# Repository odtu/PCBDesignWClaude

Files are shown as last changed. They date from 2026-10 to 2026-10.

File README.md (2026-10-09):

# PCBDesignWClaude: Inductive Absolute Encoder (branch `inductive-encoder`)

This branch holds a separate KiCad project from `main` (the 3-phase ESC): a contactless **absolute inductive rotary encoder**. It was designed with Claude Code and the PowerLab KiCad Assistant, after TI's **TIDA-010961** reference design ([TIDUFF8](https://www.ti.com/lit/pdf/tiduff8)).

- **Sensing:** dual-track Nonius coils, 16 and 15 periods, in a Ø58 mm coil area. The absolute angle comes from the phase difference between the two tracks.
- **Electronics:** 2 × LDC5072-Q1 inductive front ends, 2 × TLV9062 op-amps, an MSPM0G3507 MCU (both ADCs sample simultaneously) and a REF35330 3.3 V reference.
- **Power and interface:** 12–24 V input to an LMR51610 buck, then the TPS70950 and TPS70933 LDOs. The host connection carries UART at 2.5 Mbaud, SYNC and SWD.
- **Rules and parts:** the design follows the [METU PowerLab PCB design rules](https://github.com/odtu/Powerlab/blob/master/KiCAD/PCB_DESIGN_RULES.md) and uses parts from [PowerLabKiCadLibraries](https://github.com/odtu/PowerLabKiCadLibraries).

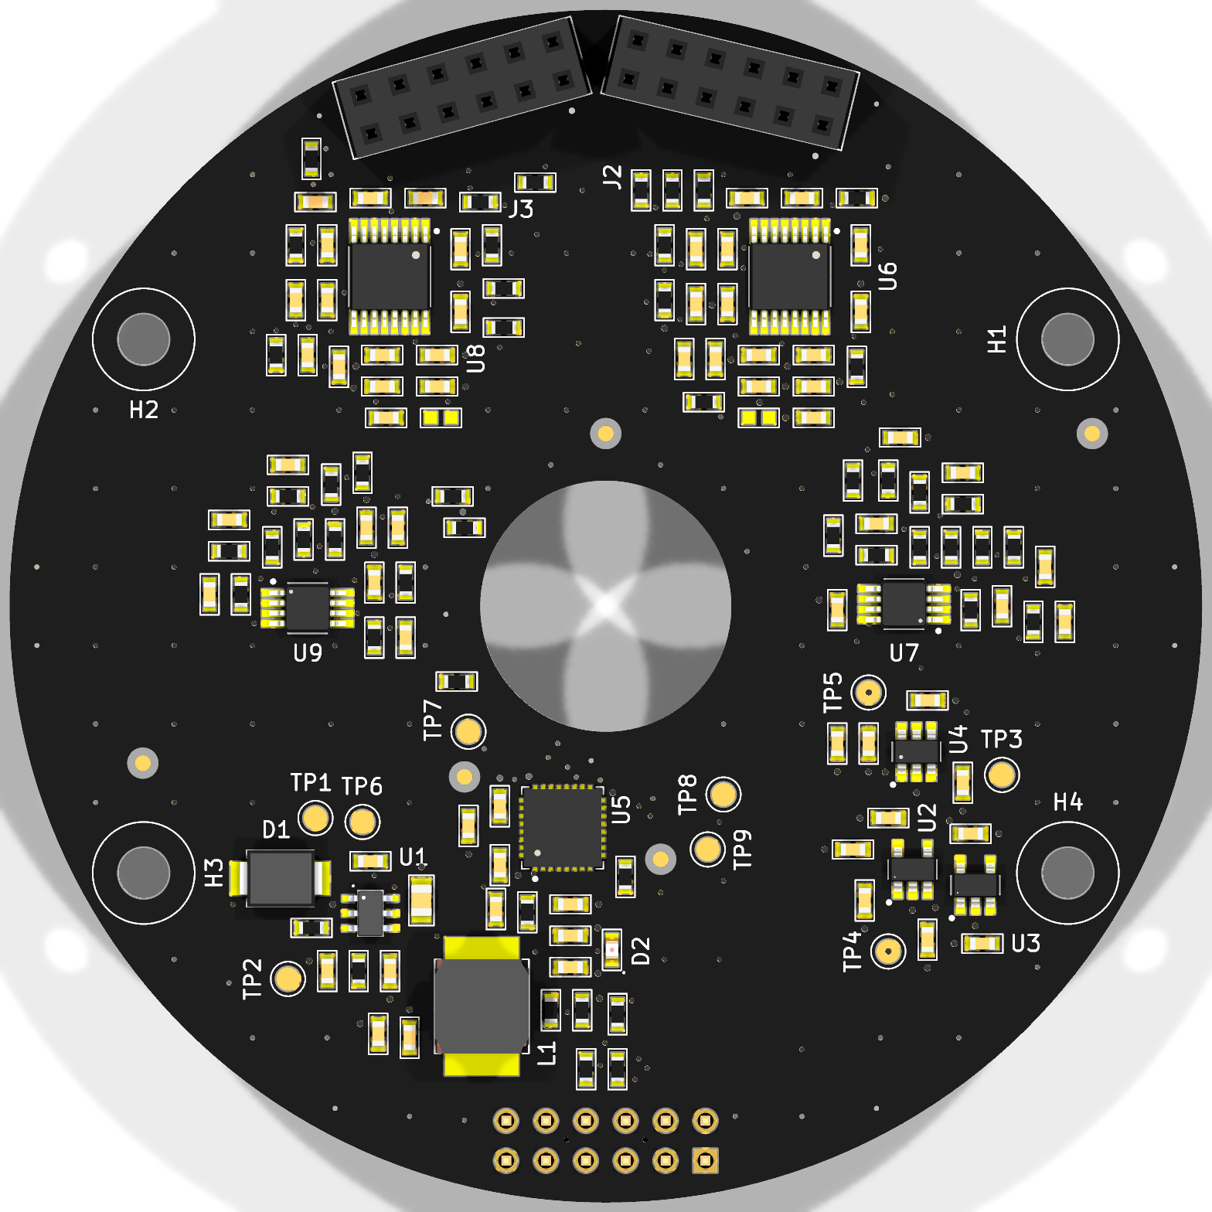
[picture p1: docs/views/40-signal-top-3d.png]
Signal board, top


## Boards

The stack is the same as TI's: the target, a 0.5 mm air gap, the stator, then the 2×6 board-to-board headers, then the signal board.

| Board | Files | |
|---|---|---|
| Stator (coil board) | `InductiveEncoder.kicad_pro` | Ø76 mm, 4 layers. Generated coils, net ties, J2/J3 male headers on the bottom. No GND copper, so nothing acts as a shorted turn. |
| Signal board | `signal/EncoderSignal.kicad_pro` | Ø76 mm, 4 layers, the same M3 holes. All electronics. J2/J3 sockets on top, J1 host connector on the bottom. |
| Target | `target/EncoderTarget.kicad_pcb` | Ø56 mm, 2 layers, copper segments. It rotates with the shaft. |

## Status

- **Schematics:**
  - Hierarchical, on the PowerLab drawing sheet.
  - ERC: 0 errors.
  - PDFs: [docs/schematic_signal.pdf](docs/schematic_signal.pdf), [docs/schematic_stator.pdf](docs/schematic_stator.pdf).
- **Boards:**
  - DRC on both: 0 errors, 0 unconnected, 0 schematic-parity issues.
  - Remaining warnings: footprint-library mismatches (mask bridges allowed inside the fine-pitch ICs), one J1 silk circle near the edge, one narrow pour neck.
- **Fab outputs** in [fab/](fab/): Gerber and drill zip, BOM, position file and assembly drawings for each board.
- **Routing:**
  - The signal-board routing was reworked after [odtu/PowerLabKiCadAssistant#21](https://github.com/odtu/PowerLabKiCadAssistant/issues/21).
  - The resulting rules are proposed in odtu/Powerlab#147 and odtu/PowerLabKiCadAssistant#22. See "How the signal board was routed" below.

Before ordering:
- Add teardrops (Edit → Edit Teardrops; KiCad has no scripting API for them), then rerun `tools/fab_outputs.py`.
- Set the project number (`${PROJECTNUMBER}` is `TBD` in `tools/lab_setup.py`).
- Replace C4/C5 (22 µF 0603, 10 V) on the 6.1 V rail with 16–25 V parts. At 6.1 V they lose most of their capacitance to DC bias.
- The round boards need a panel for PCBWay assembly.
- There's no reverse-polarity protection: use a keyed cable.
- Firmware isn't part of this project.

## How the signal board was routed

`tools/route_signal.py` runs this chain on the placed board:

1. **`fanout.py`:**
   - **GND:** the pours connect the GND pads. A via goes at the pad only for decoupling caps and fine-pitch IC GND pins. Pads the pour can't reach got a via after routing.
   - **Fine-pitch power pins:** 0.25 mm neck-downs.
   - **Escape lanes:** kept free in front of fine-pitch pins.
2. **`power_route.py`:** the rails come first, at the 0.5 mm Power class width. Freerouting 2.4.1 ignores net-class widths.
3. **`autoroute.py signal`:** Freerouting 2.4.1 (Java 25) routes the signals. GND and the rails are keepouts, and the In1 GND plane is a plane layer.
4. **`maze_route.py`:** a grid A* router finishes what is still open. `ripup.py` frees a congested pin row first when needed.
5. **`track_opt.py`:**
   - Shortcuts detours with 45° segments and chamfers every corner of 90° or less.
   - Ends tracks straight at the pad centre.
   - Removes stubs and duplicates.
   - Widens Power/GND tracks to class width, with a 0.15 mm minimum for everything.

Afterwards, the finishing scripts add the rest:
- `zones.py signal`: the GND pours, slotted at 90° so they don't form a closed ring around the shaft;
- `lab_extras.py`: the stitching vias, the local fiducials at the MCU and the J1 labels;
- `silk.py` and `board_info.py`: the silkscreen and the board info.

The whole regeneration sequence, from coils and schematics to fab outputs, is in [docs/DESIGN_NOTES.md](docs/DESIGN_NOTES.md#regenerating).

## Repository layout

```
InductiveEncoder.kicad_*      stator project (root sheet + coils.kicad_sch)
signal/                       signal-board project (7 sheets)
target/                       target disc
tools/                        Python generators and layout/routing scripts (KiCad 10 python / system python)
fab/<board>/                  ordering files (Gerber+drill zip, BOM, pos, assembly PDFs)
docs/                         schematic PDFs, views, design notes
METUPowerLab_KiCadSchematicTemplate.kicad_wks   lab drawing sheet (also in signal/)
```

## Opening and regenerating

- **KiCad 10.**
  - The schematics and boards carry embedded copies of every symbol and footprint, so the project opens without extra libraries.
  - The new parts are in [odtu/PowerLabKiCadLibraries#13](https://github.com/odtu/PowerLabKiCadLibraries/pull/13): LDC5072, MSPM0G3507, TLV9062, REF35330, TPS709xx, the 2×6 header and socket, and some passives. That PR is not merged yet.
- **Generated files:** the `.kicad_sch` files are generated by `tools/encoder_circuit.py`, and the stator coils by `tools/coilgen.py`. Edit the scripts, not the generated sheets.
- **Tool paths:** some scripts have local paths you'll need to change on another machine:
  - the KiCad install, `C:/Program Files/KiCad/10.0`;
  - the PowerLab library and Assistant folders, used for logos, fiducials, Java 25 and Freerouting.

## License

See [license.txt](license.txt) (same as `main`).

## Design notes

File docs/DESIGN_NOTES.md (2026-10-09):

# Inductive Absolute Encoder (rev A): design notes

Paths below are relative to the repository root.

Contactless absolute rotary encoder after TI **TIDA-010961** ([TIDUFF8](https://www.ti.com/lit/pdf/tiduff8)),
built with METU PowerLab library parts. There are three PCBs, like the TI reference:

| Board | Project | What's on it |
|---|---|---|
| **Stator (coil board)** | `InductiveEncoder.kicad_pro` (this folder) | Ø76 mm, 4 layers. Dual-track coils, 6 net ties, J2/J3 2×6 male headers on the bottom at the coil exits. No other parts and no GND pour (no shorted turn). |
| **Signal board** | `signal/EncoderSignal.kicad_pro` | Ø76 mm, 4 layers, same outline and M3 holes. 2 × LDC5072, 2 × TLV9062, MSPM0G3507, power, J1 host connector. J2/J3 sockets on the top mate with the stator headers. |
| **Target** | `target/EncoderTarget.kicad_pcb` | Ø56 mm, 2 layers. Copper segments (16 + 15) on both layers, rotates 0.5 mm (max ~1.2 mm) above the stator top. |

**Stack:** target → 0.5 mm air gap → stator (coils on L1 facing the target) → J2/J3 header + socket (~11 mm, WR-PHD 8.5 mm socket + header) → signal board.
All three boards share the Ø16 mm shaft hole. Stator and signal board share 4 × M3 NPTH at r = 34 mm (30/150/210/330°), so one set of standoffs holds both.

| | |
|---|---|
| AFE | 2 × LDC5072-Q1 (5 V supply mode, AGC), each with TLV9062 diff-to-single-ended (G = 0.51, 1.65 V bias) |
| MCU | MSPM0G3507 (VQFN-32): SIN on ADC0, COS on ADC1 of each track → simultaneous sampling; VREF+ = REF35330 (3.3 V) |
| Power | 12–24 V → LMR51610X buck (6.12 V, 400 kHz, 33 µH) → TPS70950 (+5V_AFE) / TPS70933 (+3V3_SYS) |
| Host interface | J1 2×6 2.54 mm (signal board, bottom): +VIN ×2, GND ×3, UART RX/TX (2.5 Mbaud), SYNC, NRST, SWDIO, SWCLK, +3V3 (VTref) |
| Coil connectors | J2: EXC1 (pins 1/2), SIN1 (5/6), SIN2 (9/10). J3: COS1 (1/2), COS2 (5/6), EXC2 (9/10). Pins 3/4, 7/8, 11/12 are GND, shielding the pairs. |

## Coil design (`tools/coilgen.py`)

| | Outer track | Inner track |
|---|---|---|
| Periods | 16 | 15 |
| Mean radius / amplitude | 24.0 / 2.8 mm | 13.9 / 2.8 mm |
| Receive band | r 21.2 – 26.8 mm | r 11.1 – 16.7 mm |
| Excitation ring | r 27.7 – 29.1 mm, 3 turns/layer on L1+L2, **5.8 µH** | r 18.1 – 20.3 mm, 5 turns/layer, **8.8 µH** |
| Tank (C1 = C2, signal board) | 390 pF C0G → **~4.7 MHz** | 390 pF C0G → **~3.85 MHz** |

- Different tank frequencies keep the two LDC5072 oscillators from beating into each other (LDC5072 range 2.4–5 MHz).
- **Layer plan:** receive coils on L1/L2, closest to the target. SIN uses L1 for its outer half and L2 for its inner half; COS is the other way round, so a SIN trace only ever meets a COS trace on the other layer. Layer changes use 0.3/0.6 mm vias just after each self-crossing.
- **Leads:** run radially on L3 (P) and L4 (N) in lanes midway between the via columns. COS coils are fed at their 270° crossing so no feed turnaround via sits inside a lead lane.
- **Net ties:** each coil plus both leads is one net (`SIN1_P`, `EXC1_A`, …). The coil's net tie sits on its N lead and joins it to the `_N`/`_B` net. That's why the coil terminals are **hand-routed** to J2/J3 (`tools/stator_layout.py`): an autorouter can't tell the two lead ends apart.
- **No closed copper loop around the coils:** the stator has no GND pour. The signal-board GND pours are slotted at 90° so they don't form a shorted turn around the axis.
- **Inductance:** coil inductance is computed with a filament model (`tools/inductance.py`). Measure the real tank frequency on LCIN and trim C24/C25, C46/C47 if needed.

## Regenerating

```bash
python -I tools/lab_setup.py                   # drawing sheet, title-block text variables, net-class colours
python -I tools/coilgen.py                     # stator coils (text-edits the board; re-runnable)
python -I tools/coilgen.py --target            # target disc
python -I tools/check_sch.py                   # both schematics from tools/encoder_circuit.py + ERC + PDFs
python -I tools/lint_sch_pdf.py docs/schematic_signal.pdf docs/schematic_stator.pdf   # no overlapping text
python -I tools/stator_layout.py strip         # then KiCad python: stator_layout.py build (headers, net ties, coil routes)
"C:/Program Files/KiCad/10.0/bin/python.exe" tools/signal_place.py    # signal-board placement
"C:/Program Files/KiCad/10.0/bin/python.exe" tools/sync_fields.py stator|signal  # symbol fields, pad nets -> footprints
python -I tools/route_signal.py                # signal-board routing chain (see "Signal-board routing")
"C:/Program Files/KiCad/10.0/bin/python.exe" tools/zones.py signal    # slotted GND pours (after routing)
"C:/Program Files/KiCad/10.0/bin/python.exe" tools/lab_extras.py      # U5 local fiducials, GND stitching vias, J1 labels
"C:/Program Files/KiCad/10.0/bin/python.exe" tools/board_info.py      # logo, QR, project/rev/date/designer texts
"C:/Program Files/KiCad/10.0/bin/python.exe" tools/silk.py <board>    # reference placement (both boards)
python -I tools/fab_outputs.py                 # fab/<board>/: gerbers+drill zip, BOM, pos, assembly drawings
```

### Signal-board routing (odtu/PowerLabKiCadAssistant issue #21)

`tools/route_signal.py` strips the tracks and runs the chain below.

1. **`fanout.py`:**
   - **GND:** the GND pours connect the GND pads; there are no GND tracks between pads. A via to the In1 plane goes only:
     - at each decoupling cap's GND pad (0.4/0.8 mm, lab rule 3.2);
     - at fine-pitch IC GND pins;
     - on the 8 pads the pour can't reach because tracks box them in. These were added after routing, where DRC showed the pad unconnected.
   - **Fine-pitch power/GND pins:** they get 0.25 mm neck-downs. MCU GND pins join the exposed pad.
   - **Escape lanes:** fan-out vias stay out of a 1.5 mm lane in front of every fine-pitch pin.
   - **Power pin groups:** they get local copper when no pad of another net lies inside the group (here only +5V_AFE at U2/C8/C9).
2. **`power_route.py`:** the rails come first (lab routing order), at their 0.5 mm class width. Freerouting 2.4.1 ignores net-class widths, so the rails aren't left to it.
3. **`autoroute.py signal`:**
   - Freerouting routes the signals only.
   - GND and the rails go in as keepouts, so it can't draw GND tracks or route over the fan-out.
   - In1 is a plane layer, so no signal routes on it.
4. **`maze_route.py`:** routes what is still open, starting from the IC pin.
   - It keeps escape lanes free and doesn't route under fine-pitch ICs.
   - `ripup.py` frees a congested pin row when needed.
5. **`track_opt.py`:**
   - Shortcuts detours with straight or 45° segments.
   - Ends every track straight at the pad centre, so no edge-grazing ends or pour slivers.
   - Chamfers every corner of 90° or less.
   - Removes stubs and duplicates.
   - Widens Power/GND to 0.5 mm where clearance allows; nothing is narrower than 0.15 mm.

**Result:**
- **Widths:** +VIN, +6V_BUCK and +5V_AFE are 100 % at 0.5 mm. +3V3_REF and +3V3_MCU are 0.5 mm apart from the 0.25 mm pin neck-downs; +3V3_SYS is 70 % at 0.5 mm and 0.3–0.4 mm in tight spots.
- **GND:** GND tracks are only the short stubs from decoupling caps and IC pins to their vias.
- **Corners:** no corner of 90° or less outside pads and vias.
- **Track length:** −10 % compared with the raw routing.

**Layout changes made for routing** (no functional change):
- SIN1 moved from PA27/A0_0 (pin 31) to PA14/A0_12 (pin 18), next to COS1; it is still on ADC0 for simultaneous sampling.
- The MCU block (U5, C17–C23, R6, R7, R9, FB1, D2) moved 1.5 mm away from the shaft hole. Its top pin row had only 1.2 mm of room to escape.
- TP8/TP9 moved 4–5 mm away from the MCU's right pin row.

> **Warning:** the schematic `.kicad_sch` files are **generated**. Edit `tools/encoder_circuit.py`, not the sheets,
> or stop regenerating once you start editing by hand. The same applies to the layout scripts: re-running them moves parts and reroutes.
> Symbol UUIDs are stable, so regenerating keeps the board links.

## Library

New parts (LDC5072EPWRQ1, MSPM0G3507SRHBR, TLV9062IDGKR, REF35330QDBVR, TPS70933/50DBVR, 2×6 header, 2×6 socket,
100 pF/390 pF/470 nF caps, 4.7 Ω, 100 kΩ 0.1 %) are in [odtu/PowerLabKiCadLibraries#13](https://github.com/odtu/PowerLabKiCadLibraries/pull/13)
(branch `library/inductive-encoder-parts`, not merged yet).
The schematics and boards carry embedded copies of every symbol and footprint, so the project opens without
them. To update parts from the library, add the PowerLabKiCadLibraries release that contains these parts.

## Lab rules (odtu/Powerlab `KiCAD/PCB_DESIGN_RULES.md`)

Checked against the lab-specific file (origin/master, 2026-10-09).

- **Schematics:**
  - Every sheet uses the METU PowerLab drawing sheet (copied next to each project, relative path).
  - The title-block variables `${PROJECT_NAME}`, `${DESIGNER}` and `${PROJECTNUMBER}` are project text variables.
  - GND nets are drawn blue and Power nets red, both 0.3 mm. There is no overlapping text (`lint_sch_pdf.py`).
  - ERC: 0 errors.
- **Boards:**
  - Board minimums are at the PCBWay 0.15 mm floor. Board-level mask expansion is 0.05 mm and the minimum web 0.1 mm.
  - References sit at 1.0 / 0.15 mm, off pads and outside part bodies.
  - The local fiducial pair FID4/FID5 sits diagonally across U5 (0.5 mm pitch).
  - GND stitching vias run on a 5 mm grid.
  - The board info uses text variables. J1 carries voltage and pin labels.
  - Both boards: DRC 0 errors, 0 unconnected, 0 parity issues.

### Deviations (documented)

- **4 layers** on both stator and signal board (approved by the user).
- **Power/GND net classes:** 0.5 mm tracks and 0.4/0.8 mm vias as in the lab table, but 0.2 mm clearance instead of 0.3 mm. All nets are below 30 V; IPC-2221 asks for 0.1 mm.
  - Neck-downs to 0.25 mm sit only at fine-pitch pins.
  - Some +3V3_SYS sections are 0.3–0.4 mm where the op-amp area leaves no room (rails carry < 0.2 A).
  - Fan-out vias at fine-pitch pins are 0.3/0.6 mm.
- **`*.kicad_dru`:** allows 0.15 mm pad-to-pad clearance inside each fine-pitch IC (TSSOP/VSSOP/VQFN pin gaps are 0.20–0.25 mm).
- **Solder-mask bridges allowed inside U1–U9:** the 0.1 mm mask margin in these library footprints merges the fine-pitch apertures (9 `lib_footprint_mismatch` warnings). Consider giving these library footprints a smaller margin.
- **Minimum thermal spokes = 1** (`min_resolved_spokes`): some GND pads are boxed in by tracks.
- **Passive references on the Fab layer:** 0603 parts sit 0.5–1 mm apart, too close for 1.0 mm silk text. They are on the assembly drawings in `fab/`.
- **Local fiducials 8–9 mm from U5:** the nearest free 3 mm keepout spots.
- **J1 pin-1 silk circle** sits 0.2 mm from the round edge (1 `silk_edge_clearance` warning, library graphic).
- **Round boards:** PCBWay assembly needs a panel with breakaway rails (panelization by the user).
- **No reverse-polarity protection** on +VIN (only a bidirectional TVS): use a keyed cable.
- **No test points on the SIN/COS ADC nets:** probe the anti-alias capacitors (C42/C45, C64/C67) instead. Supplies, GND, BSL and TEST_A/B have test points; UART, SYNC, NRST and SWD are on J1.

## Open items before ordering

- **Teardrops (rule 3.3):** KiCad 10 has no scripting API for them. Open each board, run *Edit → Edit Teardrops → Add teardrops* (pads and vias), refill zones (B), save, then re-run `tools/fab_outputs.py`.
- **`${PROJECTNUMBER}`** is `TBD` in `tools/lab_setup.py`: set the lab project number.
- **C4/C5** (22 µF 0603, 10 V X5R) on the 6.1 V buck output lose most of their capacitance to DC bias. A 16–25 V part in 0805/1206 is safer. This needs a library part.
- Verify the coil/target dimensions and the board-to-board stack height against your motor's mechanics.
- **Firmware isn't part of this project.** It covers ADC sampling at 32 kHz with 8× oversampling, offset/gain calibration, Nonius sector computation (TIDUFF8 §3.2) and UART protocol.
- Measure the tank frequency and coil Q on the first board.
- Print both boards 1:1 and check footprints; check the Gerbers in the Gerber viewer.

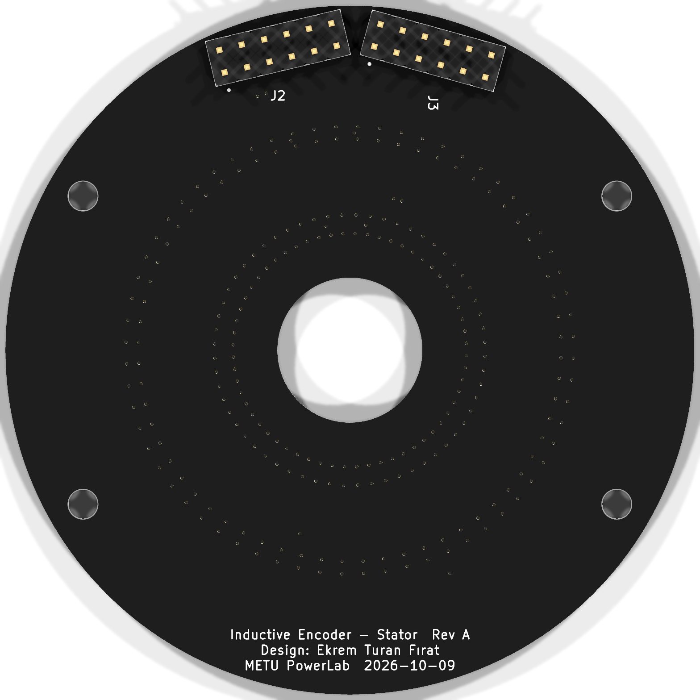
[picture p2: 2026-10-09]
docs/views/42-stator-bottom-3d.png

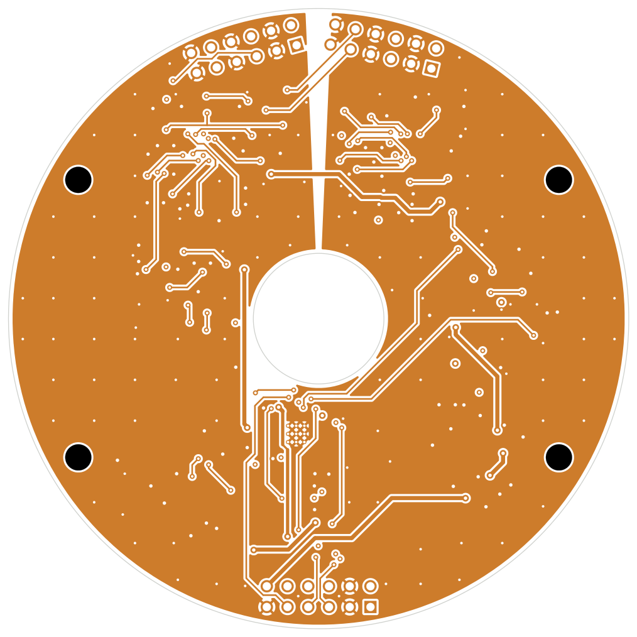
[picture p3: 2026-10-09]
docs/views/50-signal-In2.png

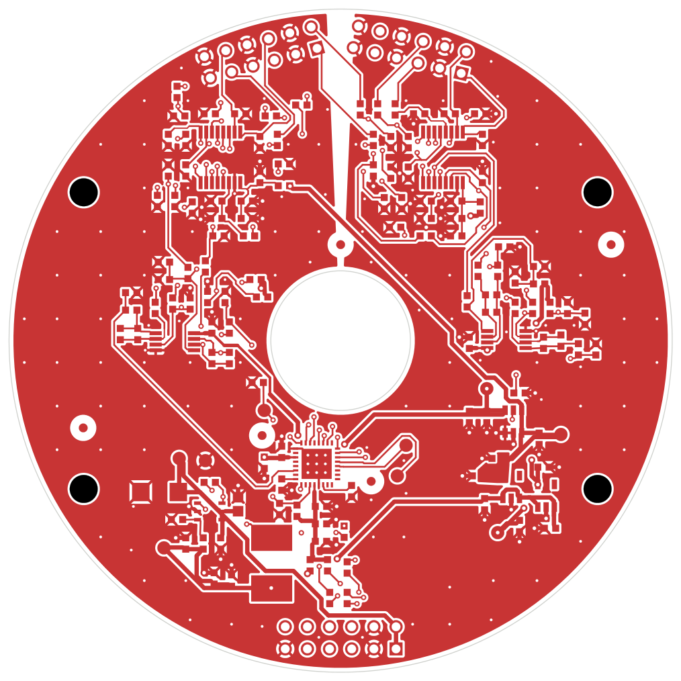
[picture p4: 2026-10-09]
docs/views/50-signal-F.png

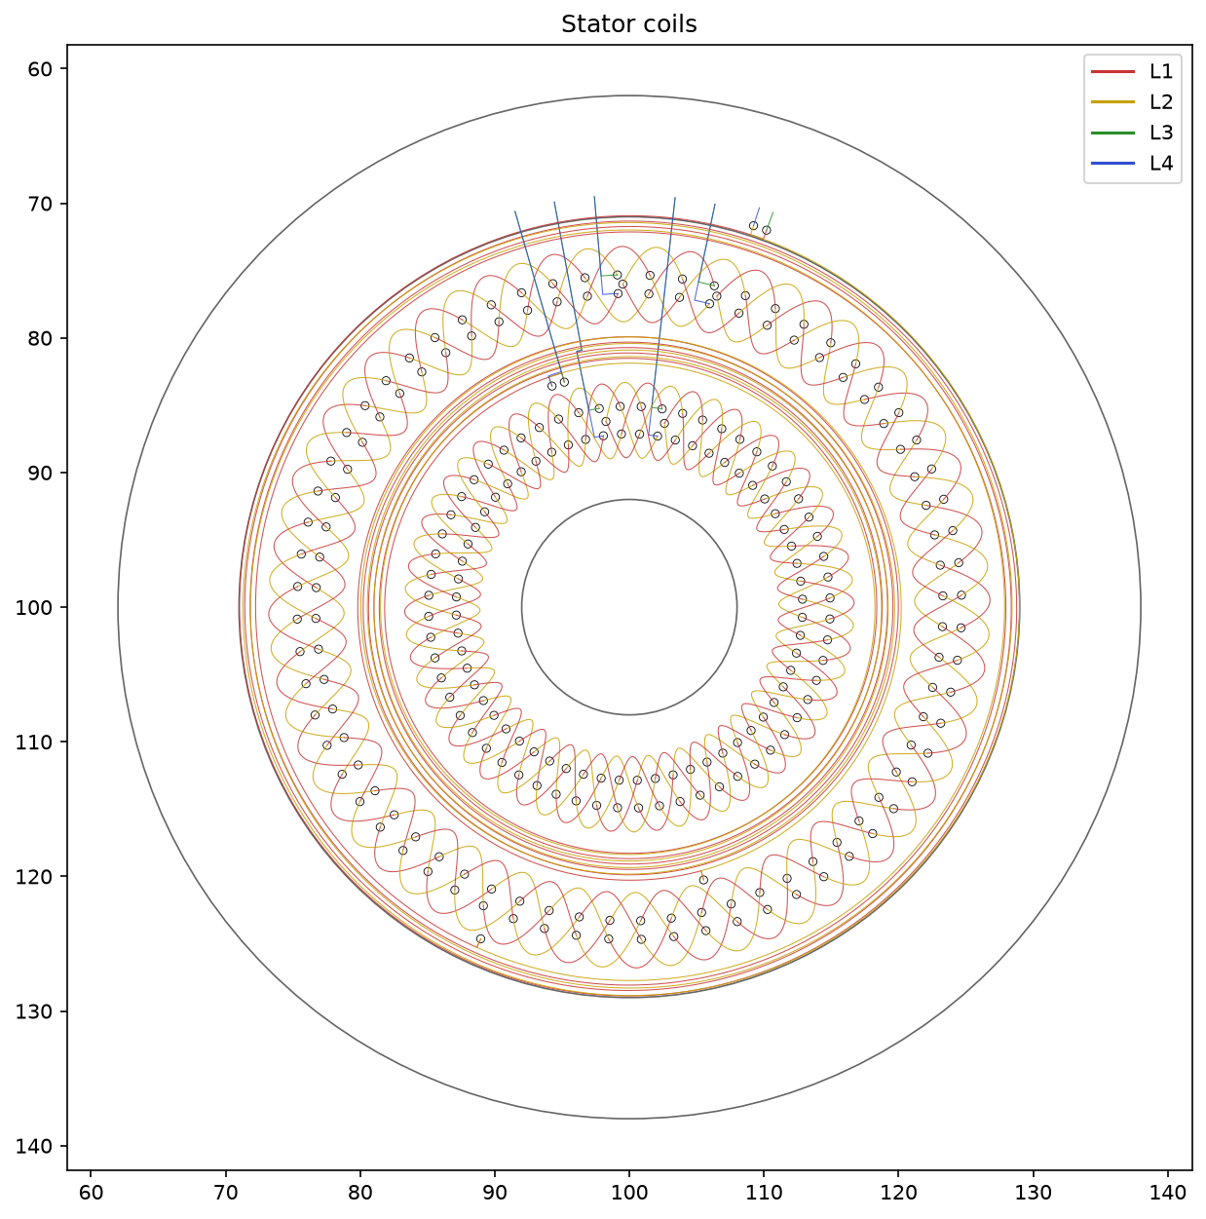
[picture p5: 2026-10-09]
docs/coils_preview.png

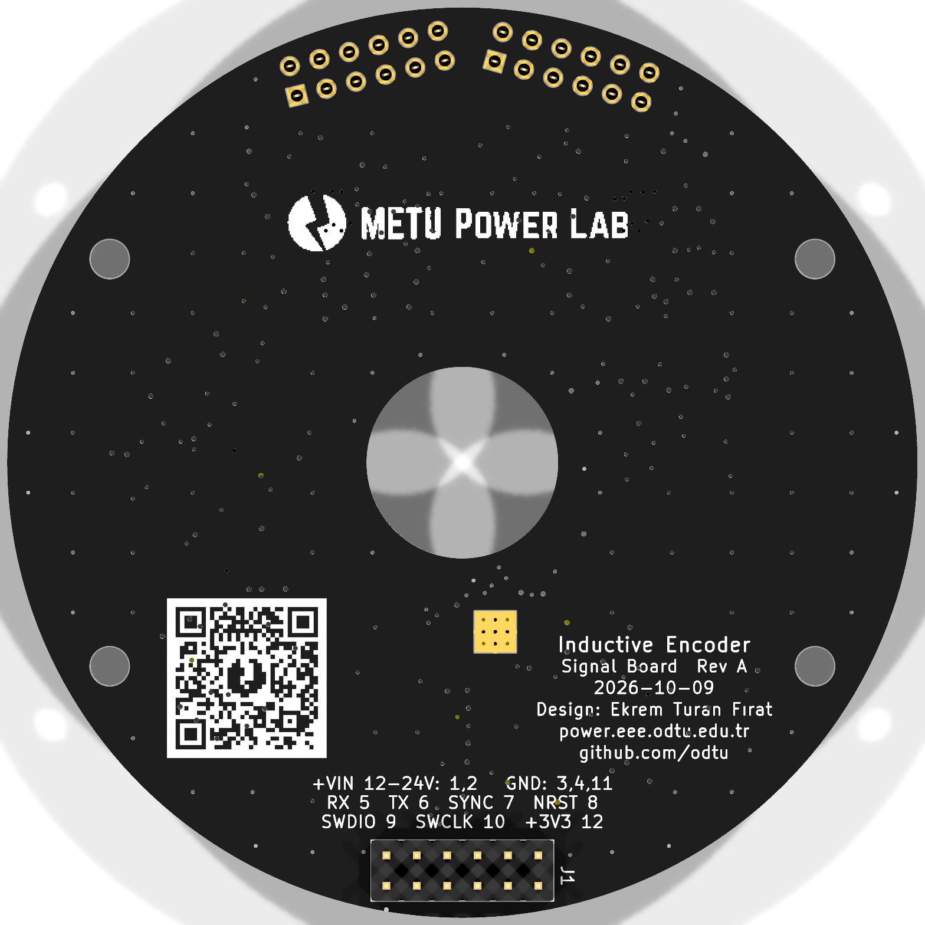
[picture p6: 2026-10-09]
docs/views/41-signal-bottom-3d.png

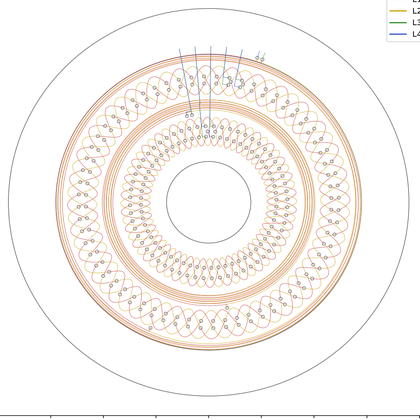
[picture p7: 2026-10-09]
docs/coils_preview_small.png

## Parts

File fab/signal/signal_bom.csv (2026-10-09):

Designator | Qty | Value | Manufacturer | MPN | Package | Mounting | Footprint
C1 | 1 | 2.2 µF | Murata Electronics | GRM21BD72A225ME01K | 0805 (2012Metric) | Surface Mount | METUPowerLab_Capacitors_Ceramics_SurfaceMounts:0805_Medium
C2 | 1 | 100 nF | Samsung Electro-Mechanics | CL10B104KC8NNNC | 0603 (1608 Metric) | Surface Mount | METUPowerLab_Capacitors_Ceramics_SurfaceMounts:0603_Medium
C3,C9,C12-C14,C16,C19,C23,C31,C39,C53,C61 | 12 | 100 nF | YAGEO | CC0603KRX7R7BB104 | 0603 (1608 Metric) | Surface Mount | METUPowerLab_Capacitors_Ceramics_SurfaceMounts:0603_Medium
C4,C5 | 2 | 22 µF | Samsung Electro-Mechanics | CL10A226MP8NUNE | 0603 (1608 Metric) | Surface Mount | METUPowerLab_Capacitors_Ceramics_SurfaceMounts:0603_Medium
C6,C8,C11,C17 | 4 | 10 µF | Samsung Electro-Mechanics | CL10A106MA8NRNC | 0603 (1608 Metric) | Surface Mount | METUPowerLab_Capacitors_Ceramics_SurfaceMounts:0603_Medium
C7,C10,C15,C18,C22,C30,C33,C52,C55 | 9 | 1 µF | Samsung Electro-Mechanics | CL10B105KP8NNNC | 1210 (3225 Metric) | Surface Mount | METUPowerLab_Capacitors_Ceramics_SurfaceMounts:0603_Medium
C20 | 1 | 470 nF | Murata Electronics | GRM188R71E474KA12D | 0603 (1608 Metric) | Surface Mount | METUPowerLab_Capacitors_Ceramics_SurfaceMounts:0603_Medium
C21,C35-C38,C57-C60 | 9 | 10 nF | Samsung Electro-Mechanics | CL10B103KB8NNNC | 0603 (1608 Metric) | Surface Mount | METUPowerLab_Capacitors_Ceramics_SurfaceMounts:0603_Medium
C24,C25,C46,C47 | 4 | 390 pF | Murata Electronics | GCM1885C1H391JA16D | 0603 (1608 Metric) | Surface Mount | METUPowerLab_Capacitors_Ceramics_SurfaceMounts:0603_Medium
C26-C29,C48-C51 | 8 | 220 pF | Samsung Electro-Mechanics | CL10B221JB8NNNC | 0603 (1608 Metric) | Surface Mount | METUPowerLab_Capacitors_Ceramics_SurfaceMounts:0603_Medium
C32,C34,C42,C45,C54,C56,C64,C67 | 8 | 1 nF | Murata Electronics | GCM1885C2A102JA16D | 0603 (1608Metric) | Surface Mount | METUPowerLab_Capacitors_Ceramics_SurfaceMounts:0603_Medium
C40,C43,C62,C65 | 4 | 22 pF | Samsung Electro-Mechanics | CL10C220JB8NFNC | 0603 (1608 Metric) | Surface Mount | METUPowerLab_Capacitors_Ceramics_SurfaceMounts:0603_Medium
C41,C44,C63,C66 | 4 | 12 pF | Samsung Electro-Mechanics | CL10C120JC81PNC | 0603 (1608 Metric) | Surface Mount | METUPowerLab_Capacitors_Ceramics_SurfaceMounts:0603_Medium
D1 | 1 | SMBJ36CA-13-F | Diodes Incorporated | SMBJ36CA-13-F | DO-214AA (SMB) | Surface Mount | METUPowerLab_Diodes_TVSDiodes:DO-214AA
D2 | 1 | Green | Würth Elektronik | 150060GS75000 | 0603 (1608 Metric) | Surface Mount | METUPowerLab_LEDs_SurfaceMounts:0603_Medium
FB1-FB3 | 3 | BLM18EG221SN1D | Murata Electronics | BLM18EG221SN1D | 0603 (1608 Metric) | Surface Mount | METUPowerLab_CircuitProtections_FerriteBeads:0603_Medium
J1 | 1 | 2x6 | Würth Elektronik | 61301221121 |  | Through Hole | METUPowerLab_Connectors_Headers:61301221121
J2,J3 | 2 | 2x6 Female | Würth Elektronik | 61301221821 |  | Through Hole | METUPowerLab_Connectors_Headers:61301221821
L1 | 1 | 33µH | Würth Elektronik | 74404063330 | 6x6x2.8mm | Surface Mount | METUPowerLab_Inductors_SurfaceMounts:6x6mm
R1 | 1 | 147 kOhm | Stackpole Electronics Inc | RMCF0603FT147K | 0603 (1608 Metric) | Surface Mount | METUPowerLab_Resistors_ChipResistors:0603_Medium
R2 | 1 | 22.1 kOhm | Stackpole Electronics Inc | RMCF0603FT22K1 | 0603 (1608 Metric) | Surface Mount | METUPowerLab_Resistors_ChipResistors:0603_Medium
R3-R5 | 3 | 22 Ohm | Stackpole Electronics Inc | RMCF0603FT22R0 | 0603 (1608 Metric) | Surface Mount | METUPowerLab_Resistors_ChipResistors:0603_Medium
R6,R8 | 2 | 47 kOhm | Stackpole Electronics Inc | RMCF0603FT47K0 | 0603 (1608 Metric) | Surface Mount | METUPowerLab_Resistors_ChipResistors:0603_Medium
R7 | 1 | 100 kOhm | YAGEO | RT0603BRD07100KL | 0603 (1608 Metric) | Surface Mount | METUPowerLab_Resistors_ChipResistors:0603_Medium
R9 | 1 | 1 kOhm | Stackpole Electronics Inc | RMCF0603FT1K00 | 0603 (1608 Metric) | Surface Mount | METUPowerLab_Resistors_ChipResistors:0603_Medium
R10-R13,R30-R33 | 8 | 120 Ohm | Stackpole Electronics Inc | RMCF0603FT120R | 0603 (1608 Metric) | Surface Mount | METUPowerLab_Resistors_ChipResistors:0603_Medium
R14,R15,R18,R20-R22,R24,R26-R28,R34,R35,R38,R40-R42,R44,R46-R48 | 20 | 10 kOhm | YAGEO | RC0603FR-0710KL | 0603 (1608 Metric) | Surface Mount | METUPowerLab_Resistors_ChipResistors:0603_Medium
R16,R36 | 2 | 1.5 kOhm | Stackpole Electronics Inc | RMCF0603FT1K50 | 0603 (1608 Metric) | Surface Mount | METUPowerLab_Resistors_ChipResistors:0603_Medium
R19,R25,R39,R45 | 4 | 5.1 kOhm | Stackpole Electronics Inc | RMCF0603FT5K10 | 0603 (1608 Metric) | Surface Mount | METUPowerLab_Resistors_ChipResistors:0603_Medium
R23,R29,R43,R49 | 4 | 100 Ohm | YAGEO | RC0603FR-07100RL | 0603 (1608 Metric) | Surface Mount | METUPowerLab_Resistors_ChipResistors:0603_Medium
U1 | 1 | LMR51610XDBVR | Texas Instruments | LMR51610XDBVR | SOT-23-6 | Surface Mount | METUPowerLab_Regulators_BuckConverters:SOT-23-6
U2 | 1 | TPS70950DBVR | Texas Instruments | TPS70950DBVR | SOT-23-5 | Surface Mount | METUPowerLab_Regulators_LDOs:SOT-23-5_DBV
U3 | 1 | TPS70933DBVR | Texas Instruments | TPS70933DBVR | SOT-23-5 | Surface Mount | METUPowerLab_Regulators_LDOs:SOT-23-5_DBV
U4 | 1 | REF35330QDBVR | Texas Instruments | REF35330QDBVR | SOT-23-6 | Surface Mount | METUPowerLab_References_VoltageReferences:SOT-23-6_DBV
U5 | 1 | MSPM0G3507SRHBR | Texas Instruments | MSPM0G3507SRHBR | 32-VQFN | Surface Mount | METUPowerLab_Microcontrollers_MSPM0:VQFN-32_RHB
U6,U8 | 2 | LDC5072EPWRQ1 | Texas Instruments | LDC5072EPWRQ1 | 16-TSSOP | Surface Mount | METUPowerLab_Sensors_Encoders:TSSOP-16_PW
U7,U9 | 2 | TLV9062IDGKR | Texas Instruments | TLV9062IDGKR | 8-VSSOP | Surface Mount | METUPowerLab_Amplifiers_OpAmps:VSSOP-8_DGK

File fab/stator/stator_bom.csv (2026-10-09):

Designator | Qty | Value | Manufacturer | MPN | Package | Mounting | Footprint
J2,J3 | 2 | 2x6 | Würth Elektronik | 61301221121 |  | Through Hole | METUPowerLab_Connectors_Headers:61301221121

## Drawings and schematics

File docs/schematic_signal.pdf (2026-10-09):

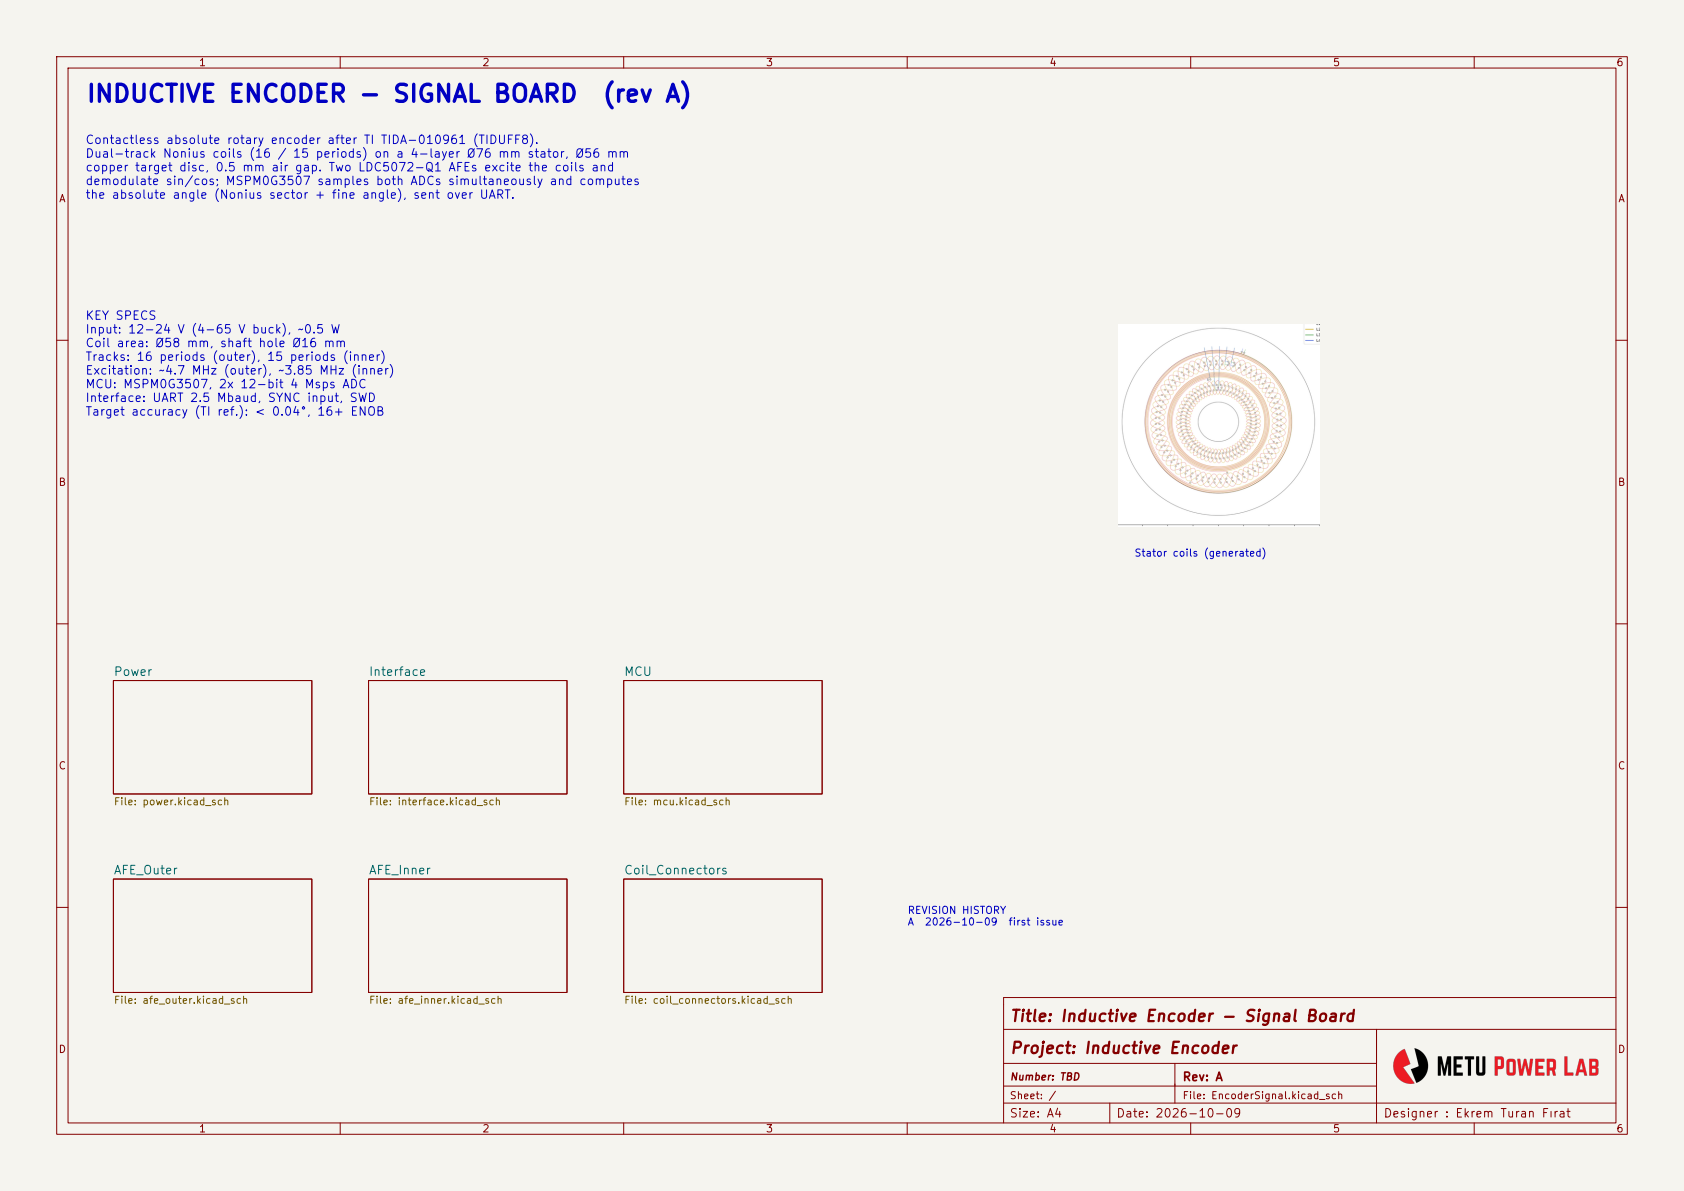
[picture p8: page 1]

INDUCTIVE ENCODER - SIGNAL BOARD (rev A)

Contactless absolute rotary encoder after TI TIDA-010961 (TIDUFF8).
Dual-track Nonius coils (16 / 15 periods) on a 4-layer Ø76 mm stator, Ø56 mm
copper target disc, 0.5 mm air gap. Two LDC5072-Q1 AFEs excite the coils and
demodulate sin/cos; MSPM0G3507 samples both ADCs simultaneously and computes
the absolute angle (Nonius sector + fine angle), sent over UART.

KEY SPECS
Input: 12-24 V (4-65 V buck), ~0.5 W
Coil area: Ø58 mm, shaft hole Ø16 mm
Tracks: 16 periods (outer), 15 periods (inner)
Excitation: ~4.7 MHz (outer), ~3.85 MHz (inner)
MCU: MSPM0G3507, 2x 12-bit 4 Msps ADC
Interface: UART 2.5 Mbaud, SYNC input, SWD
Target accuracy (TI ref.): < 0.04°, 16+ ENOB

File: coil_connectors.kicad_sch Power File: power.kicad_sch

Project: Inductive Encoder Number: TBD MCU

Title: Inductive Encoder - Signal Board

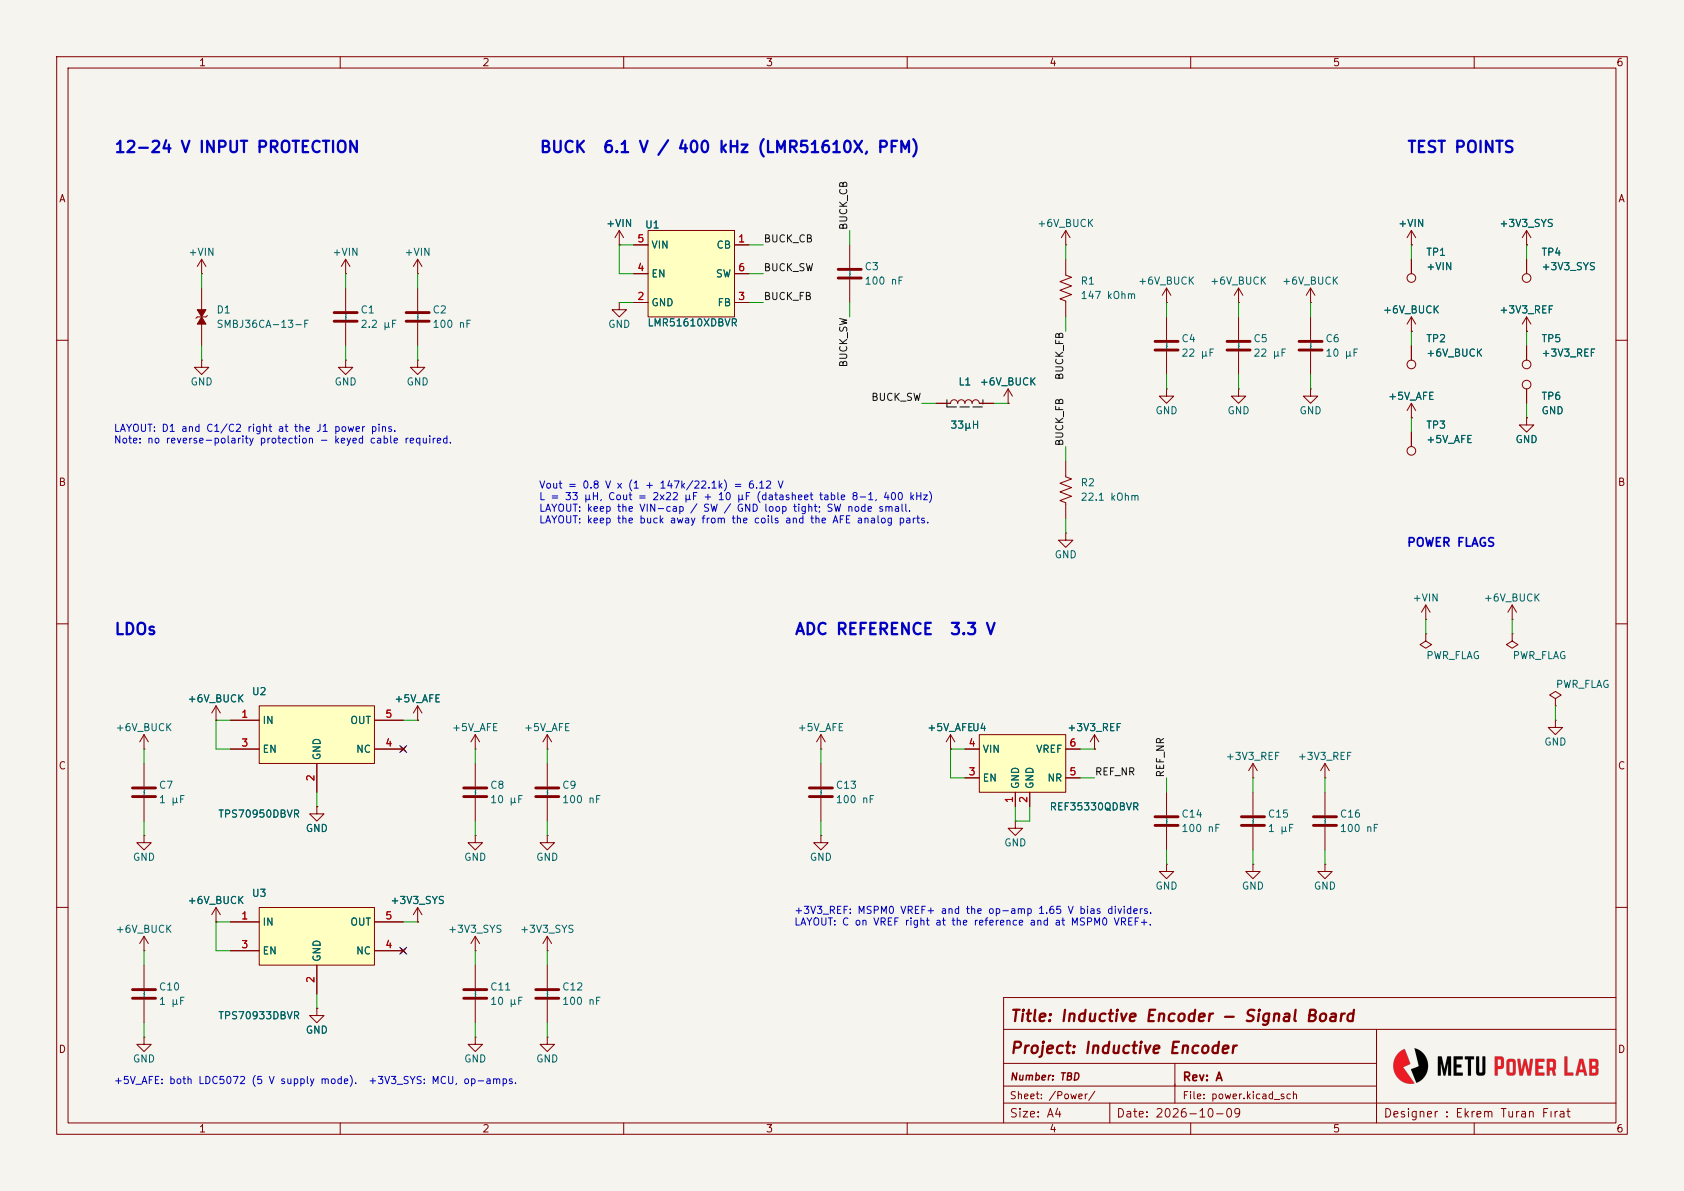
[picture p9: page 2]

BUCK 6.1 V / 400 kHz (LMR51610X, PFM) +3V3_REF: MSPM0 VREF+ and the op-amp 1.65 V bias dividers. LAYOUT: C on VREF right at the reference and at MSPM0 VREF+. ADC REFERENCE 3.3 V

LAYOUT: D1 and C1/C2 right at the J1 power pins. Note: no reverse-polarity protection - keyed cable required.

Vout = 0.8 V x (1 + 147k/22.1k) = 6.12 V
L = 33 µH, Cout = 2x22 µF + 10 µF (datasheet table 8-1, 400 kHz) LAYOUT: keep the VIN-cap / SW / GND loop tight; SW node small. LAYOUT: keep the buck away from the coils and the AFE analog parts.

Title: Inductive Encoder - Signal Board
Project: Inductive Encoder Number: TBD

+5V_AFE: both LDC5072 (5 V supply mode). +3V3_SYS: MCU, op-amps.

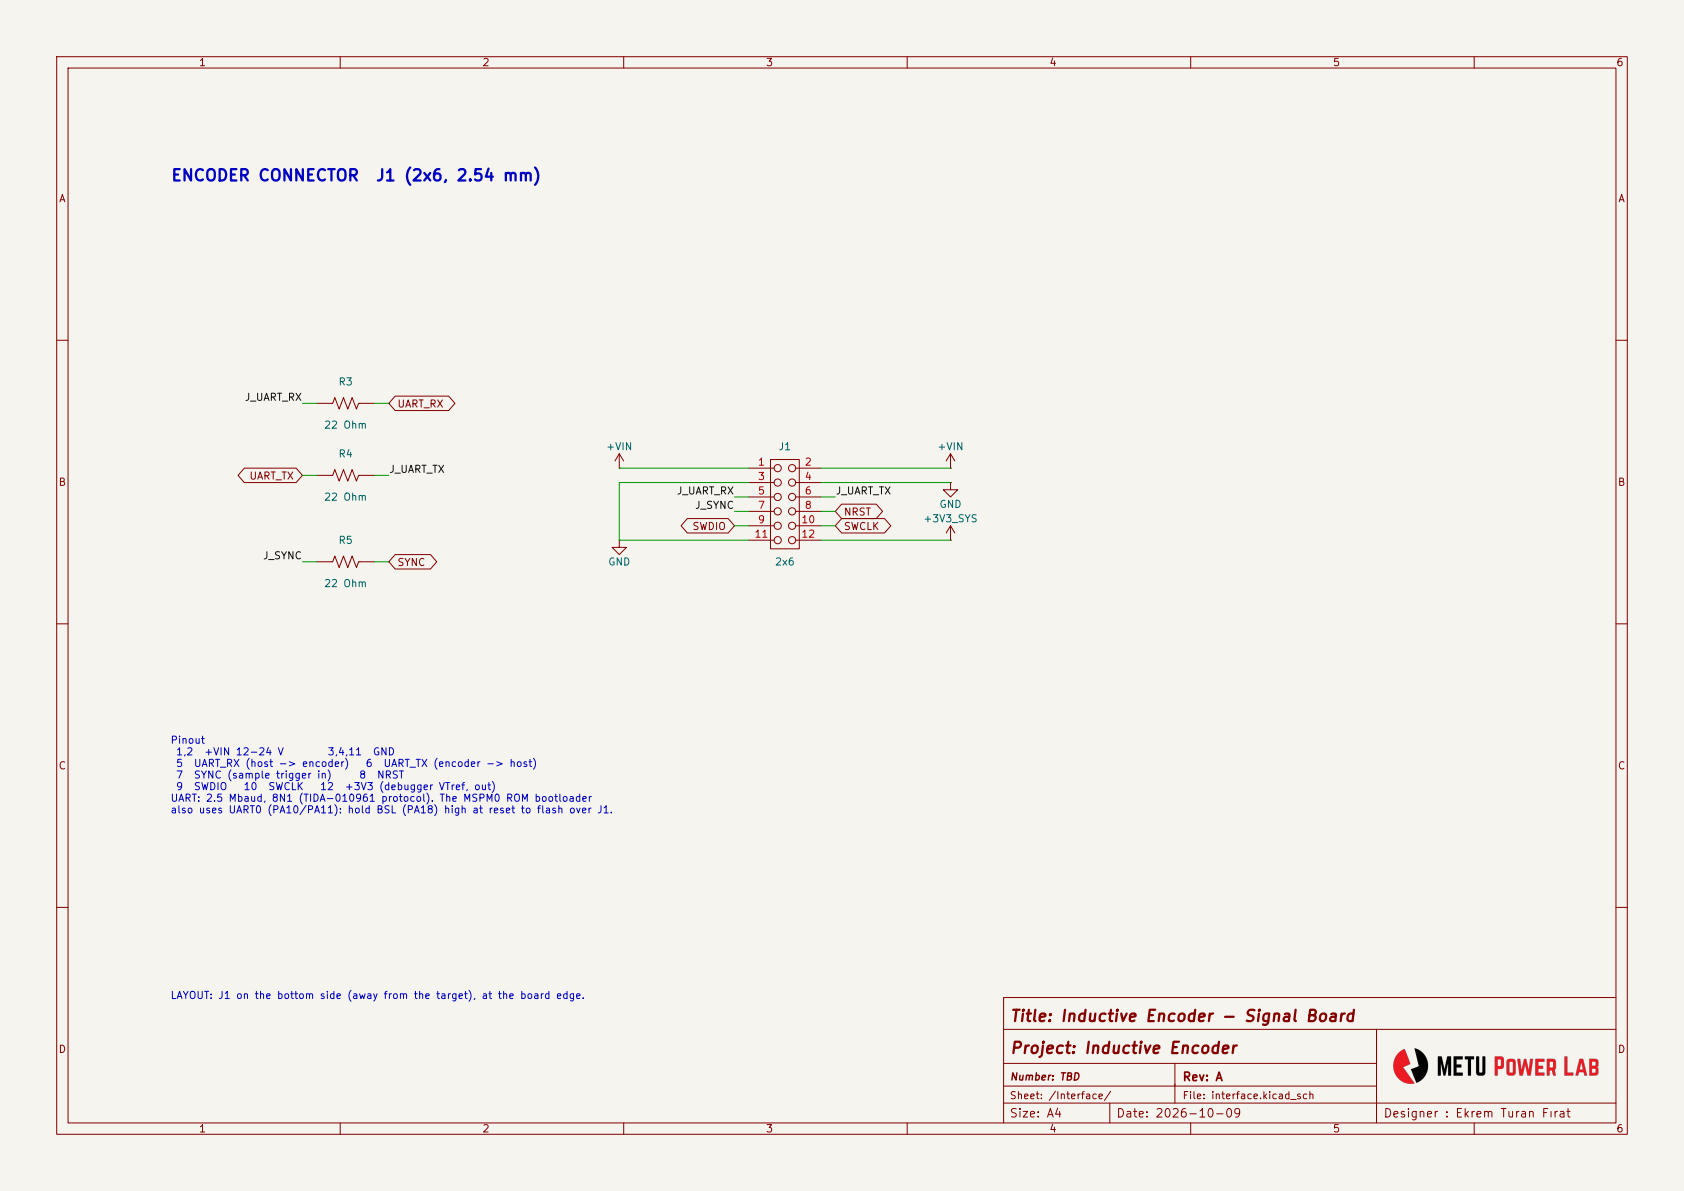
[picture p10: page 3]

Title: Inductive Encoder - Signal Board

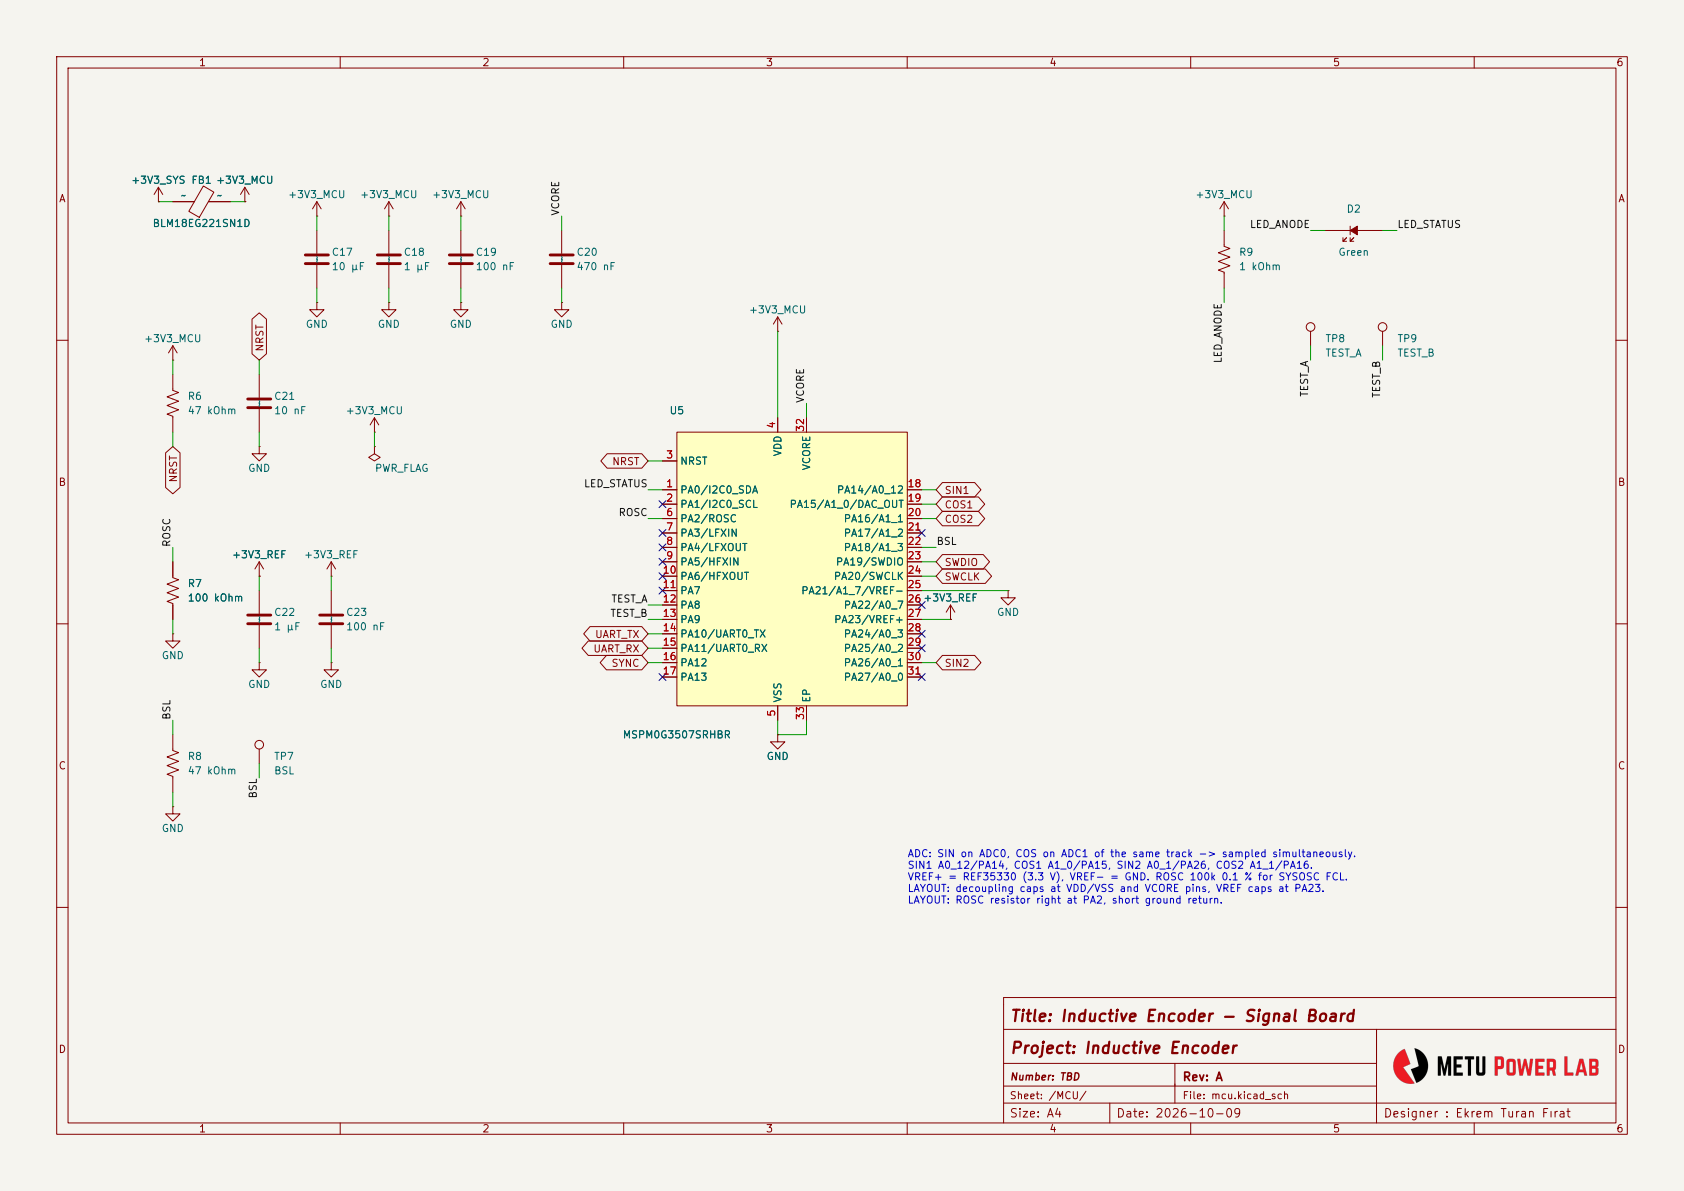
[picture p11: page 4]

5 PA2/ROSC 6 PA3/LFXIN 7 PA4/LFXOUT 8 PA5/HFXIN 9 PA6/HFXOUT 10 PA7 11 PA8 12 PA9 13 PA10/UART0_TX 14 PA11/UART0_RX 15 PA12 16 PA13 17 PA14/A0_12 18 PA15/A1_0/DAC_OUT 19 PA16/A1_1 20 PA17/A1_2 21 PA18/A1_3 22 PA19/SWDIO 23 PA20/SWCLK 24 PA21/A1_7/VREF- 25 PA22/A0_7 26 PA23/VREF+ 27 PA24/A0_3 28 PA25/A0_2 29 PA26/A0_1 30 PA27/A0_0 31 VCORE 32 EP 33 U5 MSPM0G3507SRHBR

5 PA2/ROSC 6 PA3/LFXIN 7 PA4/LFXOUT 8 PA5/HFXIN 9 PA6/HFXOUT 10 PA7 11 PA8 12 PA9 13 PA10/UART0_TX 14 PA11/UART0_RX 15 PA12 16 PA13 17 PA14/A0_12 18 PA15/A1_0/DAC_OUT 19 PA16/A1_1 20 PA17/A1_2 21 PA18/A1_3 22 PA19/SWDIO 23 PA20/SWCLK 24 PA21/A1_7/VREF- 25 PA22/A0_7 26 PA23/VREF+ 27 PA24/A0_3 28 PA25/A0_2 29 PA26/A0_1 30 PA27/A0_0 31 VCORE 32 EP 33 +3V3_REF R7

ADC: SIN on ADC0, COS on ADC1 of the same track -> sampled simultaneously. SIN1 A0_12/PA14, COS1 A1_0/PA15, SIN2 A0_1/PA26, COS2 A1_1/PA16. VREF+ = REF35330 (3.3 V), VREF- = GND. ROSC 100k 0.1 % for SYSOSC FCL. LAYOUT: decoupling caps at VDD/VSS and VCORE pins, VREF caps at PA23. LAYOUT: ROSC resistor right at PA2, short ground return.

Title: Inductive Encoder - Signal Board

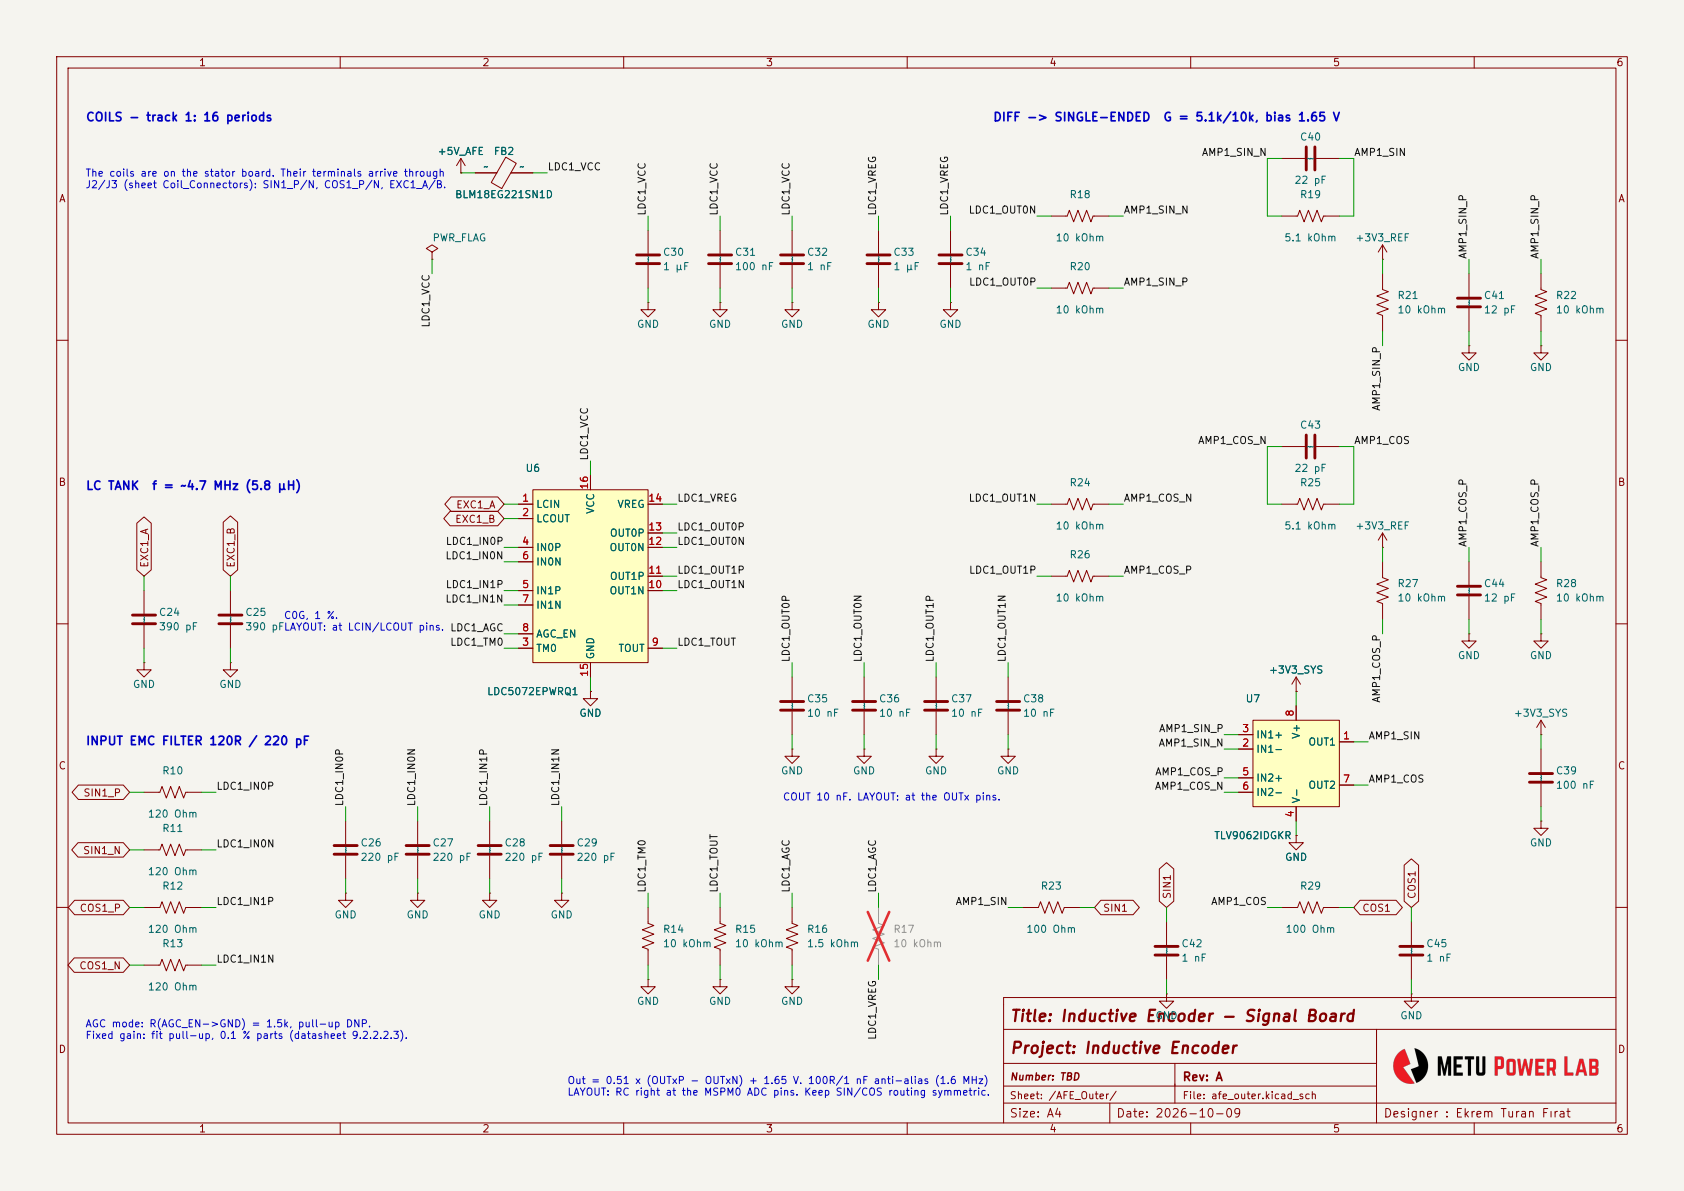
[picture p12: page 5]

DIFF -> SINGLE-ENDED G = 5.1k/10k, bias 1.65 V
VREG 14 GND 15 VCC 16 +5V_AFE FB2 BLM18EG221SN1D
1 nF GND

The coils are on the stator board. Their terminals arrive through
J2/J3 (sheet Coil_Connectors): SIN1_P/N, COS1_P/N, EXC1_A/B.

LC TANK f = ~4.7 MHz (5.8 µH)

C0G, 1 %. LAYOUT: at LCIN/LCOUT pins.

Title: Inductive Encoder - Signal Board

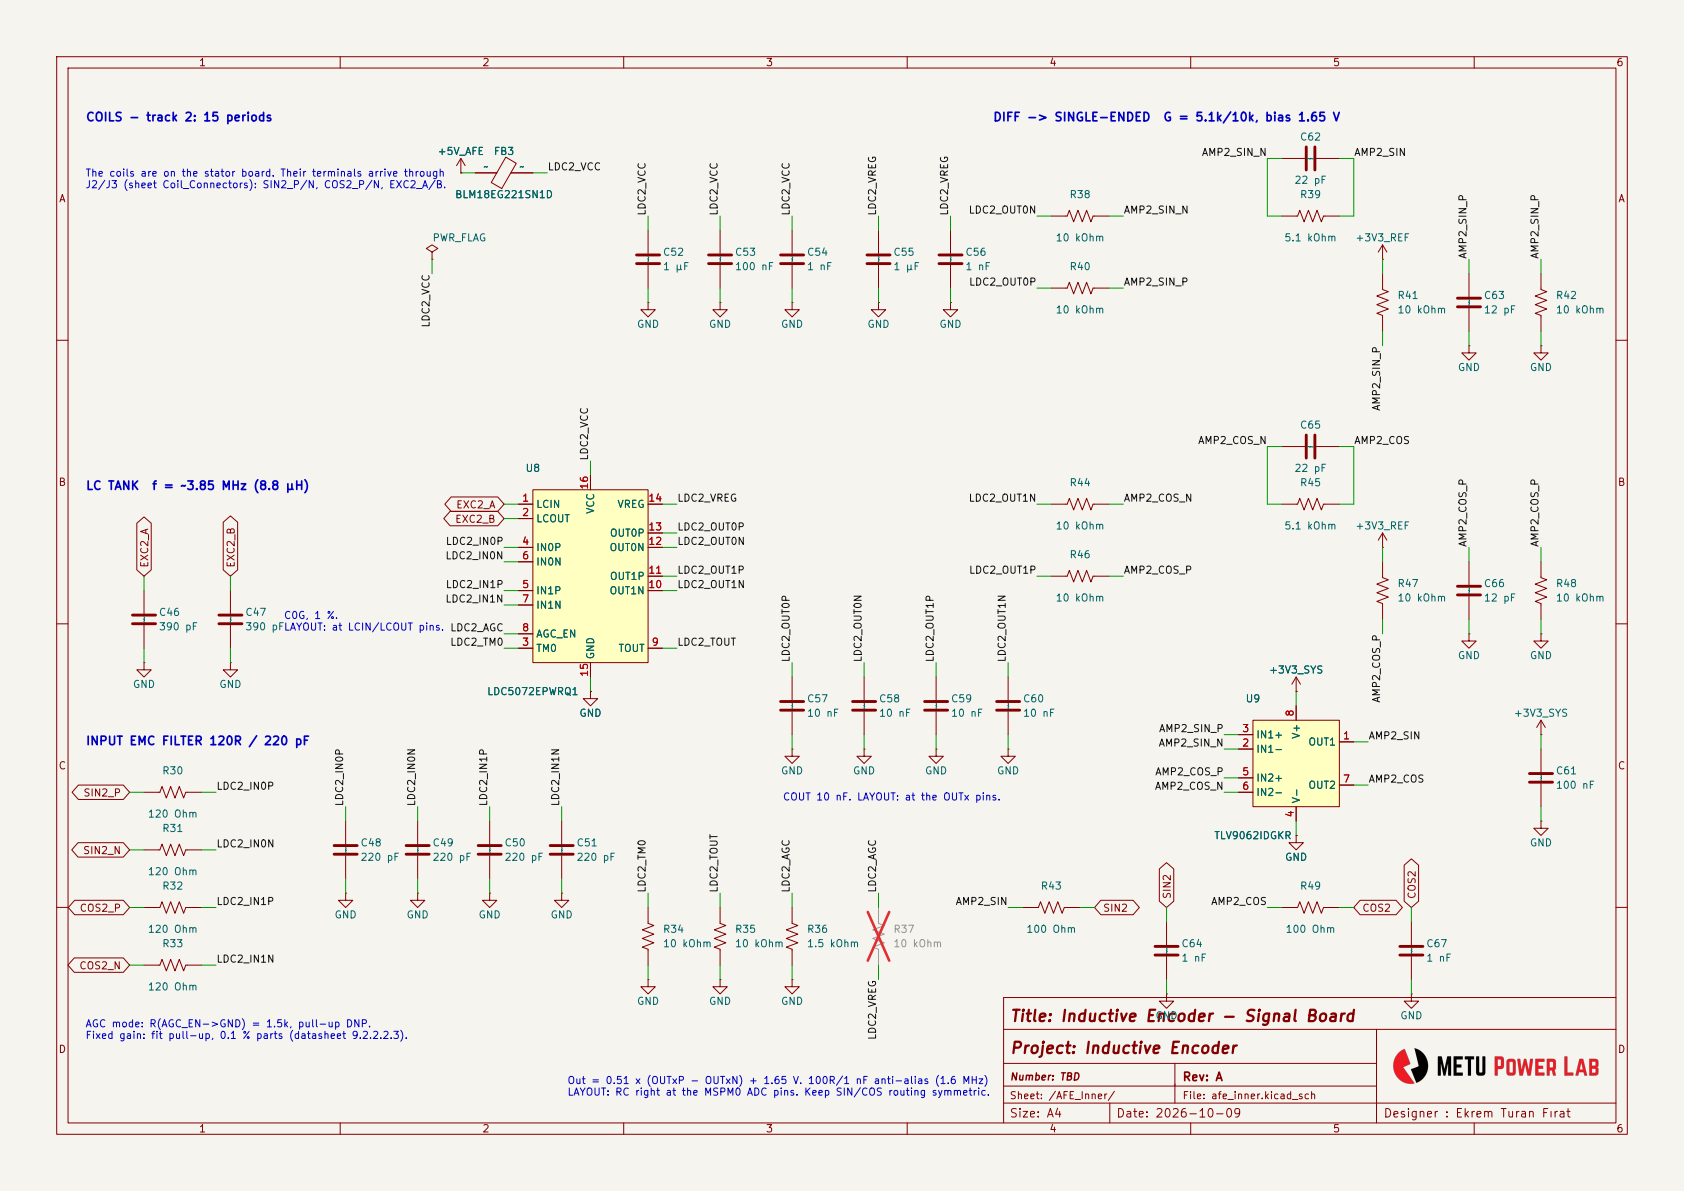
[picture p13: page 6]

DIFF -> SINGLE-ENDED G = 5.1k/10k, bias 1.65 V
VREG 14 GND 15 VCC 16 +5V_AFE FB3 BLM18EG221SN1D
1 nF GND

The coils are on the stator board. Their terminals arrive through
J2/J3 (sheet Coil_Connectors): SIN2_P/N, COS2_P/N, EXC2_A/B.

LC TANK f = ~3.85 MHz (8.8 µH)

C0G, 1 %. LAYOUT: at LCIN/LCOUT pins.

Title: Inductive Encoder - Signal Board

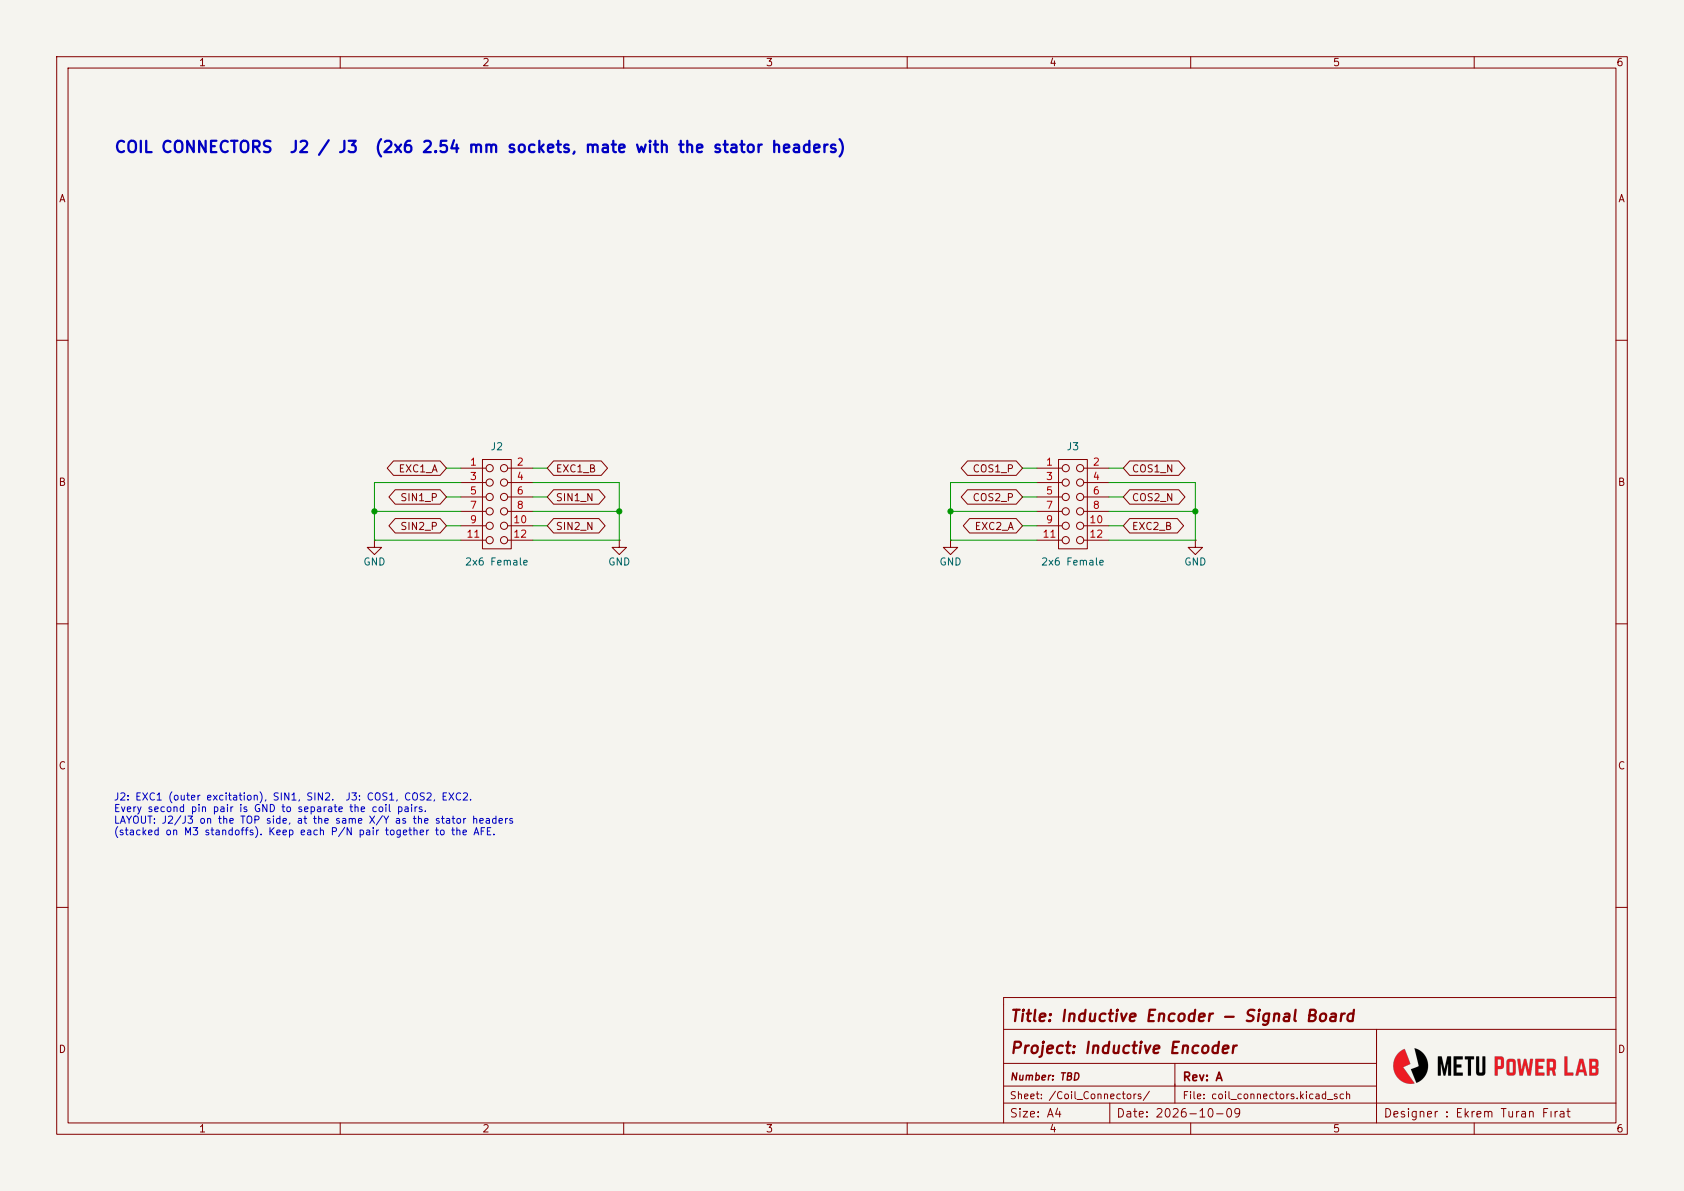
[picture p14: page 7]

(stacked on M3 standoffs). Keep each P/N pair together to the AFE. COIL CONNECTORS J2 / J3 (2x6 2.54 mm sockets, mate with the stator headers)

J2: EXC1 (outer excitation), SIN1, SIN2. J3: COS1, COS2, EXC2. Every second pin pair is GND to separate the coil pairs. LAYOUT: J2/J3 on the TOP side, at the same X/Y as the stator headers

Title: Inductive Encoder - Signal Board

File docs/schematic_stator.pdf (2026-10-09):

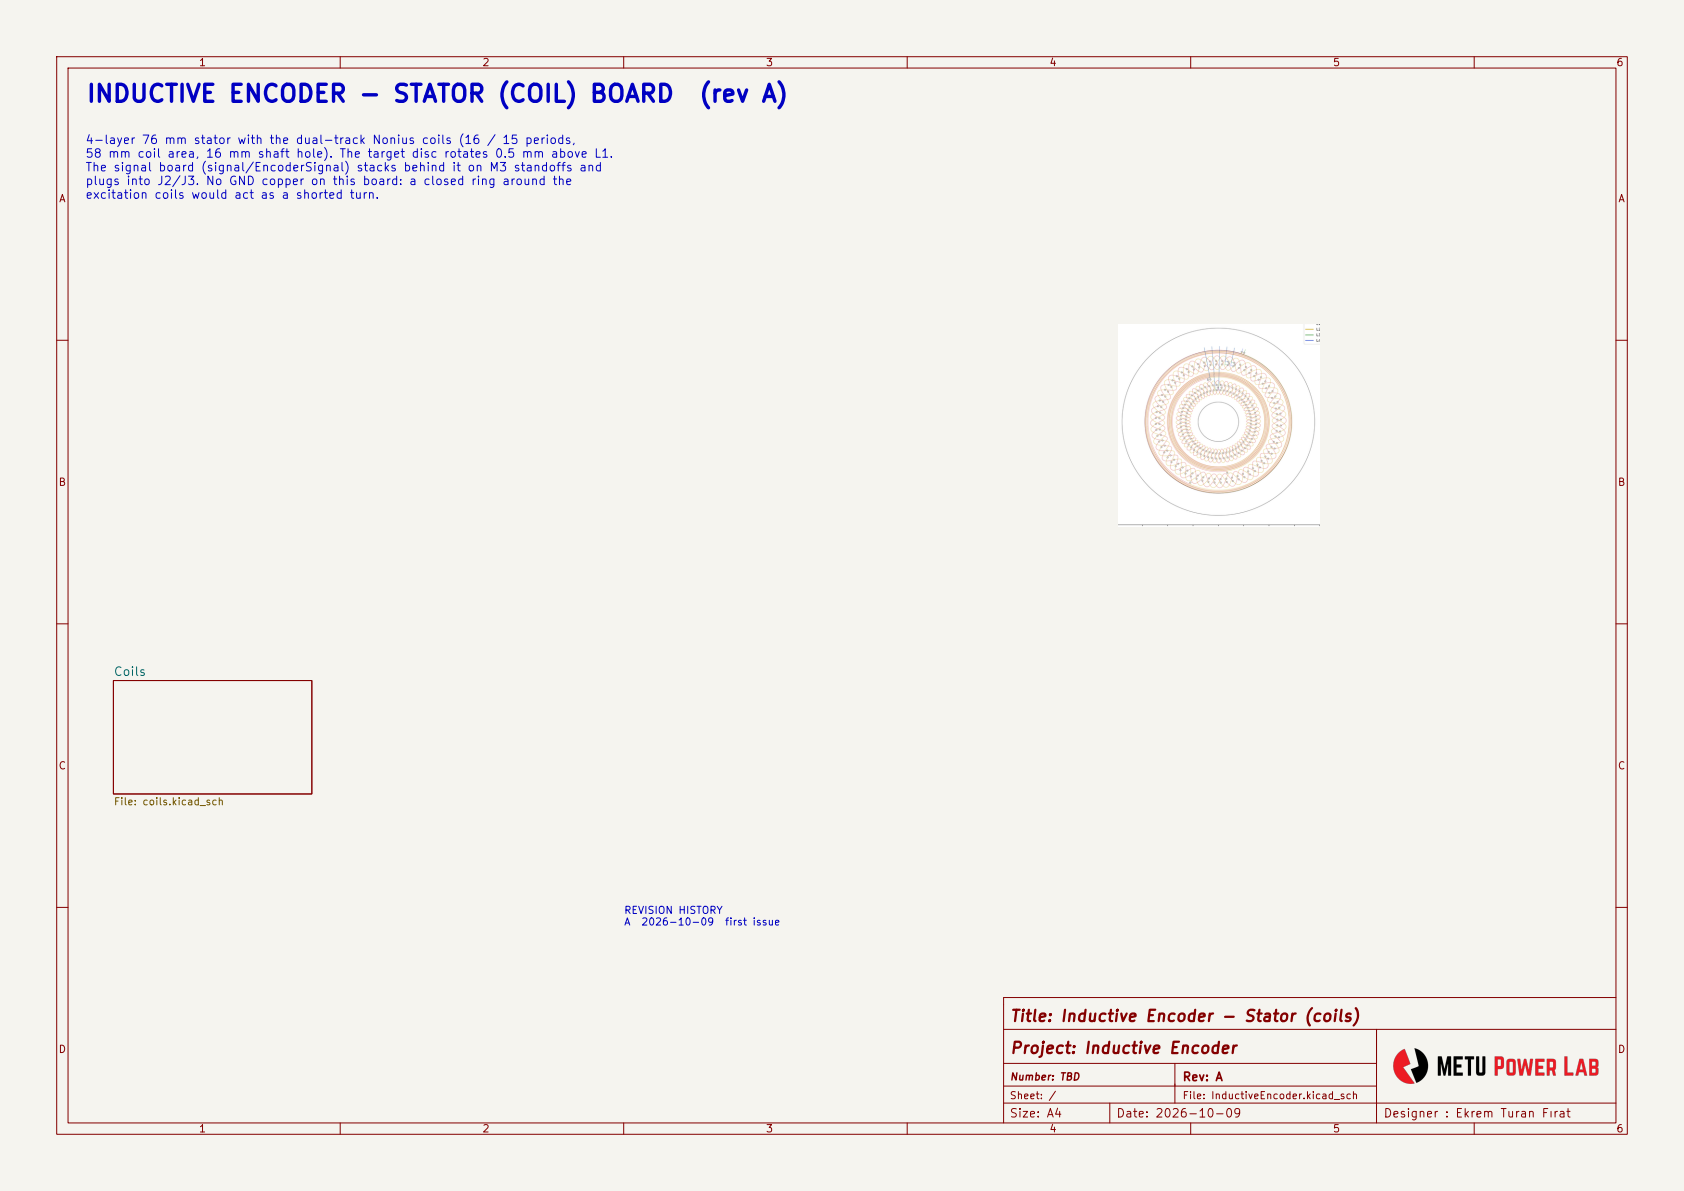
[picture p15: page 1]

INDUCTIVE ENCODER - STATOR (COIL) BOARD (rev A)

4-layer 76 mm stator with the dual-track Nonius coils (16 / 15 periods,
58 mm coil area, 16 mm shaft hole). The target disc rotates 0.5 mm above L1.
The signal board (signal/EncoderSignal) stacks behind it on M3 standoffs and
plugs into J2/J3. No GND copper on this board: a closed ring around the

Title: Inductive Encoder - Stator (coils)

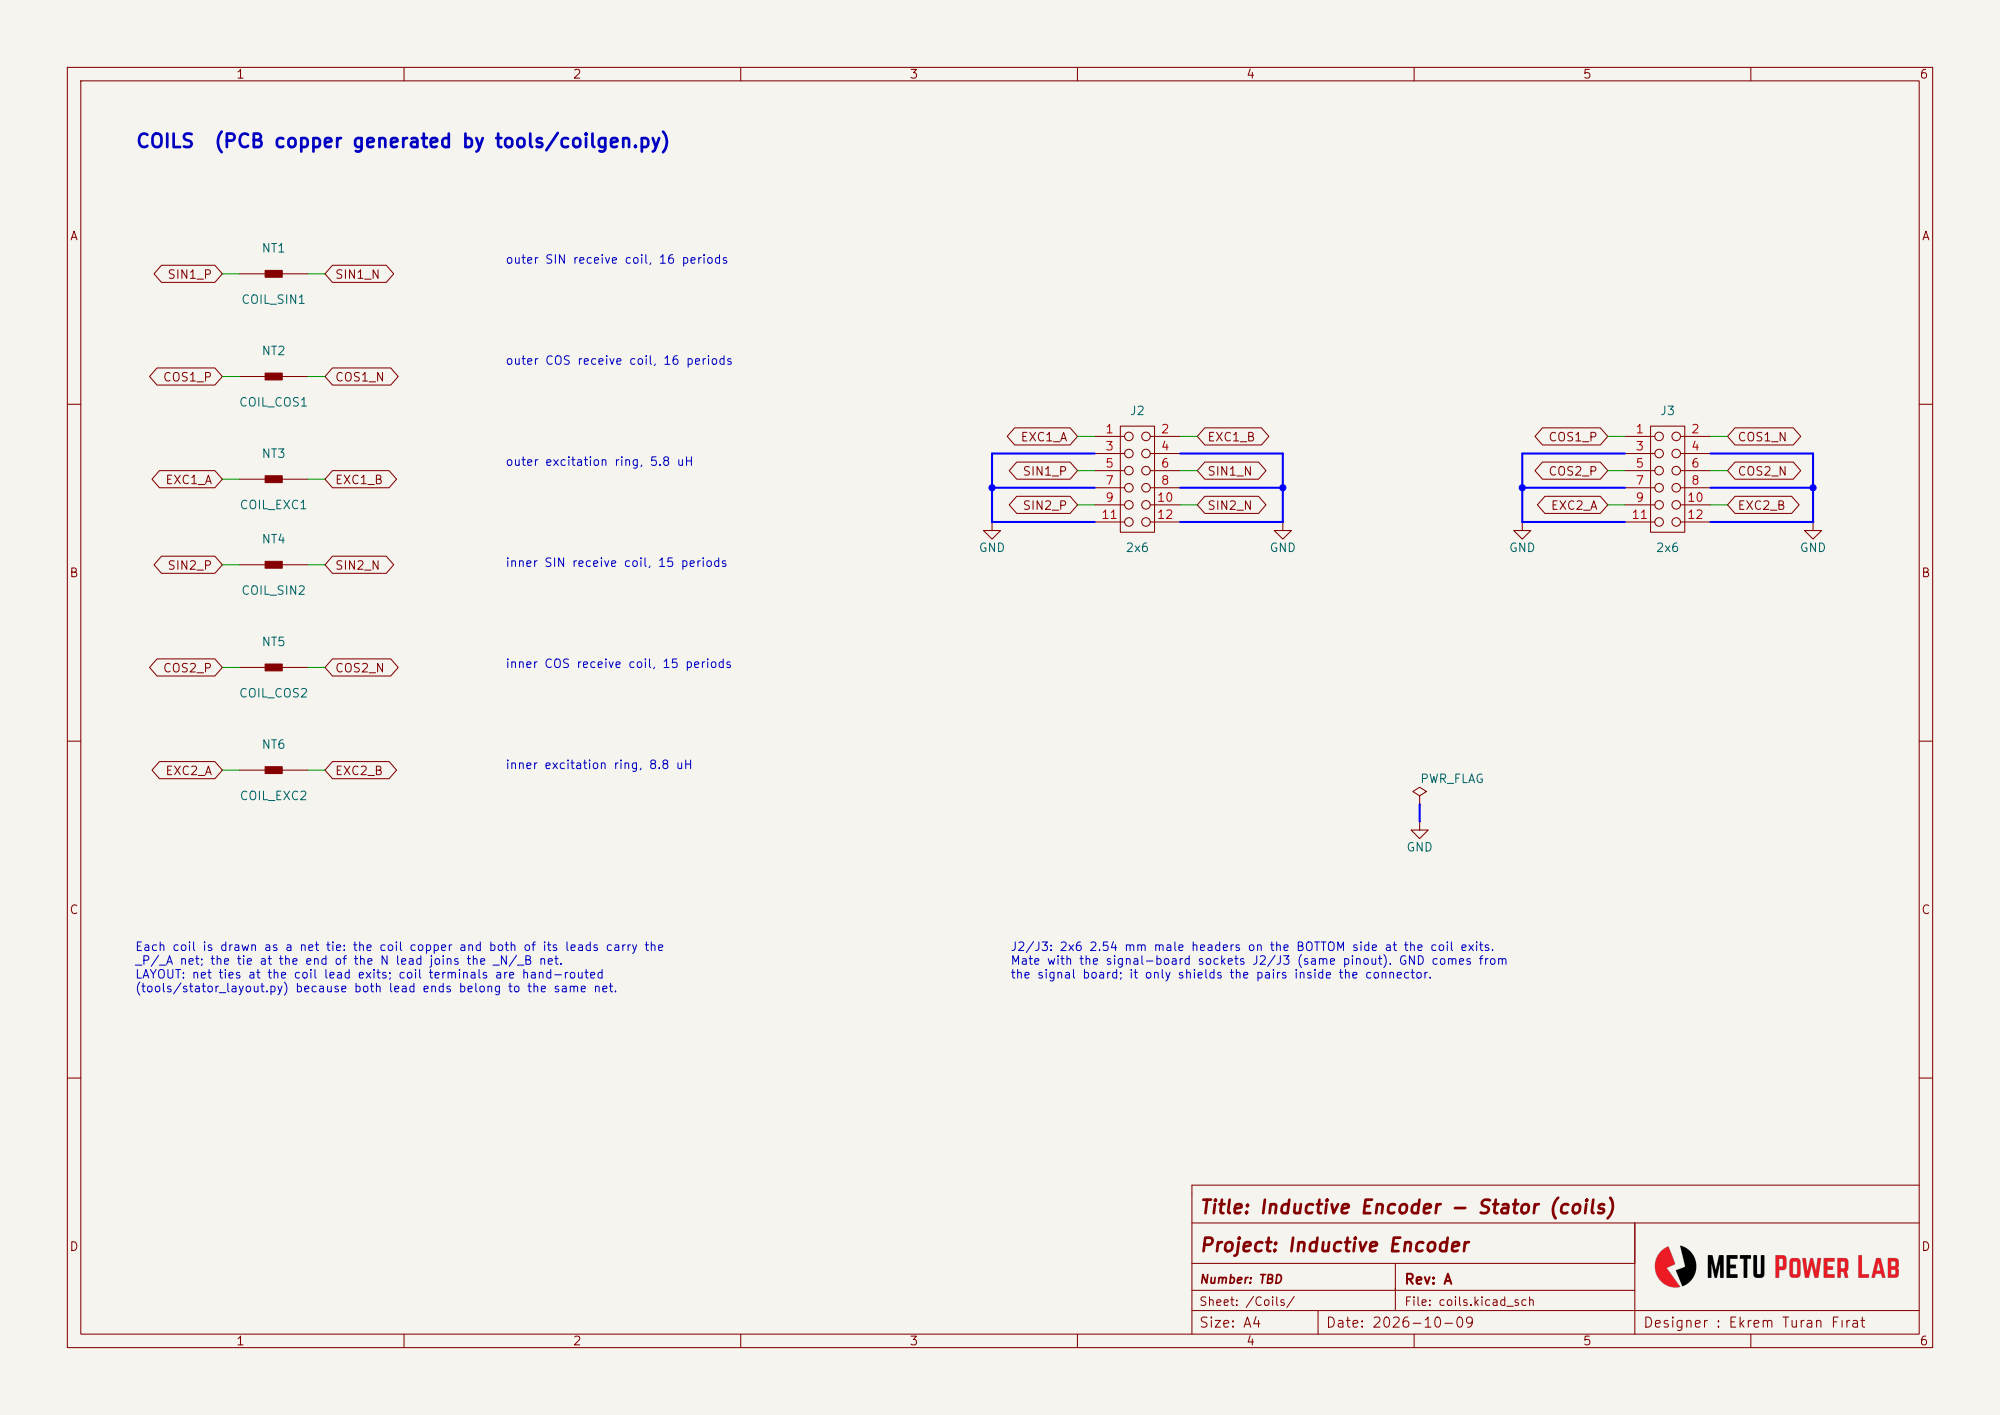
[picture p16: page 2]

SIN2_P COILS (PCB copper generated by tools/coilgen.py)

inner SIN receive coil, 15 periods outer SIN receive coil, 16 periods

outer COS receive coil, 16 periods Each coil is drawn as a net tie: the coil copper and both of its leads carry the

outer excitation ring, 5.8 uH

inner COS receive coil, 15 periods

inner excitation ring, 8.8 uH

J2/J3: 2x6 2.54 mm male headers on the BOTTOM side at the coil exits. Mate with the signal-board sockets J2/J3 (same pinout). GND comes from

_P/_A net; the tie at the end of the N lead joins the _N/_B net. LAYOUT: net ties at the coil lead exits; coil terminals are hand-routed

the signal board; it only shields the pairs inside the connector.

(tools/stator_layout.py) because both lead ends belong to the same net.

Title: Inductive Encoder - Stator (coils)

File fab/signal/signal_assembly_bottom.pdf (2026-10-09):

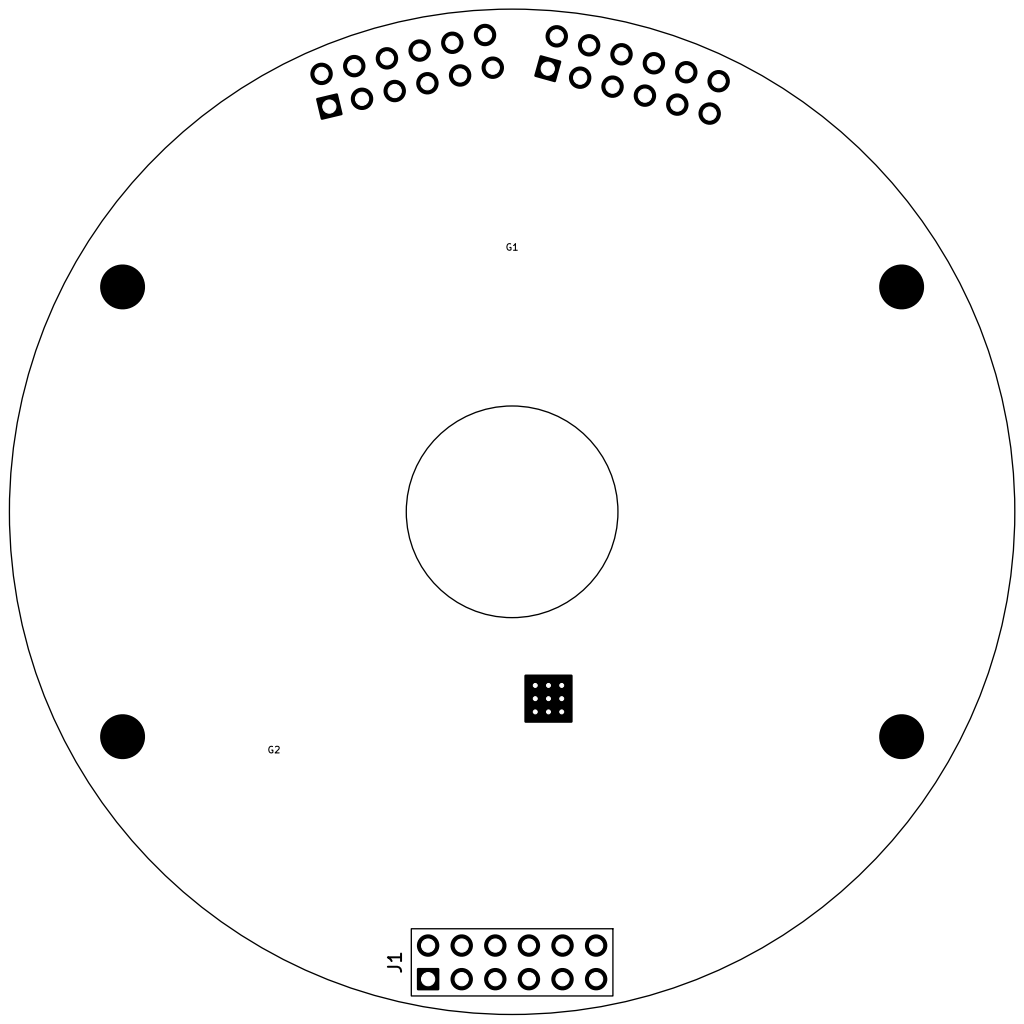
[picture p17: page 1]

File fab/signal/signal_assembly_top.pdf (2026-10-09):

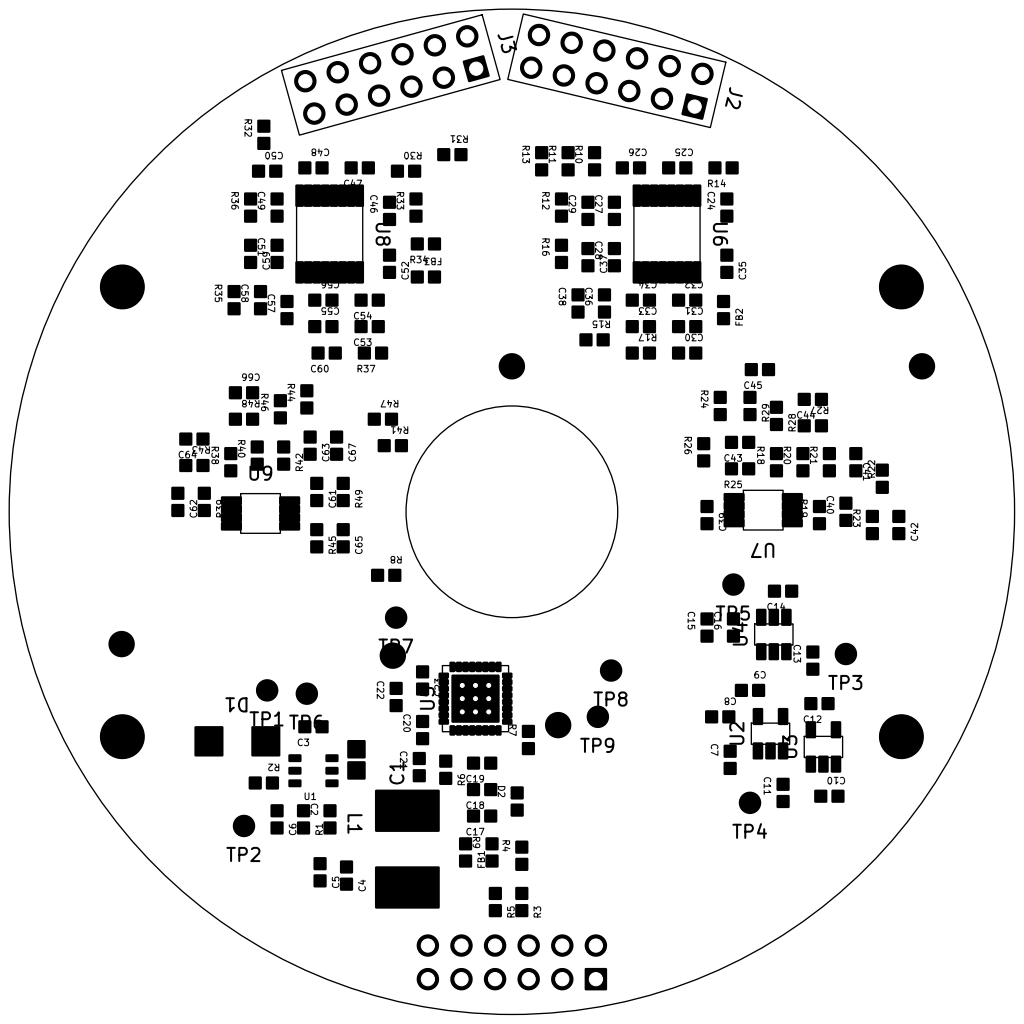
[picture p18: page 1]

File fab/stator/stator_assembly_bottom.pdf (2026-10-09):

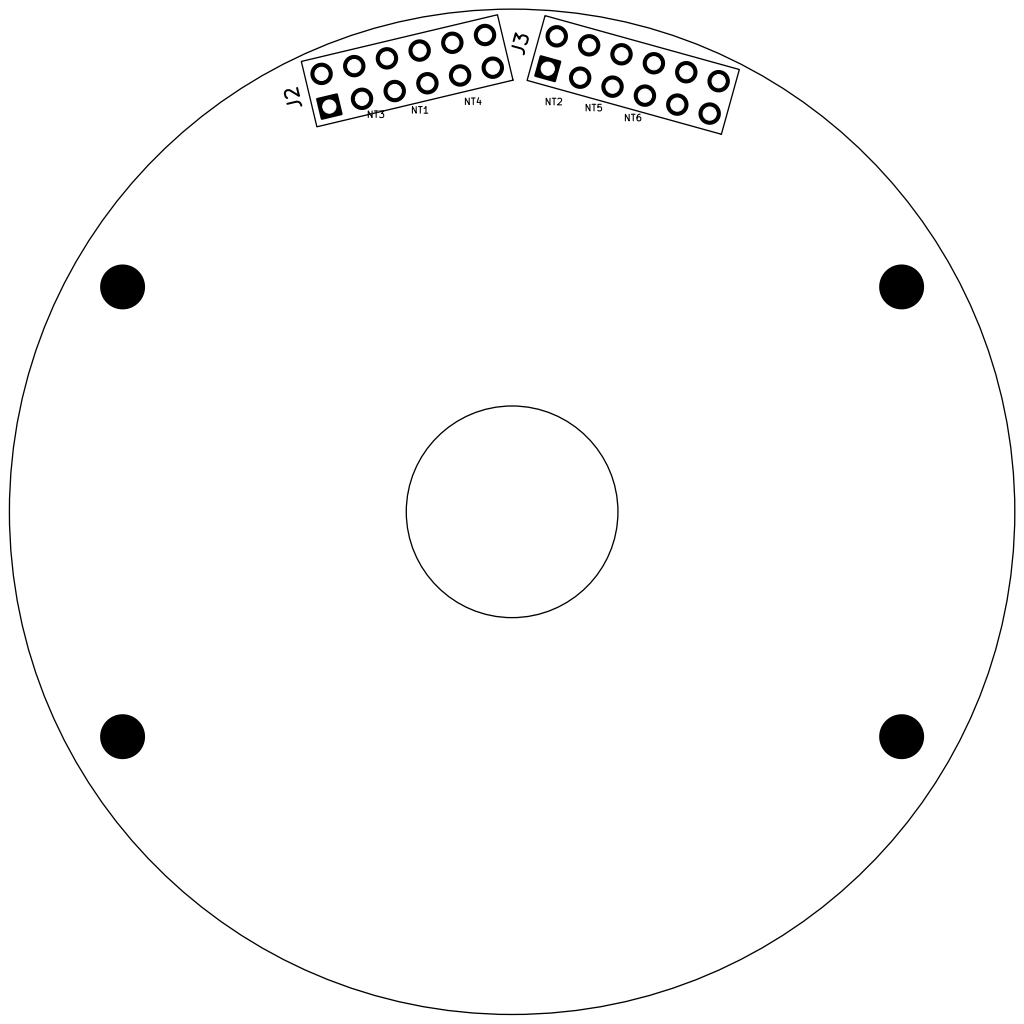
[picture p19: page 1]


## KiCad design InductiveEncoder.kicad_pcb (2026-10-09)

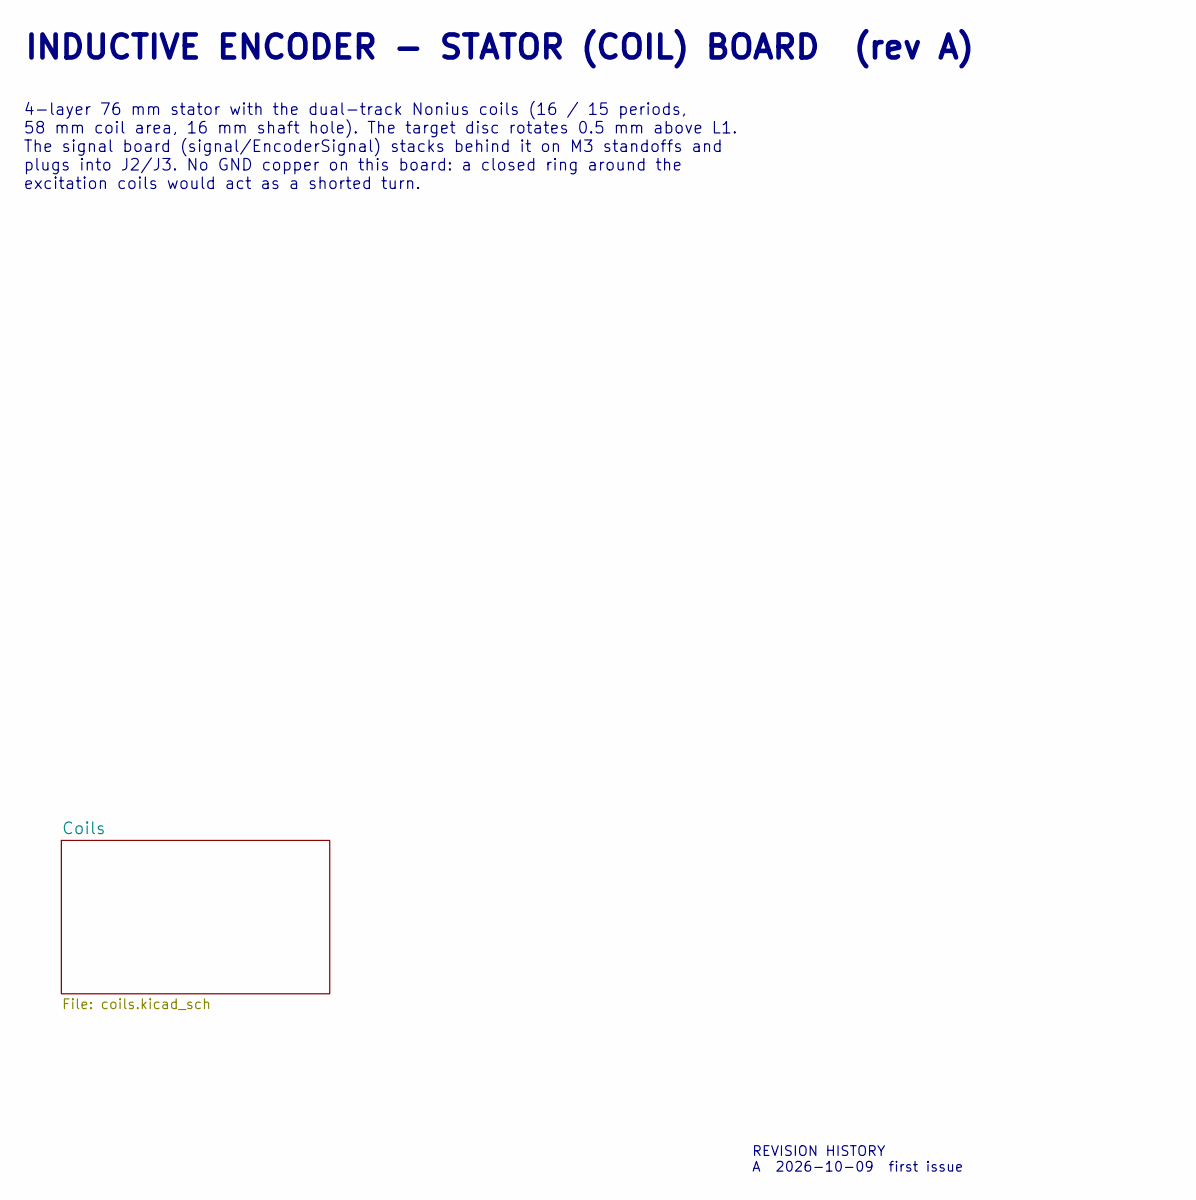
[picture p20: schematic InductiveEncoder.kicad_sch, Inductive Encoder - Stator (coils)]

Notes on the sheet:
INDUCTIVE ENCODER - STATOR (COIL) BOARD (rev A)
4-layer 76 mm stator with the dual-track Nonius coils (16 / 15 periods, 58 mm coil area, 16 mm shaft hole). The target disc rotates 0.5 mm above L1. The signal board (signal/EncoderSignal) stacks behind it on M3 standoffs and plugs into J2/J3. No GND copper on this board: a closed ring around the e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
REVISION HISTORY A 2026-10-09 first issue

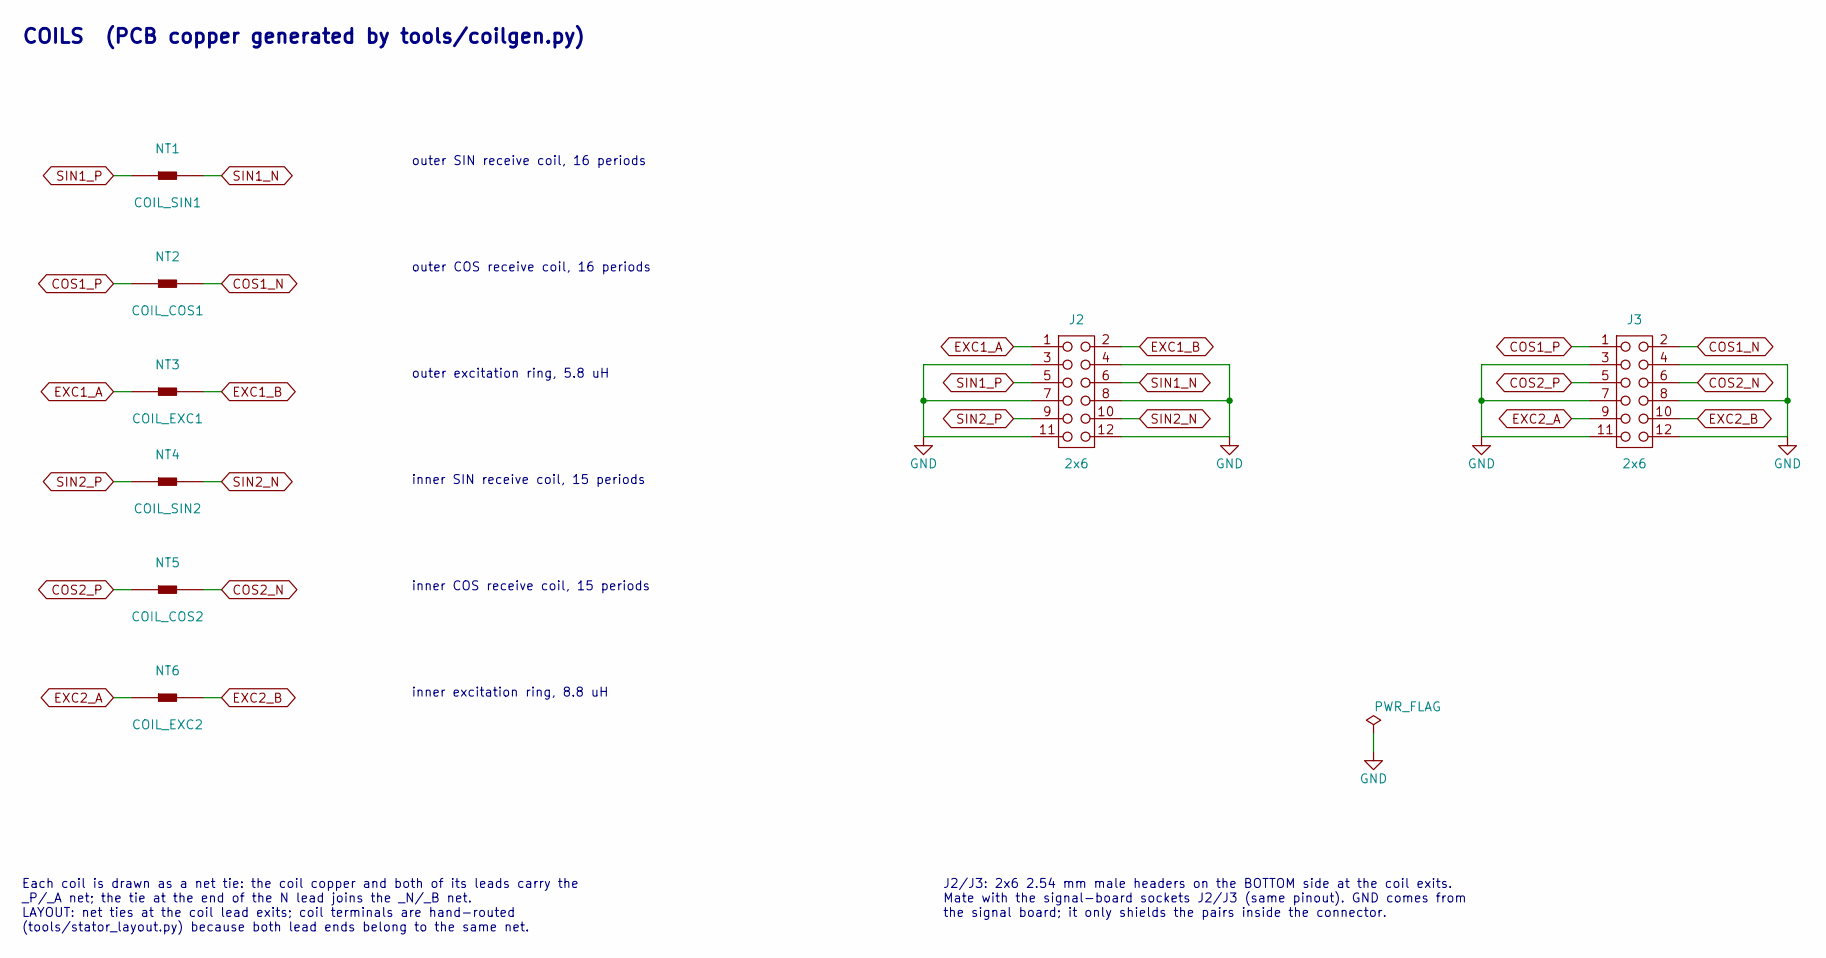
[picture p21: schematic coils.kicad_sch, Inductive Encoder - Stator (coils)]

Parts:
J2, J3: 2x6; 61301221121; Current Rating 3A; Voltage Rating 250V; Digi-Key Number 732-5297-ND
NT1: COIL_SIN1; NetTie_2_0.5mm
NT2: COIL_COS1; NetTie_2_0.5mm
NT3: COIL_EXC1; NetTie_2_0.5mm
NT4: COIL_SIN2; NetTie_2_0.5mm
NT5: COIL_COS2; NetTie_2_0.5mm
NT6: COIL_EXC2; NetTie_2_0.5mm

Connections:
COS1_N: J3.2, NT2.2
COS1_P: J3.1, NT2.1
COS2_N: J3.6, NT5.2
COS2_P: J3.5, NT5.1
EXC1_A: J2.1, NT3.1
EXC1_B: J2.2, NT3.2
EXC2_A: J3.9, NT6.1
EXC2_B: J3.10, NT6.2
GND: J2.3, J2.4, J2.7, J2.8, J2.11, J2.12, J3.3, J3.4, J3.7, J3.8, J3.11, J3.12
SIN1_N: J2.6, NT1.2
SIN1_P: J2.5, NT1.1
SIN2_N: J2.10, NT4.2
SIN2_P: J2.9, NT4.1

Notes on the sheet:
COILS (PCB copper generated by tools/coilgen.py)
outer SIN receive coil, 16 periods
outer COS receive coil, 16 periods
outer excitation ring, 5.8 uH
inner SIN receive coil, 15 periods
inner COS receive coil, 15 periods
inner excitation ring, 8.8 uH
Each coil is drawn as a net tie: the coil copper and both of its leads carry the _P/_A net; the tie at the end of the N lead joins the _N/_B net. LAYOUT: net ties at the coil lead exits; coil terminals are hand-routed (tools/stator_layout.py) because both lead ends belong to the same net.
J2/J3: 2x6 2.54 mm male headers on the BOTTOM side at the coil exits. Mate with the signal-board sockets J2/J3 (same pinout). GND comes from the signal board; it only shields the pairs inside the connector.

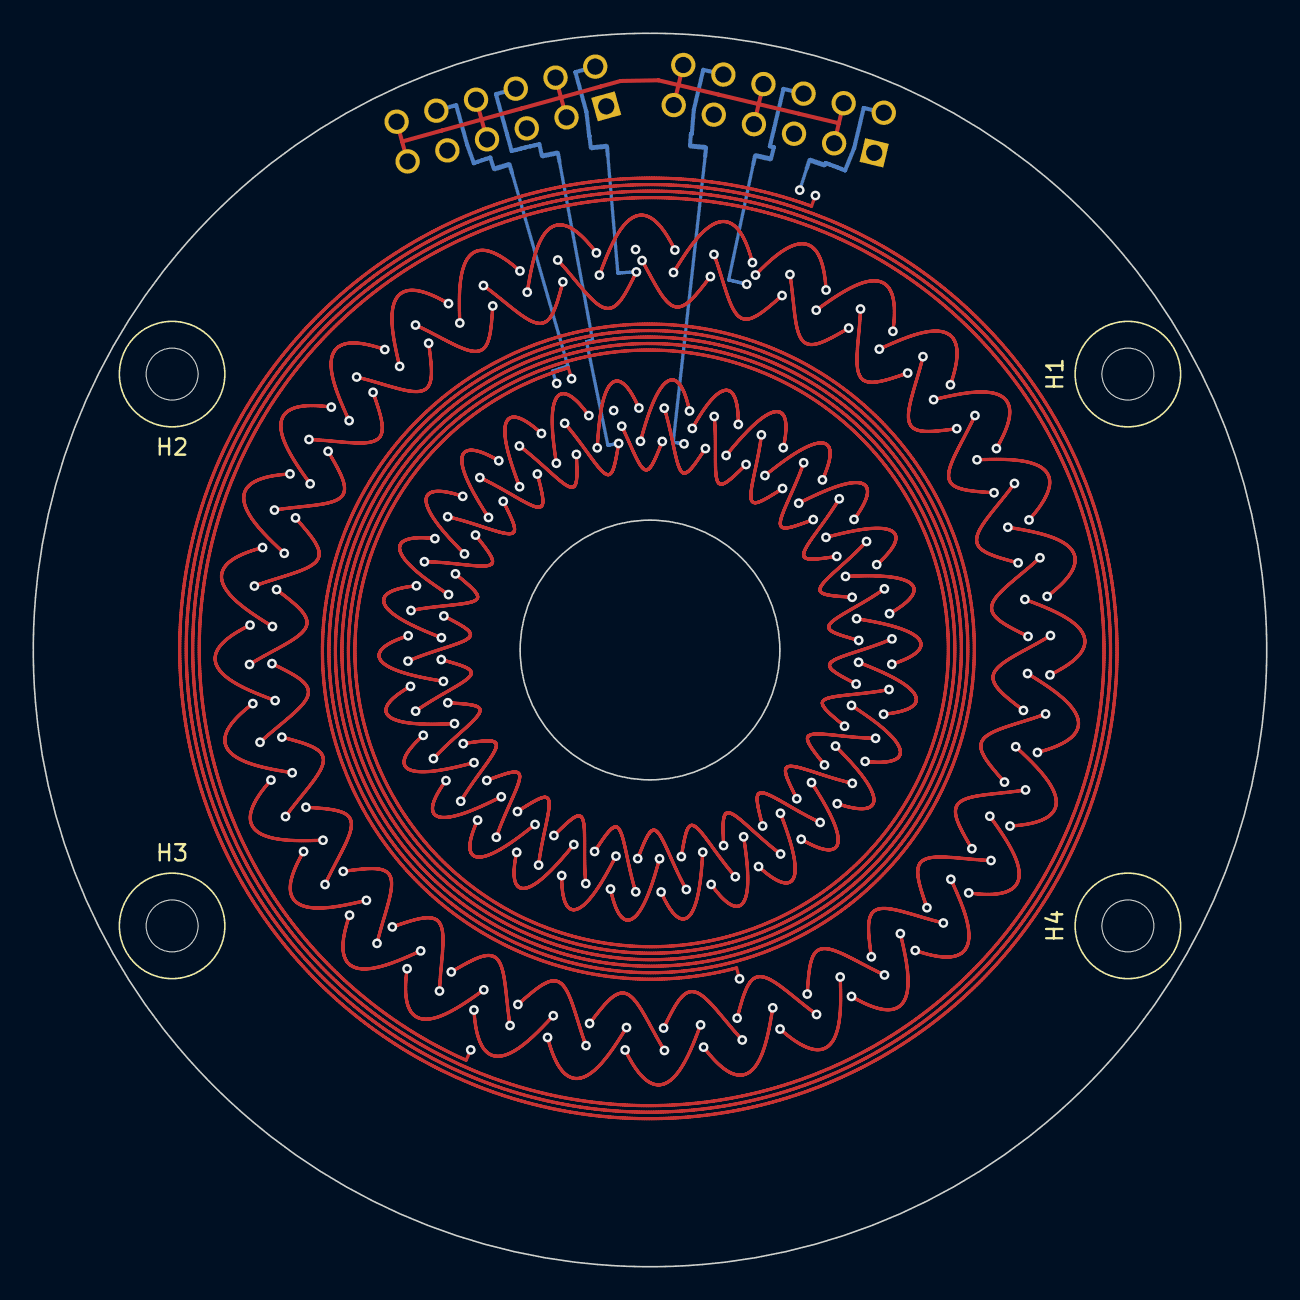
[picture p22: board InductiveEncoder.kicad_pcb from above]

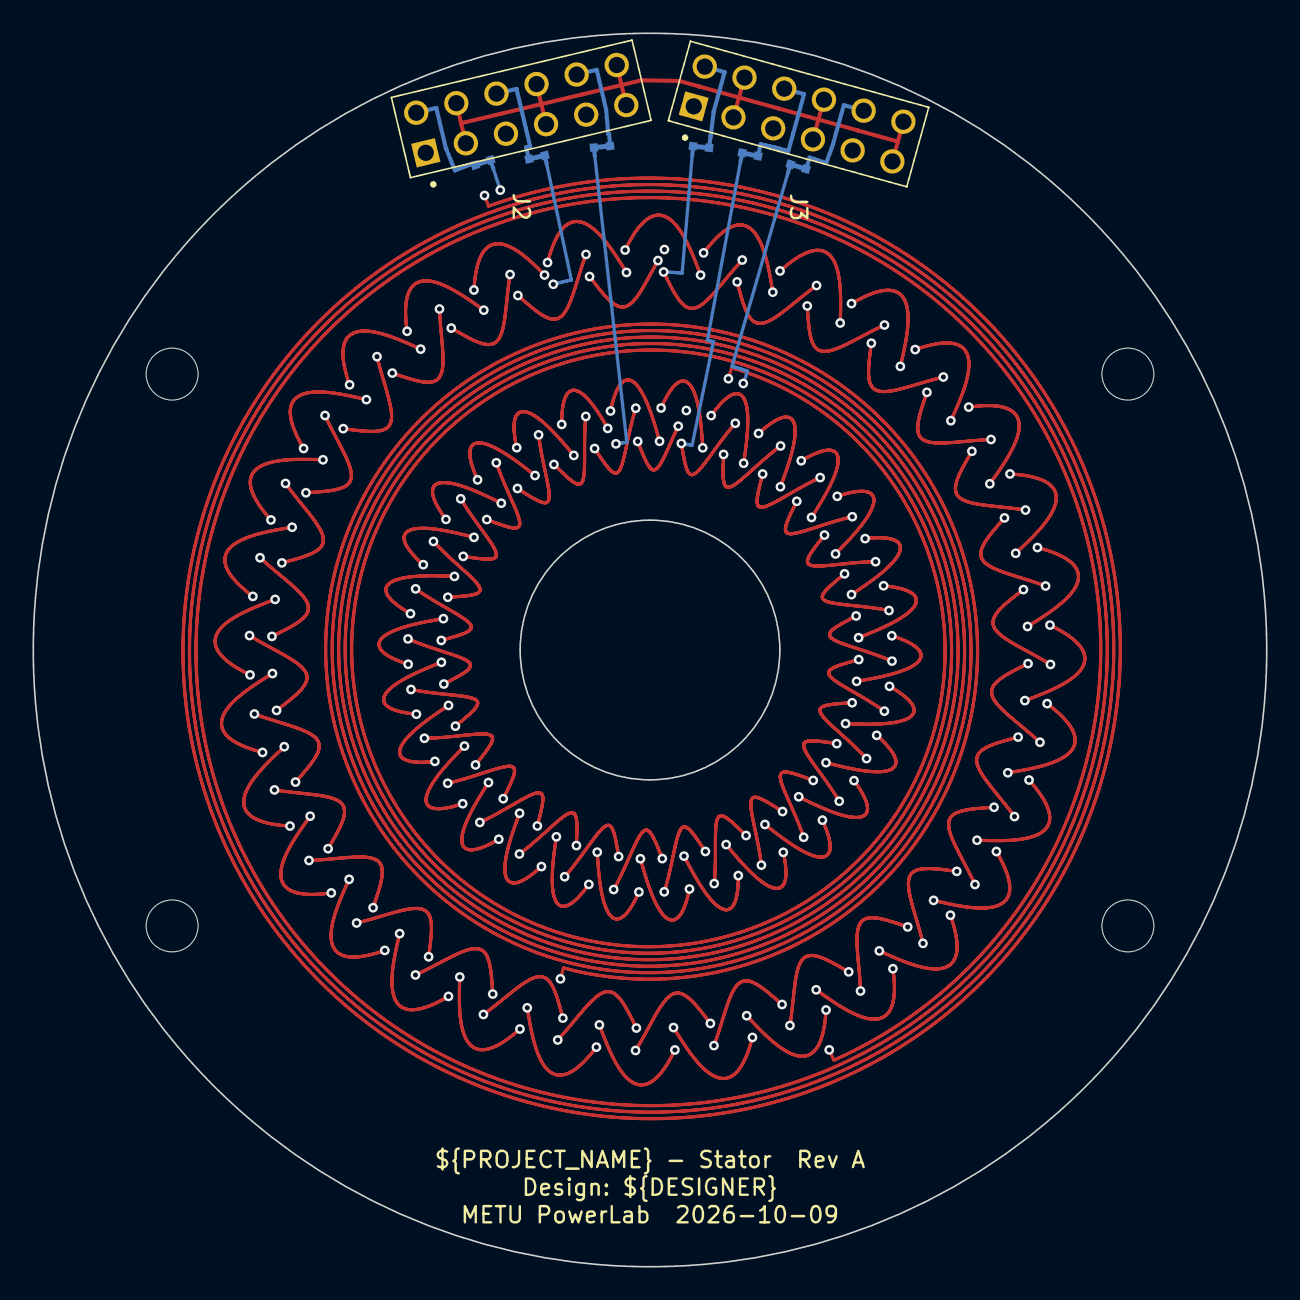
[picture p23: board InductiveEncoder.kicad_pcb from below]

Board: 4 copper layers, 76.0 x 76.0 mm, 12 parts (8 on the bottom side), 13 nets.

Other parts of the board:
H1, H2, H3, H4: M3_NPTH

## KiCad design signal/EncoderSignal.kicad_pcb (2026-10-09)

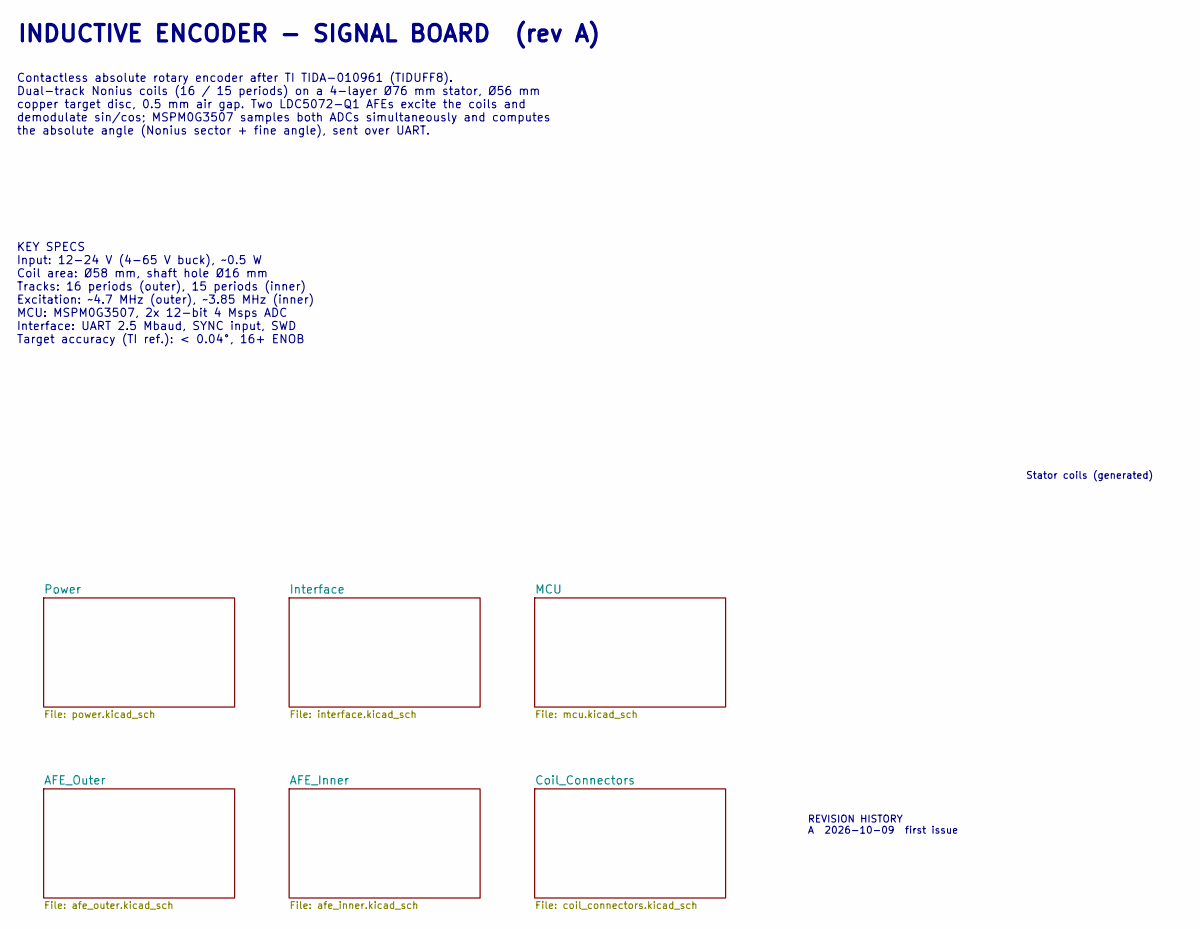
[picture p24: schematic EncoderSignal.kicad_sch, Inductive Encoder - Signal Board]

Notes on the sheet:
INDUCTIVE ENCODER - SIGNAL BOARD (rev A)
Contactless absolute rotary encoder after TI TIDA-010961 (TIDUFF8). Dual-track Nonius coils (16 / 15 periods) on a 4-layer Ø76 mm stator, Ø56 mm copper target disc, 0.5 mm air gap. Two LDC5072-Q1 AFEs excite the coils and demodulate sin/cos; MSPM0G3507 samples both ADCs simultaneously and computes 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
KEY SPECS Input: 12-24 V (4-65 V buck), ~0.5 W Coil area: Ø58 mm, shaft hole Ø16 mm Tracks: 16 periods (outer), 15 periods (inner) Excitation: ~4.7 MHz (outer), ~3.85 MHz (inner) MCU: MSPM0G3507, 2x 12-bit 4 Msps ADC Interface: UART 2.5 Mbaud, SYNC input, SWD Target accuracy (TI ref.): < 0.04°, 16+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
Stator coils (generated)
REVISION HISTORY A 2026-10-09 first issue

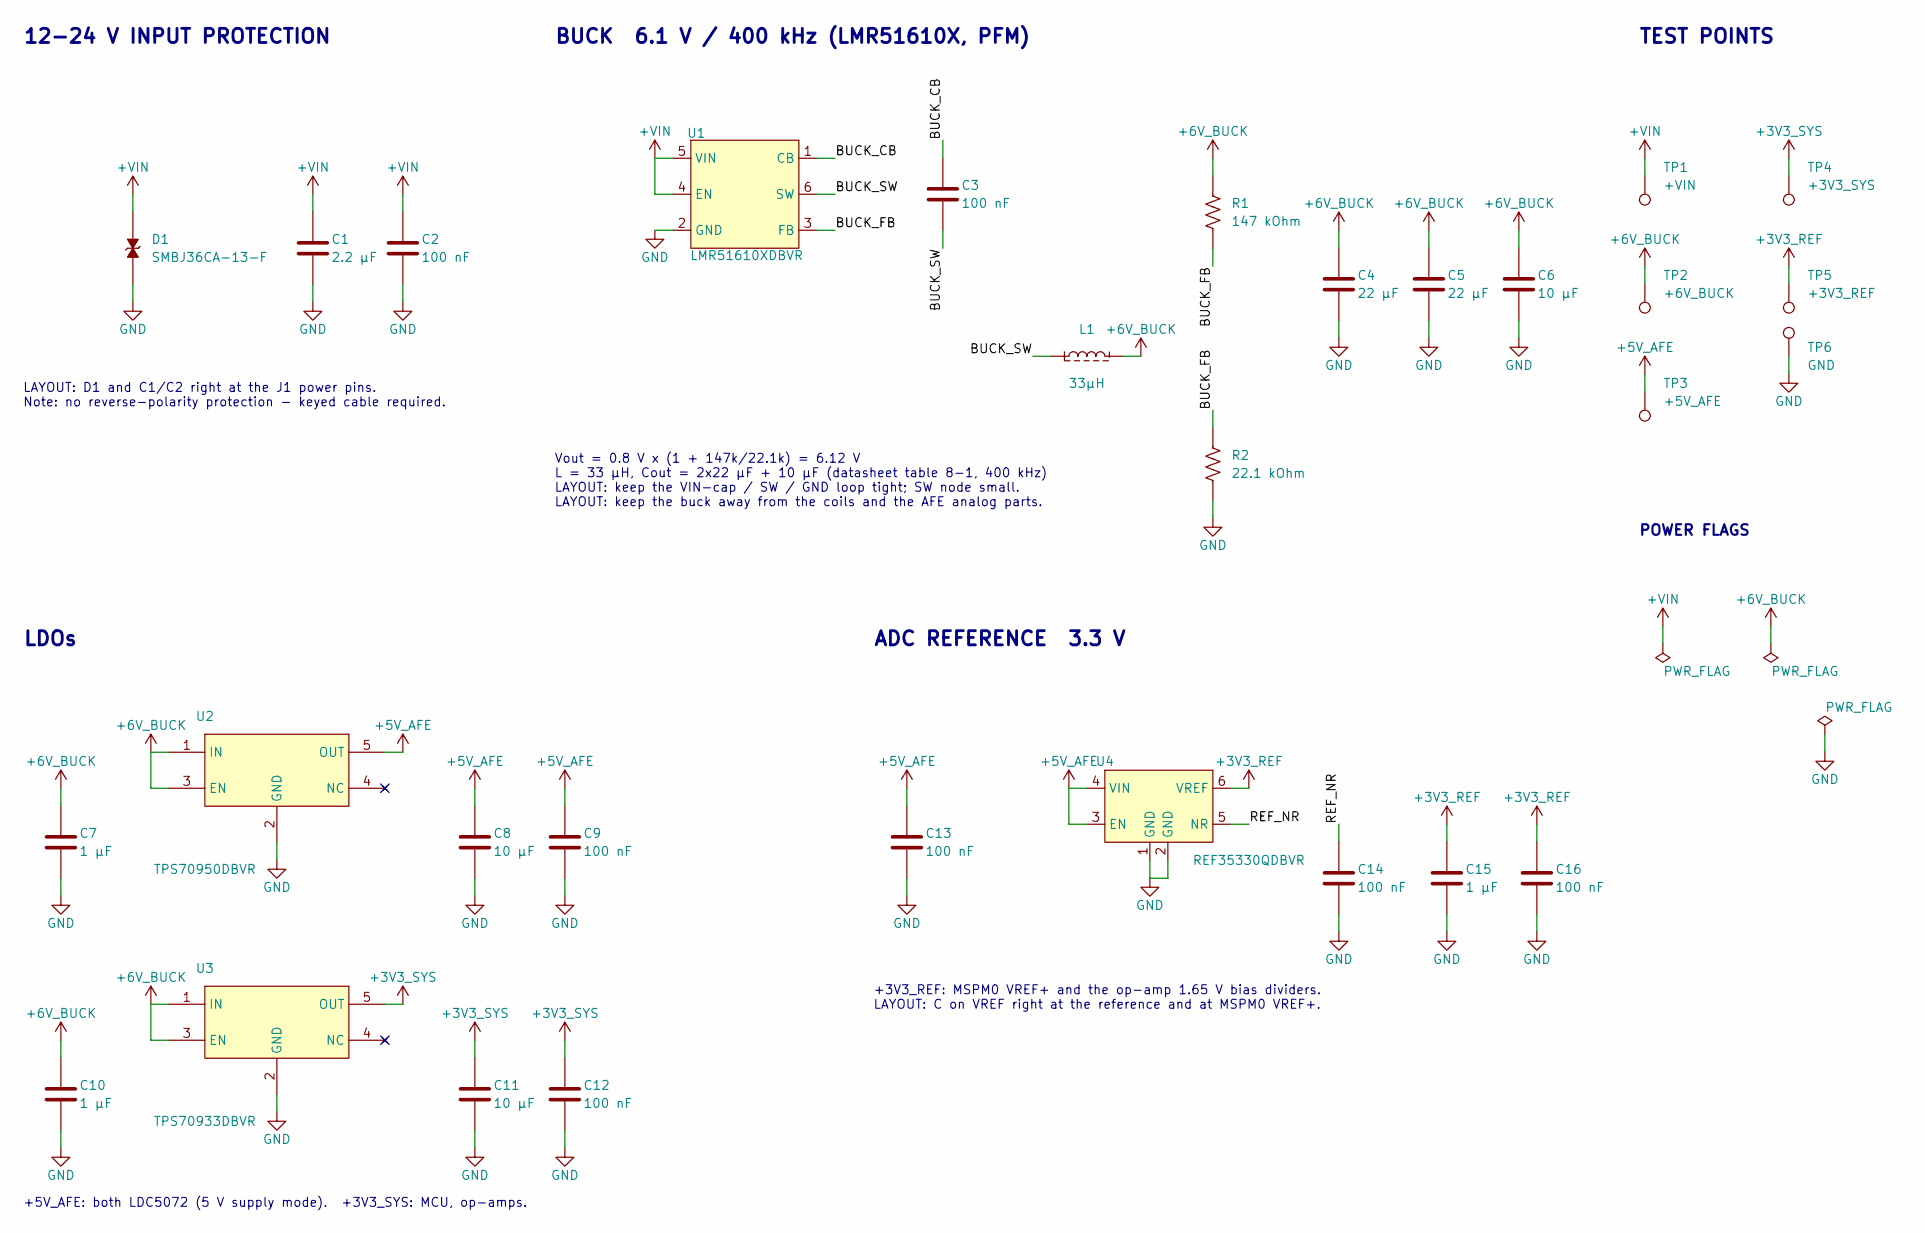
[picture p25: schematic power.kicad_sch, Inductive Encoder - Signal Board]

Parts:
C1: 2.2 µF; 0805_Medium; Tolerance ±20%; Voltage Rating 100V; Digi-Key Number 490-GRM21BD72A225ME01KCT-ND
C2: 100 nF; 0603_Medium; Tolerance ±10%; Voltage Rating 100V; Digi-Key Number 1276-6807-1-ND
C3, C9, C12, C13, C14, C16: 100 nF; 0603_Medium; Tolerance ±10%; Voltage Rating 16V; Digi-Key Number 311-1088-1-ND
C4, C5: 22 µF; 0603_Medium; Tolerance ±20%; Voltage Rating 10V; Digi-Key Number 1276-1274-1-ND
C6, C8, C11: 10 µF; 0603_Medium; Tolerance ±20%; Voltage Rating 25V; Digi-Key Number 1276-1869-1-ND
C7, C10, C15: 1 µF; 0603_Medium; Tolerance ±10%; Voltage Rating 10V; Digi-Key Number 1276-1946-1-ND
D1: SMBJ36CA-13-F; DO-214AA; Breakdown Voltage 40V; Clamping Voltage 58.1V; Digi-Key Number SMBJ36CA-FDICT-ND
L1: 33µH; 6x6mm; Tolerance ±20%; Current Rating 1.22A; Digi-Key Number 732-5537-1-ND
R1: 147 kOhm; 0603_Medium; Tolerance ±1%; Mouser Number 708-RMCF0603FT147K
R2: 22.1 kOhm; 0603_Medium; Tolerance ±1%; Mouser Number 708-RMCF0603FT22K1
TP1: +VIN; Pad_D1.5mm
TP2: +6V_BUCK; Pad_D1.5mm
TP3: +5V_AFE; Pad_D1.5mm
TP4: +3V3_SYS; Pad_D1.5mm
TP5: +3V3_REF; Pad_D1.5mm
TP6: GND; Pad_D1.5mm
U1: LMR51610XDBVR; SOT-23-6; Voltage Input Rating 4V up to 65V; Voltage Output Rating 0.8V up to 28V; Digi-Key Number 296-LMR51610XDBVRCT-ND
U2: TPS70950DBVR; SOT-23-5_DBV; Input Voltage (Max) 30V; Output Voltage 5V; Digi-Key Number 296-35484-1-ND
U3: TPS70933DBVR; SOT-23-5_DBV; Input Voltage (Max) 30V; Output Voltage 3.3V; Digi-Key Number 296-35483-1-ND
U4: REF35330QDBVR; SOT-23-6_DBV; Output Voltage 3.3V; Current Rating 10mA; Digi-Key Number 296-REF35330QDBVRCT-ND

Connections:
+3V3_REF: C15.1, C16.1, TP5.1, U4.6 (VREF); also elsewhere on the board
+3V3_SYS: C11.1, C12.1, TP4.1, U3.5 (OUT); also elsewhere on the board
+5V_AFE: C8.1, C9.1, C13.1, TP3.1, U2.5 (OUT), U4.3 (EN), U4.4 (VIN); also elsewhere on the board
+6V_BUCK: C4.1, C5.1, C6.1, C7.1, C10.1, L1.2, R1.1, TP2.1, U2.1 (IN), U2.3 (EN), U3.1 (IN), U3.3 (EN)
+VIN: C1.1, C2.1, D1.1, TP1.1, U1.4 (EN), U1.5 (VIN); also elsewhere on the board
/Power/BUCK_CB: C3.1, U1.1 (CB)
/Power/BUCK_FB: R1.2, R2.1, U1.3 (FB)
/Power/BUCK_SW: C3.2, L1.1, U1.6 (SW)
/Power/REF_NR: C14.1, U4.5 (NR)
GND: C1.2, C2.2, C4.2, C5.2, C6.2, C7.2, C8.2, C9.2, C10.2, C11.2, C12.2, C13.2, C14.2, C15.2, C16.2, D1.2, R2.2, TP6.1, U1.2 (GND), U2.2 (GND), U3.2 (GND), U4.1 (GND), U4.2 (GND); also elsewhere on the board

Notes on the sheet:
12-24 V INPUT PROTECTION
LAYOUT: D1 and C1/C2 right at the J1 power pins. Note: no reverse-polarity protection - keyed cable required.
BUCK 6.1 V / 400 kHz (LMR51610X, PFM)
Vout = 0.8 V x (1 + 147k/22.1k) = 6.12 V L = 33 µH, Cout = 2x22 µF + 10 µF (datasheet table 8-1, 400 kHz) LAYOUT: keep the VIN-cap / SW / GND loop tight; SW node small. LAYOUT: keep the buck away from the coils and the AFE analog parts.
LDOs
+5V_AFE: both LDC5072 (5 V supply mode). +3V3_SYS: MCU, op-amps.
ADC REFERENCE 3.3 V
+3V3_REF: MSPM0 VREF+ and the op-amp 1.65 V bias dividers. LAYOUT: C on VREF right at the reference and at MSPM0 VREF+.
TEST POINTS
POWER FLAGS

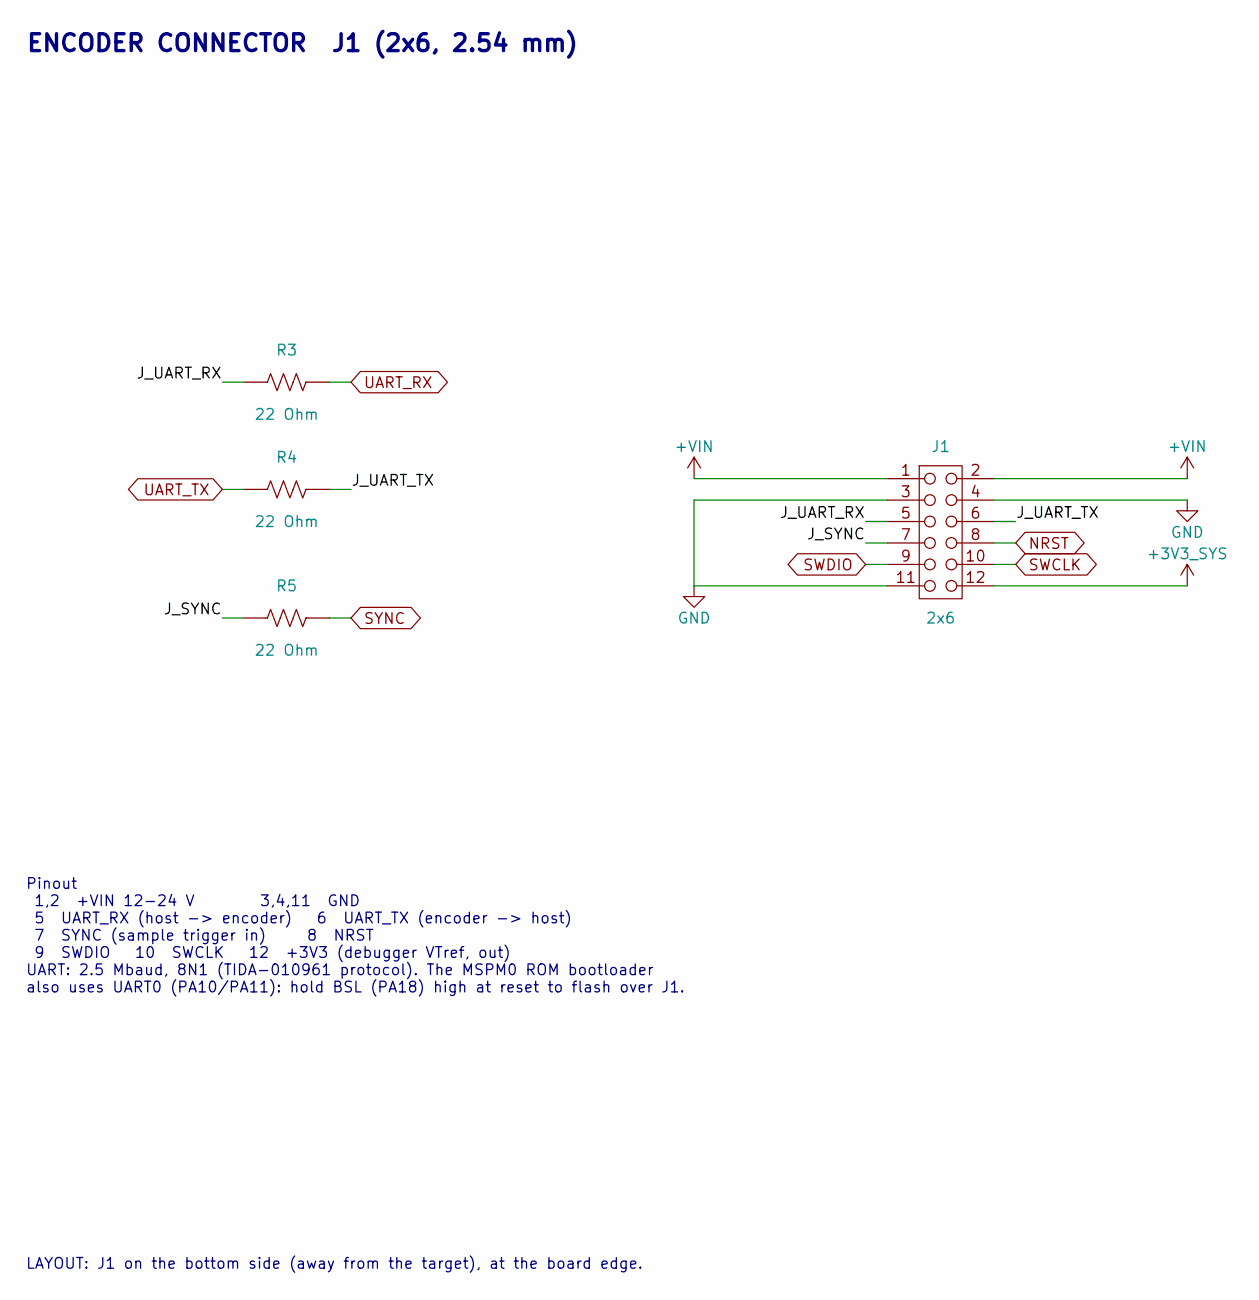
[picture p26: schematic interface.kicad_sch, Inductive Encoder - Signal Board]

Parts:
J1: 2x6; 61301221121; Current Rating 3A; Voltage Rating 250V; Digi-Key Number 732-5297-ND
R3, R4, R5: 22 Ohm; 0603_Medium; Tolerance ±1%; Mouser Number 708-RMCF0603FT22R0

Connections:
+3V3_SYS: J1.12; also elsewhere on the board
+VIN: J1.1, J1.2; also elsewhere on the board
/Interface/J_SYNC: J1.7, R5.1
/Interface/J_UART_RX: J1.5, R3.1
/Interface/J_UART_TX: J1.6, R4.2
GND: J1.3, J1.4, J1.11; also elsewhere on the board
NRST: J1.8; also elsewhere on the board
SWCLK: J1.10; also elsewhere on the board
SWDIO: J1.9; also elsewhere on the board
SYNC: R5.2; also elsewhere on the board
UART_RX: R3.2; also elsewhere on the board
UART_TX: R4.1; also elsewhere on the board

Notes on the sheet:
ENCODER CONNECTOR J1 (2x6, 2.54 mm)
Pinout 1,2 +VIN 12-24 V 3,4,11 GND 5 UART_RX (host -> encoder) 6 UART_TX (encoder -> host) 7 SYNC (sample trigger in) 8 NRST 9 SWDIO 10 SWCLK 12 +3V3 (debugger VTref, out) UART: 2.5 Mbaud, 8N1 (TIDA-010961 protocol). The MSPM0 ROM bootloader also uses UART0 (PA10/PA11): hold BSL (PA18) high at rese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
LAYOUT: J1 on the bottom side (away from the target), at the board edge.

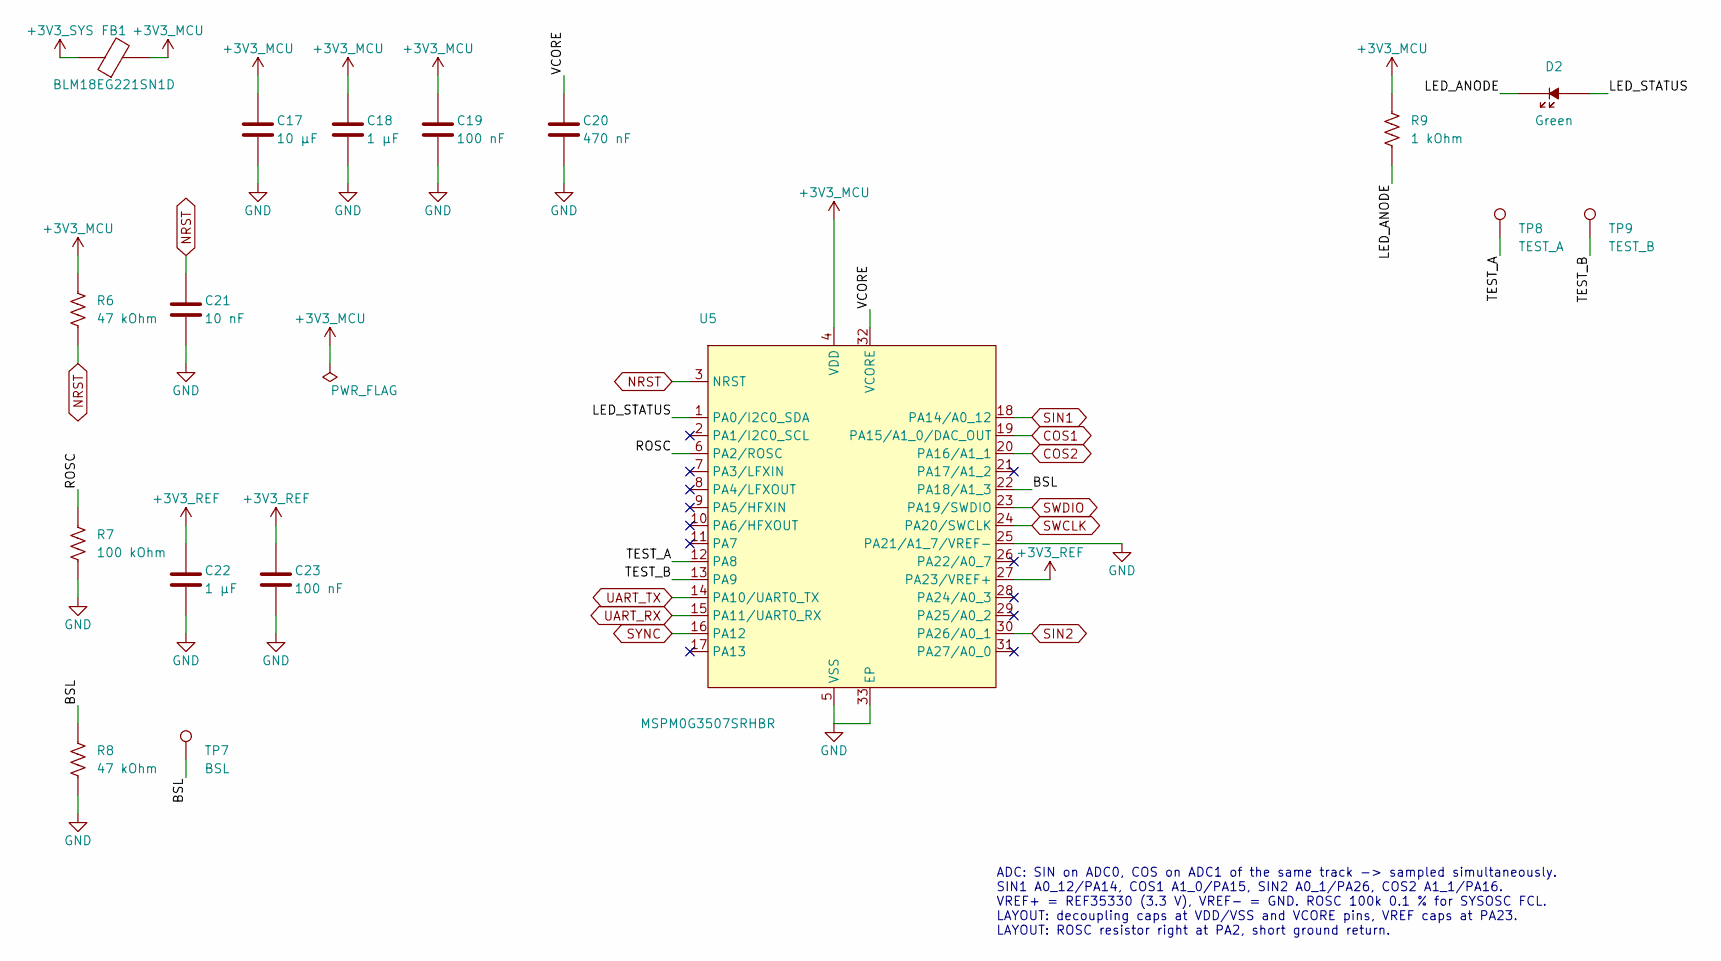
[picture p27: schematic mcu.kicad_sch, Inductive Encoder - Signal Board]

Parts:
C17: 10 µF; 0603_Medium; Tolerance ±20%; Voltage Rating 25V; Digi-Key Number 1276-1869-1-ND
C18, C22: 1 µF; 0603_Medium; Tolerance ±10%; Voltage Rating 10V; Digi-Key Number 1276-1946-1-ND
C19, C23: 100 nF; 0603_Medium; Tolerance ±10%; Voltage Rating 16V; Digi-Key Number 311-1088-1-ND
C20: 470 nF; 0603_Medium; Tolerance ±10%; Voltage Rating 25V; Digi-Key Number 490-3291-1-ND
C21: 10 nF; 0603_Medium; Tolerance ±10%; Voltage Rating 50V; Digi-Key Number 1276-1009-1-ND
D2: Green; 0603_Medium; Forward Voltage 3.2V; Current Rating 20mA; Digi-Key Number 732-4971-1-ND
FB1: BLM18EG221SN1D; 0603_Medium; Current Rating 2A; Digi-Key Number 490-3992-1-ND
R6, R8: 47 kOhm; 0603_Medium; Tolerance ±1%; Mouser Number 708-RMCF0603FT47K0
R7: 100 kOhm; 0603_Medium; Tolerance 0.1%; Mouser Number 603-RT0603BRD07100KL
R9: 1 kOhm; 0603_Medium; Tolerance ±1%; Mouser Number 708-RMCF0603FT1K00
TP7: BSL; Pad_D1.5mm
TP8: TEST_A; Pad_D1.5mm
TP9: TEST_B; Pad_D1.5mm
U5: MSPM0G3507SRHBR; VQFN-32_RHB; Supply Voltage Range 1.62V up to 3.6V; Digi-Key Number 296-MSPM0G3507SRHBRCT-ND

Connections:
+3V3_MCU: C17.1, C18.1, C19.1, FB1.2, R6.1, R9.1, U5.4 (VDD)
+3V3_REF: C22.1, C23.1, U5.27 (PA23/VREF+); also elsewhere on the board
+3V3_SYS: FB1.1; also elsewhere on the board
/MCU/BSL: R8.1, TP7.1, U5.22 (PA18/A1_3)
/MCU/LED_ANODE: D2.2, R9.2
/MCU/LED_STATUS: D2.1, U5.1 (PA0/I2C0_SDA)
/MCU/ROSC: R7.1, U5.6 (PA2/ROSC)
/MCU/TEST_A: TP8.1, U5.12 (PA8)
/MCU/TEST_B: TP9.1, U5.13 (PA9)
/MCU/VCORE: C20.1, U5.32 (VCORE)
COS1: U5.19 (PA15/A1_0/DAC_OUT); also elsewhere on the board
COS2: U5.20 (PA16/A1_1); also elsewhere on the board
GND: C17.2, C18.2, C19.2, C20.2, C21.2, C22.2, C23.2, R7.2, R8.2, U5.5 (VSS), U5.25 (PA21/A1_7/VREF-), U5.33 (EP); also elsewhere on the board
NRST: C21.1, R6.2, U5.3 (NRST); also elsewhere on the board
SIN1: U5.18 (PA14/A0_12); also elsewhere on the board
SIN2: U5.30 (PA26/A0_1); also elsewhere on the board
SWCLK: U5.24 (PA20/SWCLK); also elsewhere on the board
SWDIO: U5.23 (PA19/SWDIO); also elsewhere on the board
SYNC: U5.16 (PA12); also elsewhere on the board
UART_RX: U5.15 (PA11/UART0_RX); also elsewhere on the board
UART_TX: U5.14 (PA10/UART0_TX); also elsewhere on the board

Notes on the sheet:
ADC: SIN on ADC0, COS on ADC1 of the same track -> sampled simultaneously. SIN1 A0_12/PA14, COS1 A1_0/PA15, SIN2 A0_1/PA26, COS2 A1_1/PA16. VREF+ = REF35330 (3.3 V), VREF- = GND. ROSC 100k 0.1 % for SYSOSC FCL. LAYOUT: decoupling caps at VDD/VSS and VCORE pins, VREF caps at PA23. LAYOUT: ROSC resis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

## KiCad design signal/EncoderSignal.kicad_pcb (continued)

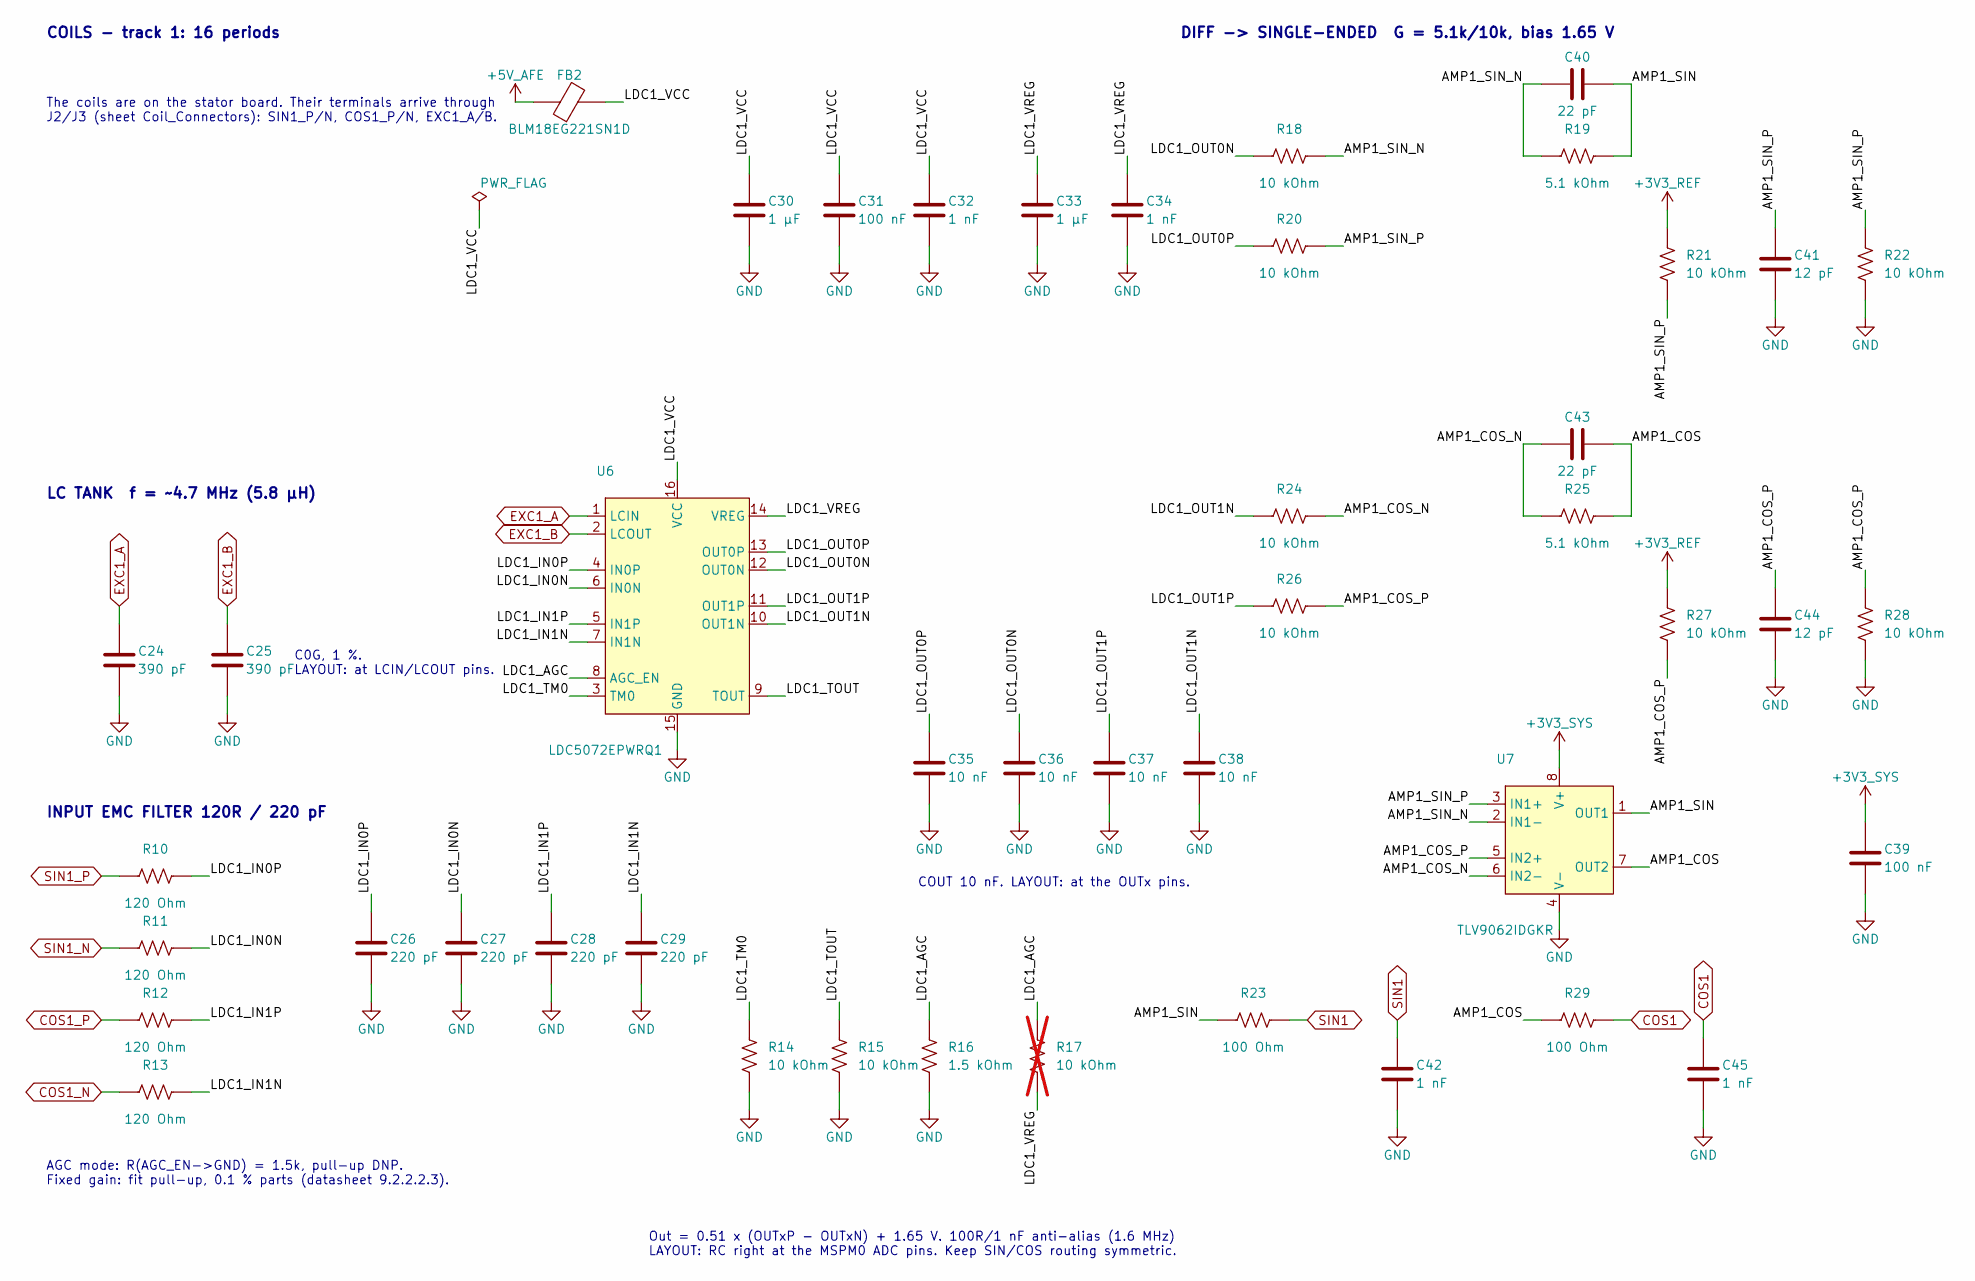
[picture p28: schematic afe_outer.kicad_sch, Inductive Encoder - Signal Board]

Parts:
C24, C25: 390 pF; 0603_Medium; Tolerance ±5%; Voltage Rating 50V; Digi-Key Number 490-8006-1-ND
C26, C27, C28, C29: 220 pF; 0603_Medium; Tolerance ±5%; Voltage Rating 50V; Digi-Key Number 1276-1985-1-ND
C30, C33: 1 µF; 0603_Medium; Tolerance ±10%; Voltage Rating 10V; Digi-Key Number 1276-1946-1-ND
C31, C39: 100 nF; 0603_Medium; Tolerance ±10%; Voltage Rating 16V; Digi-Key Number 311-1088-1-ND
C32, C34, C42, C45: 1 nF; 0603_Medium; Tolerance ±5%; Voltage Rating 100V; Digi-Key Number 490-4772-1-ND
C35, C36, C37, C38: 10 nF; 0603_Medium; Tolerance ±10%; Voltage Rating 50V; Digi-Key Number 1276-1009-1-ND
C40, C43: 22 pF; 0603_Medium; Tolerance ±50%; Voltage Rating 50V; Digi-Key Number 1276-2228-1-ND
C41, C44: 12 pF; 0603_Medium; Tolerance ±5%; Voltage Rating 100V; Digi-Key Number 1276-CL10C120JC81PNCCT-ND
FB2: BLM18EG221SN1D; 0603_Medium; Current Rating 2A; Digi-Key Number 490-3992-1-ND
R10, R11, R12, R13: 120 Ohm; 0603_Medium; Tolerance ±1%; Mouser Number 708-RMCF0603FT120R
R14, R15, R18, R20, R21, R22, R24, R26, R27, R28: 10 kOhm; 0603_Medium; Tolerance ±1%; Mouser Number 603-RC0603FR-0710KL
R16: 1.5 kOhm; 0603_Medium; Tolerance ±1%; Mouser Number 708-RMCF0603FT1K50
R17: 10 kOhm; 0603_Medium; Tolerance ±1%; Mouser Number 603-RC0603FR-0710KL; not fitted
R19, R25: 5.1 kOhm; 0603_Medium; Tolerance ±1%; Mouser Number 708-RMCF0603FT5K10
R23, R29: 100 Ohm; 0603_Medium; Tolerance ±1%; Mouser Number 603-RC0603FR-07100RL
U6: LDC5072EPWRQ1; TSSOP-16_PW; Voltage Rating 3.3V, 5V; Digi-Key Number 296-LDC5072EPWRQ1-ND
U7: TLV9062IDGKR; VSSOP-8_DGK; Supply Voltage Range 1.8V up to 5.5V; Digi-Key Number 296-50012-1-ND

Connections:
+3V3_REF: R21.1, R27.1; also elsewhere on the board
+3V3_SYS: C39.1, U7.8 (V+); also elsewhere on the board
+5V_AFE: FB2.1; also elsewhere on the board
/AFE_Outer/AMP1_COS: C43.2, R25.2, R29.1, U7.7 (OUT2)
/AFE_Outer/AMP1_COS_N: C43.1, R24.2, R25.1, U7.6 (IN2-)
/AFE_Outer/AMP1_COS_P: C44.1, R26.2, R27.2, R28.1, U7.5 (IN2+)
/AFE_Outer/AMP1_SIN: C40.2, R19.2, R23.1, U7.1 (OUT1)
/AFE_Outer/AMP1_SIN_N: C40.1, R18.2, R19.1, U7.2 (IN1-)
/AFE_Outer/AMP1_SIN_P: C41.1, R20.2, R21.2, R22.1, U7.3 (IN1+)
/AFE_Outer/LDC1_AGC: R16.1, R17.2, U6.8 (AGC_EN)
/AFE_Outer/LDC1_IN0N: C27.1, R11.2, U6.6 (IN0N)
/AFE_Outer/LDC1_IN0P: C26.1, R10.2, U6.4 (IN0P)
/AFE_Outer/LDC1_IN1N: C29.1, R13.2, U6.7 (IN1N)
/AFE_Outer/LDC1_IN1P: C28.1, R12.2, U6.5 (IN1P)
/AFE_Outer/LDC1_OUT0N: C36.1, R18.1, U6.12 (OUT0N)
/AFE_Outer/LDC1_OUT0P: C35.1, R20.1, U6.13 (OUT0P)
/AFE_Outer/LDC1_OUT1N: C38.1, R24.1, U6.10 (OUT1N)
/AFE_Outer/LDC1_OUT1P: C37.1, R26.1, U6.11 (OUT1P)
/AFE_Outer/LDC1_TM0: R14.1, U6.3 (TM0)
/AFE_Outer/LDC1_TOUT: R15.1, U6.9 (TOUT)
/AFE_Outer/LDC1_VCC: C30.1, C31.1, C32.1, FB2.2, U6.16 (VCC)
/AFE_Outer/LDC1_VREG: C33.1, C34.1, R17.1, U6.14 (VREG)
COS1: C45.1, R29.2; also elsewhere on the board
COS1_N: R13.1; also elsewhere on the board
COS1_P: R12.1; also elsewhere on the board
EXC1_A: C24.1, U6.1 (LCIN); also elsewhere on the board
EXC1_B: C25.1, U6.2 (LCOUT); also elsewhere on the board
GND: C24.2, C25.2, C26.2, C27.2, C28.2, C29.2, C30.2, C31.2, C32.2, C33.2, C34.2, C35.2, C36.2, C37.2, C38.2, C39.2, C41.2, C42.2, C44.2, C45.2, R14.2, R15.2, R16.2, R22.2, R28.2, U6.15 (GND), U7.4 (V-); also elsewhere on the board
SIN1: C42.1, R23.2; also elsewhere on the board
SIN1_N: R11.1; also elsewhere on the board
SIN1_P: R10.1; also elsewhere on the board

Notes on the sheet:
COILS - track 1: 16 periods
The coils are on the stator board. Their terminals arrive through J2/J3 (sheet Coil_Connectors): SIN1_P/N, COS1_P/N, EXC1_A/B.
LC TANK f = ~4.7 MHz (5.8 µH)
C0G, 1 %. LAYOUT: at LCIN/LCOUT pins.
INPUT EMC FILTER 120R / 220 pF
AGC mode: R(AGC_EN->GND) = 1.5k, pull-up DNP. Fixed gain: fit pull-up, 0.1 % parts (datasheet 9.2.2.2.3).
COUT 10 nF. LAYOUT: at the OUTx pins.
DIFF -> SINGLE-ENDED G = 5.1k/10k, bias 1.65 V
Out = 0.51 x (OUTxP - OUTxN) + 1.65 V. 100R/1 nF anti-alias (1.6 MHz) LAYOUT: RC right at the MSPM0 ADC pins. Keep SIN/COS routing symmetric.

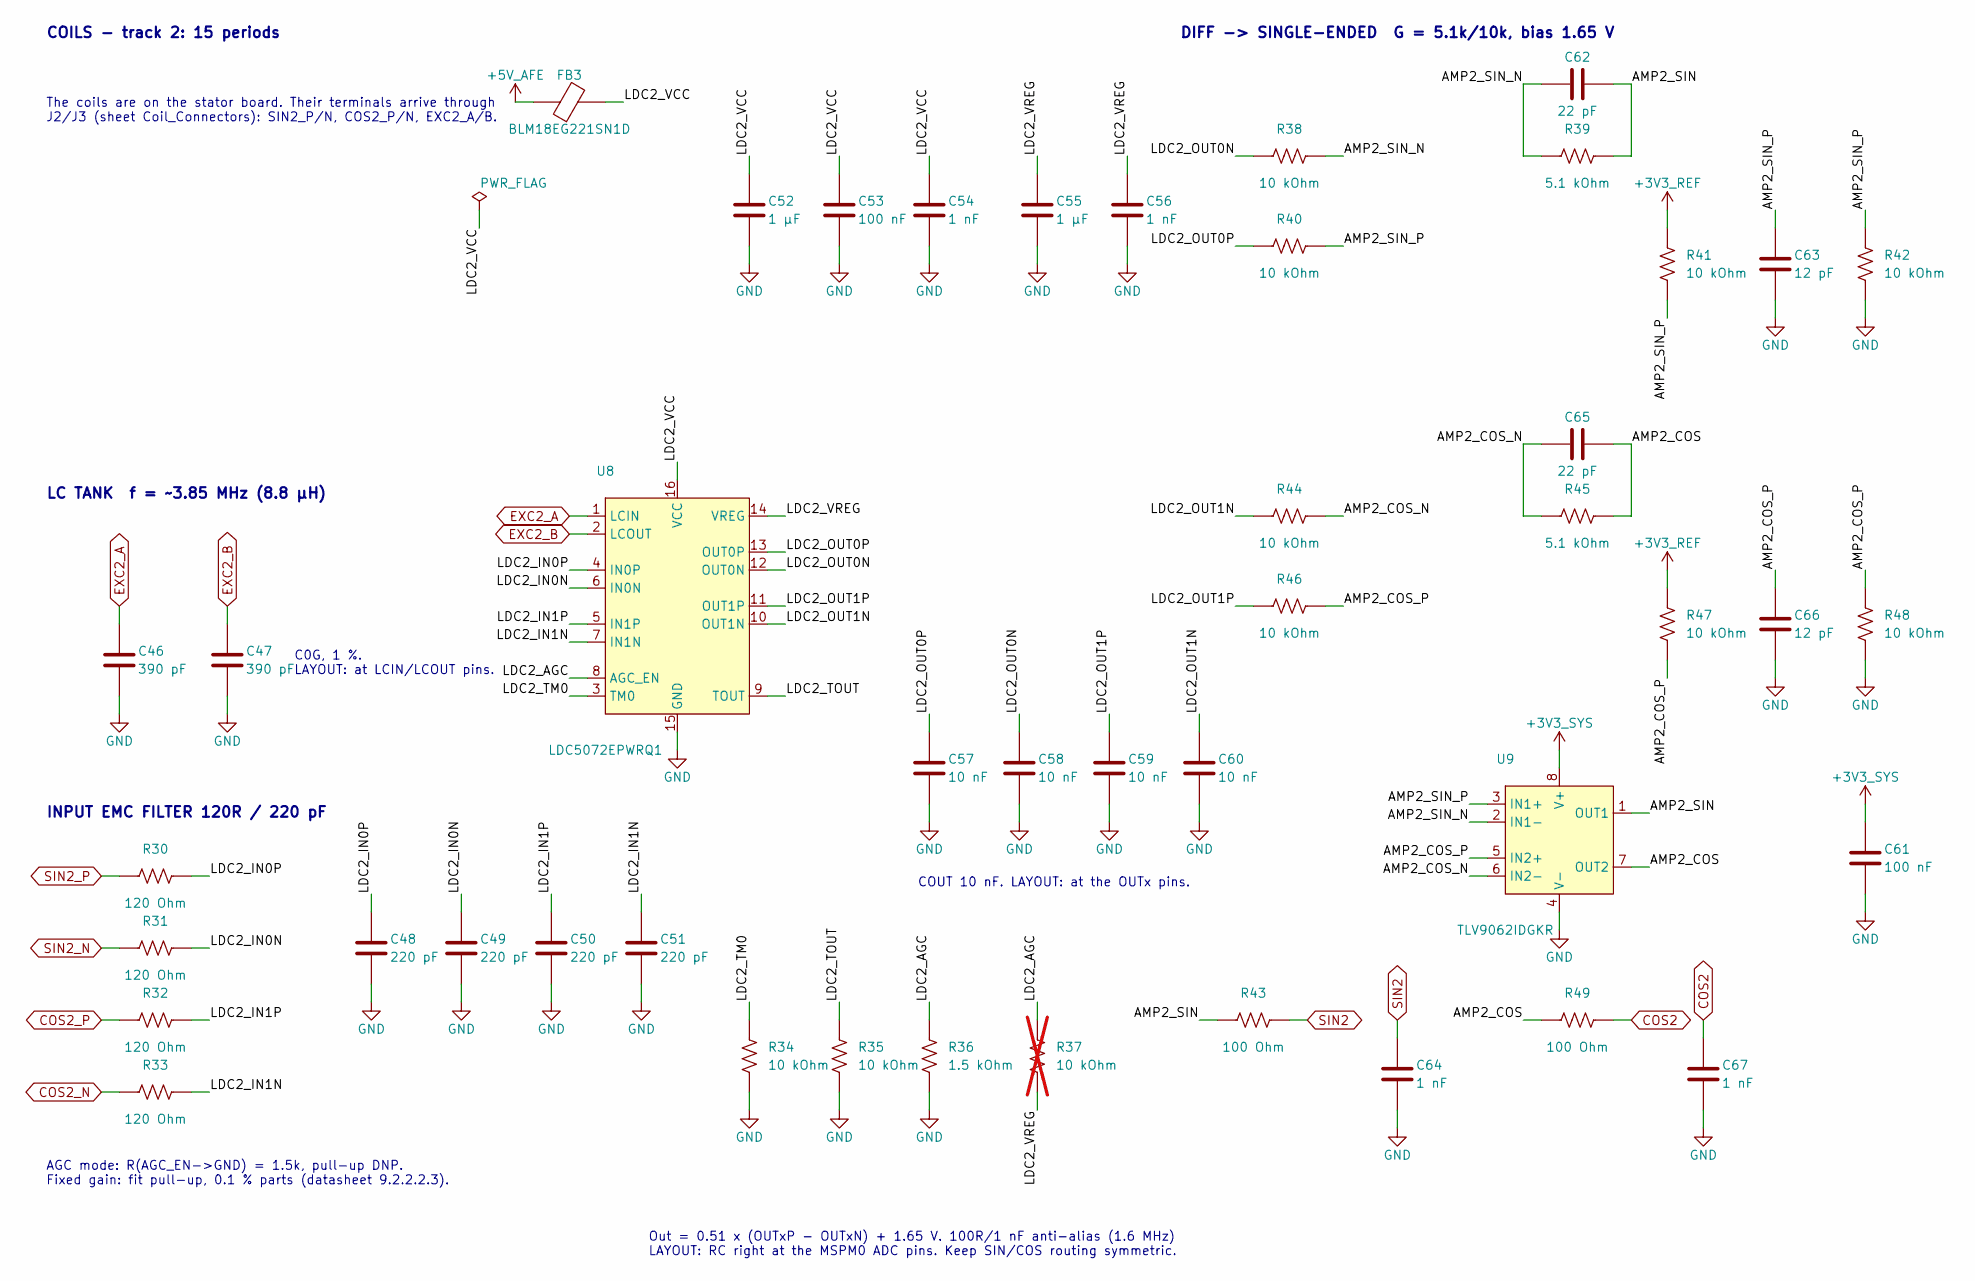
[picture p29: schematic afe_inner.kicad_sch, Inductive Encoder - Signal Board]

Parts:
C46, C47: 390 pF; 0603_Medium; Tolerance ±5%; Voltage Rating 50V; Digi-Key Number 490-8006-1-ND
C48, C49, C50, C51: 220 pF; 0603_Medium; Tolerance ±5%; Voltage Rating 50V; Digi-Key Number 1276-1985-1-ND
C52, C55: 1 µF; 0603_Medium; Tolerance ±10%; Voltage Rating 10V; Digi-Key Number 1276-1946-1-ND
C53, C61: 100 nF; 0603_Medium; Tolerance ±10%; Voltage Rating 16V; Digi-Key Number 311-1088-1-ND
C54, C56, C64, C67: 1 nF; 0603_Medium; Tolerance ±5%; Voltage Rating 100V; Digi-Key Number 490-4772-1-ND
C57, C58, C59, C60: 10 nF; 0603_Medium; Tolerance ±10%; Voltage Rating 50V; Digi-Key Number 1276-1009-1-ND
C62, C65: 22 pF; 0603_Medium; Tolerance ±50%; Voltage Rating 50V; Digi-Key Number 1276-2228-1-ND
C63, C66: 12 pF; 0603_Medium; Tolerance ±5%; Voltage Rating 100V; Digi-Key Number 1276-CL10C120JC81PNCCT-ND
FB3: BLM18EG221SN1D; 0603_Medium; Current Rating 2A; Digi-Key Number 490-3992-1-ND
R30, R31, R32, R33: 120 Ohm; 0603_Medium; Tolerance ±1%; Mouser Number 708-RMCF0603FT120R
R34, R35, R38, R40, R41, R42, R44, R46, R47, R48: 10 kOhm; 0603_Medium; Tolerance ±1%; Mouser Number 603-RC0603FR-0710KL
R36: 1.5 kOhm; 0603_Medium; Tolerance ±1%; Mouser Number 708-RMCF0603FT1K50
R37: 10 kOhm; 0603_Medium; Tolerance ±1%; Mouser Number 603-RC0603FR-0710KL; not fitted
R39, R45: 5.1 kOhm; 0603_Medium; Tolerance ±1%; Mouser Number 708-RMCF0603FT5K10
R43, R49: 100 Ohm; 0603_Medium; Tolerance ±1%; Mouser Number 603-RC0603FR-07100RL
U8: LDC5072EPWRQ1; TSSOP-16_PW; Voltage Rating 3.3V, 5V; Digi-Key Number 296-LDC5072EPWRQ1-ND
U9: TLV9062IDGKR; VSSOP-8_DGK; Supply Voltage Range 1.8V up to 5.5V; Digi-Key Number 296-50012-1-ND

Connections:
+3V3_REF: R41.1, R47.1; also elsewhere on the board
+3V3_SYS: C61.1, U9.8 (V+); also elsewhere on the board
+5V_AFE: FB3.1; also elsewhere on the board
/AFE_Inner/AMP2_COS: C65.2, R45.2, R49.1, U9.7 (OUT2)
/AFE_Inner/AMP2_COS_N: C65.1, R44.2, R45.1, U9.6 (IN2-)
/AFE_Inner/AMP2_COS_P: C66.1, R46.2, R47.2, R48.1, U9.5 (IN2+)
/AFE_Inner/AMP2_SIN: C62.2, R39.2, R43.1, U9.1 (OUT1)
/AFE_Inner/AMP2_SIN_N: C62.1, R38.2, R39.1, U9.2 (IN1-)
/AFE_Inner/AMP2_SIN_P: C63.1, R40.2, R41.2, R42.1, U9.3 (IN1+)
/AFE_Inner/LDC2_AGC: R36.1, R37.2, U8.8 (AGC_EN)
/AFE_Inner/LDC2_IN0N: C49.1, R31.2, U8.6 (IN0N)
/AFE_Inner/LDC2_IN0P: C48.1, R30.2, U8.4 (IN0P)
/AFE_Inner/LDC2_IN1N: C51.1, R33.2, U8.7 (IN1N)
/AFE_Inner/LDC2_IN1P: C50.1, R32.2, U8.5 (IN1P)
/AFE_Inner/LDC2_OUT0N: C58.1, R38.1, U8.12 (OUT0N)
/AFE_Inner/LDC2_OUT0P: C57.1, R40.1, U8.13 (OUT0P)
/AFE_Inner/LDC2_OUT1N: C60.1, R44.1, U8.10 (OUT1N)
/AFE_Inner/LDC2_OUT1P: C59.1, R46.1, U8.11 (OUT1P)
/AFE_Inner/LDC2_TM0: R34.1, U8.3 (TM0)
/AFE_Inner/LDC2_TOUT: R35.1, U8.9 (TOUT)
/AFE_Inner/LDC2_VCC: C52.1, C53.1, C54.1, FB3.2, U8.16 (VCC)
/AFE_Inner/LDC2_VREG: C55.1, C56.1, R37.1, U8.14 (VREG)
COS2: C67.1, R49.2; also elsewhere on the board
COS2_N: R33.1; also elsewhere on the board
COS2_P: R32.1; also elsewhere on the board
EXC2_A: C46.1, U8.1 (LCIN); also elsewhere on the board
EXC2_B: C47.1, U8.2 (LCOUT); also elsewhere on the board
GND: C46.2, C47.2, C48.2, C49.2, C50.2, C51.2, C52.2, C53.2, C54.2, C55.2, C56.2, C57.2, C58.2, C59.2, C60.2, C61.2, C63.2, C64.2, C66.2, C67.2, R34.2, R35.2, R36.2, R42.2, R48.2, U8.15 (GND), U9.4 (V-); also elsewhere on the board
SIN2: C64.1, R43.2; also elsewhere on the board
SIN2_N: R31.1; also elsewhere on the board
SIN2_P: R30.1; also elsewhere on the board

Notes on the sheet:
COILS - track 2: 15 periods
The coils are on the stator board. Their terminals arrive through J2/J3 (sheet Coil_Connectors): SIN2_P/N, COS2_P/N, EXC2_A/B.
LC TANK f = ~3.85 MHz (8.8 µH)
C0G, 1 %. LAYOUT: at LCIN/LCOUT pins.
INPUT EMC FILTER 120R / 220 pF
AGC mode: R(AGC_EN->GND) = 1.5k, pull-up DNP. Fixed gain: fit pull-up, 0.1 % parts (datasheet 9.2.2.2.3).
COUT 10 nF. LAYOUT: at the OUTx pins.
DIFF -> SINGLE-ENDED G = 5.1k/10k, bias 1.65 V
Out = 0.51 x (OUTxP - OUTxN) + 1.65 V. 100R/1 nF anti-alias (1.6 MHz) LAYOUT: RC right at the MSPM0 ADC pins. Keep SIN/COS routing symmetric.

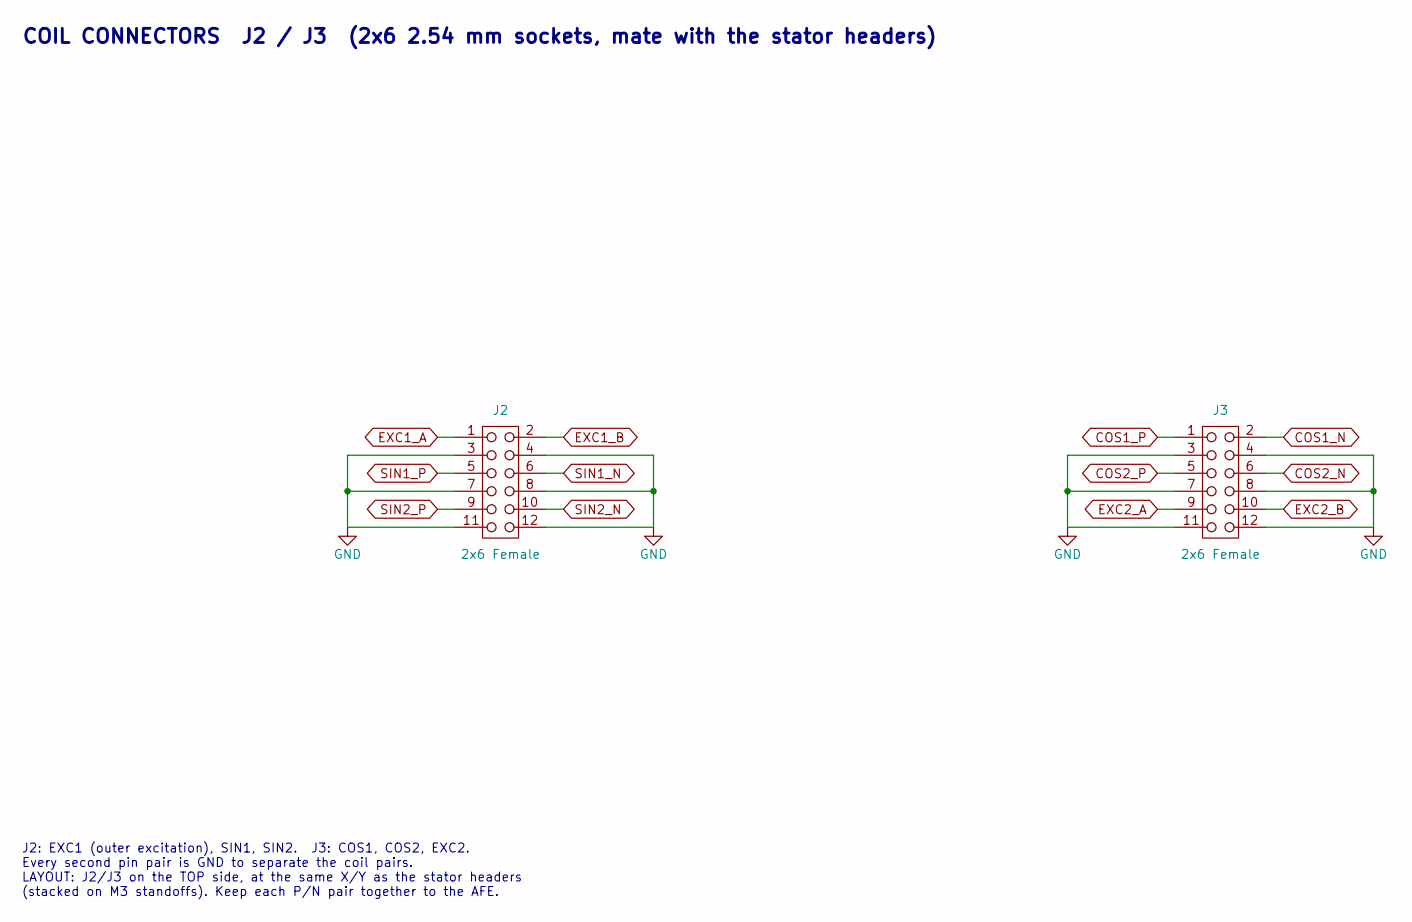
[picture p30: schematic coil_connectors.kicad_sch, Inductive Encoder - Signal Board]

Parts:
J2, J3: 2x6 Female; 61301221821; Current Rating 3A; Voltage Rating 250V; Digi-Key Number 732-61301221821-ND

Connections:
COS1_N: J3.2; also elsewhere on the board
COS1_P: J3.1; also elsewhere on the board
COS2_N: J3.6; also elsewhere on the board
COS2_P: J3.5; also elsewhere on the board
EXC1_A: J2.1; also elsewhere on the board
EXC1_B: J2.2; also elsewhere on the board
EXC2_A: J3.9; also elsewhere on the board
EXC2_B: J3.10; also elsewhere on the board
GND: J2.3, J2.4, J2.7, J2.8, J2.11, J2.12, J3.3, J3.4, J3.7, J3.8, J3.11, J3.12; also elsewhere on the board
SIN1_N: J2.6; also elsewhere on the board
SIN1_P: J2.5; also elsewhere on the board
SIN2_N: J2.10; also elsewhere on the board
SIN2_P: J2.9; also elsewhere on the board

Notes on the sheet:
COIL CONNECTORS J2 / J3 (2x6 2.54 mm sockets, mate with the stator headers)
J2: EXC1 (outer excitation), SIN1, SIN2. J3: COS1, COS2, EXC2. Every second pin pair is GND to separate the coil pairs. LAYOUT: J2/J3 on the TOP side, at the same X/Y as the stator headers (stacked on M3 standoffs). Keep each P/N pair together to the AFE.

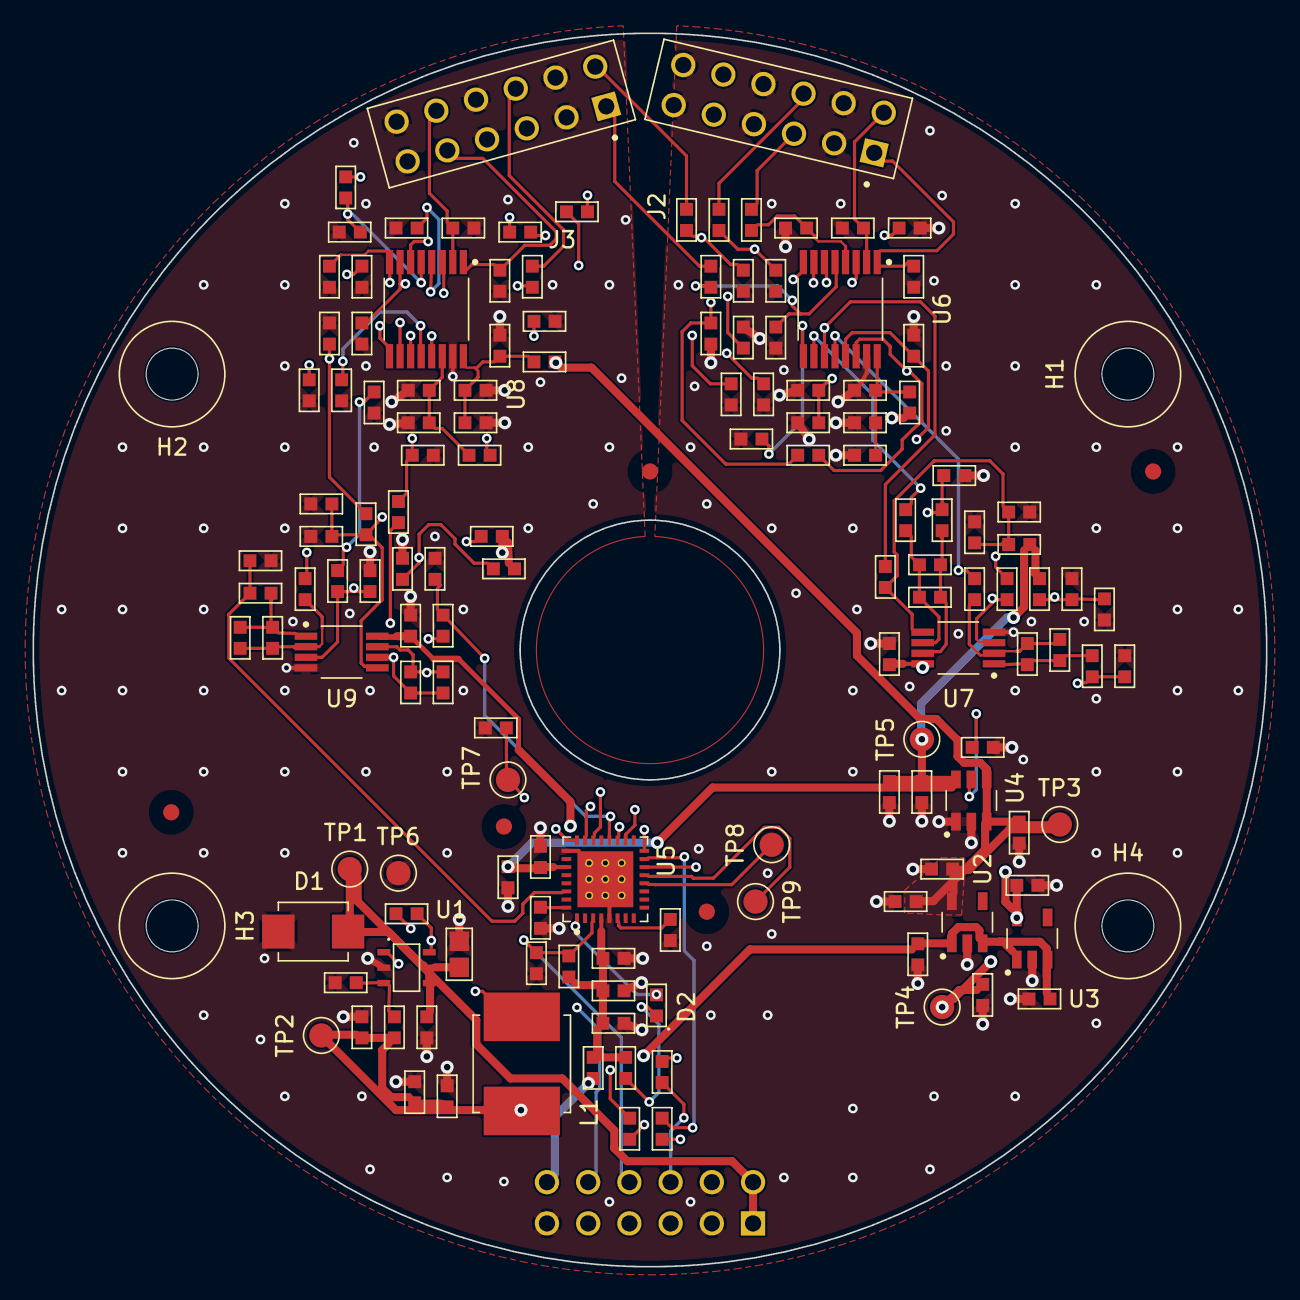
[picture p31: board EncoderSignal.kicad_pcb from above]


Board: 4 copper layers, 76.0 x 76.0 mm, 154 parts (3 on the bottom side), 81 nets.

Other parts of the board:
FID1, FID2, FID3, FID4, FID5: Fiducial_1mm_Mask2mm
G1: METUPowerLab_Logo_30mm
G2: METUPowerLab_QRCode_13.3mm
H1, H2, H3, H4: M3_NPTH

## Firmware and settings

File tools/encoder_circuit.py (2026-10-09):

"""Inductive encoder circuit (TIDA-010961 architecture, METU PowerLab parts).

Run:  python -I tools/encoder_circuit.py      (writes the .kicad_sch files of both boards)

Two boards, stacked on M3 standoffs (same 76 mm outline and holes):
  Stator  (InductiveEncoder.kicad_sch, project root): coils as net ties + J2/J3
          male 2x6 headers carrying the coil terminals (GND rows between pairs)
  Signal  (signal/EncoderSignal.kicad_sch): everything below + J2/J3 sockets

Signal-board sheets
  1 Overview      root page: description, key specs, coil render, sheet blocks
  2 Power         12-24 V in -> LMR51610 buck (6.1 V) -> TPS70950 (5 V AFE)
                  + TPS70933 (3.3 V) ; REF35330 3.3 V ADC reference
  3 Interface     2x6 header: supply, UART, SYNC, SWD, NRST
  4 MCU           MSPM0G3507 (2x 12-bit ADC sampled simultaneously)
  5 AFE outer     LDC5072 + TLV9062 for the 16-period track (SIN1/COS1/EXC1)
  6 AFE inner     LDC5072 + TLV9062 for the 15-period track (SIN2/COS2/EXC2)
  7 Coil conn.    J2/J3 sockets from the stator
"""
import os
import sys

sys.path.insert(0, os.path.dirname(os.path.abspath(__file__)))
from schgen import Design  # noqa: E402

ROOT = os.path.dirname(os.path.dirname(os.path.abspath(__file__)))

# ---------------------------------------------------------------------------
# library parts
# ---------------------------------------------------------------------------
R_LIB = "METUPowerLab_Resistors_ChipResistors"
C_LIB = "METUPowerLab_Capacitors_Ceramics_SurfaceMounts"
R_FP = R_LIB + ":0603_Medium"
C_FP = C_LIB + ":0603_Medium"
SYM = {
    "LDC5072": ("METUPowerLab_Sensors_Encoders", "LDC5072EPWRQ1"),
    "MSPM0": ("METUPowerLab_Microcontrollers_MSPM0", "MSPM0G3507SRHBR"),
    "TLV9062": ("METUPowerLab_Amplifiers_OpAmps", "TLV9062IDGKR"),
    "REF35": ("METUPowerLab_References_VoltageReferences", "REF35330QDBVR"),
    "LDO33": ("METUPowerLab_Regulators_LDOs", "TPS70933DBVR"),
    "LDO50": ("METUPowerLab_Regulators_LDOs", "TPS70950DBVR"),
    "BUCK": ("METUPowerLab_Regulators_BuckConverters", "LMR51610XDBVR"),
    "HDR2x6": ("METUPowerLab_Connectors_Headers", "2x6"),
    "SKT2x6": ("METUPowerLab_Connectors_Headers", "2x6 Female"),
    "NETTIE": ("METUPowerLab_NetTies_SurfaceMounts", "NetTie_2_0.5mm"),
    "TP": ("METUPowerLab_TestPoints_SurfaceMounts", "TestPoint_Pad"),
    "TVS": ("METUPowerLab_Diodes_TVSDiodes", "SMBJ36CA-13-F"),
    "L33U": ("METUPowerLab_Inductors_SurfaceMounts", "33µH"),
    "FB": ("METUPowerLab_CircuitProtections_FerriteBeads", "BLM18EG221SN1D"),
    "LED_G": ("METUPowerLab_LEDs_SurfaceMounts", "Green "),
}
CAP_FP = {"0603": C_FP, "0805": C_LIB + ":0805_Medium", "1210": C_LIB + ":1210_Medium"}
CAP = {  # value -> (symbol name, package)
    "100 nF": ("100 nF", "0603"), "1 µF": ("1 µF 10V", "0603"), "10 µF": ("10 µF 25V", "0603"),
    "22 µF": ("22 µF", "0603"), "1 nF": ("1 nF ", "0603"), "10 nF": ("10 nF", "0603"),
    "220 pF": ("220 pF", "0603"), "390 pF": ("390 pF", "0603"), "470 nF": ("470 nF", "0603"),
    "22 pF": ("22 pF", "0603"), "12 pF": ("12 pF", "0603"), "100 nF 100V": ("100 nF 100V", "0603"),
    "2.2 µF 100V": ("2.2 µF 100V 0805", "0805"),
}
GLOBALS = ["SIN1", "COS1", "SIN2", "COS2", "UART_TX", "UART_RX", "SYNC", "NRST", "SWDIO", "SWCLK",
           # coil nets: global so the names match the generated coil copper exactly
           "SIN1_P", "SIN1_N", "COS1_P", "COS1_N", "EXC1_A", "EXC1_B",
           "SIN2_P", "SIN2_N", "COS2_P", "COS2_N", "EXC2_A", "EXC2_B"]

D = Design(os.path.join(ROOT, "signal"), "Inductive Encoder - Signal Board", "A", "2026-10-09",
           "METU PowerLab", GLOBALS, project="EncoderSignal")
DS = Design(ROOT, "Inductive Encoder - Stator (coils)", "A", "2026-10-09", "METU PowerLab", GLOBALS,
            project="InductiveEncoder")
# board-to-board coil connectors (same pinout on stator header and signal-board socket)
COIL_CONN = {
    "J2": {"1": "EXC1_A", "2": "EXC1_B", "5": "SIN1_P", "6": "SIN1_N", "9": "SIN2_P", "10": "SIN2_N"},
    "J3": {"1": "COS1_P", "2": "COS1_N", "5": "COS2_P", "6": "COS2_N", "9": "EXC2_A", "10": "EXC2_B"},
}
for _pins in COIL_CONN.values():
    _pins.update({k: "GND" for k in ("3", "4", "7", "8", "11", "12")})
_ref = {}


def ref(prefix):
    _ref[prefix] = _ref.get(prefix, 0) + 1
    return f"{prefix}{_ref[prefix]}"


def R(S, val, at, n1, n2, rot=0, dnp=False, sym=None):
    """Resistor; rot 0: pin1 left/pin2 right, rot 270: pin1 top/pin2 bottom."""
    return S.part(ref("R"), R_LIB, sym or val, at, rot, {"1": n1, "2": n2}, fp=R_FP, dnp=dnp)


def C(S, val, at, n1, n2, rot=0):
    sym, pkg = CAP[val]
    return S.part(ref("C"), C_LIB, sym, at, rot, {"1": n1, "2": n2}, fp=CAP_FP[pkg])


def decap_row(S, x0, y, rail, vals, dx=12.7):
    for i, v in enumerate(vals):
        C(S, v, (x0 + i * dx, y), rail, "GND")


def TP(S, net, at, label=None):
    return S.part(ref("TP"), *SYM["TP"], at, 180 if net.startswith("+") else 0, {"1": net},
                  fp="METUPowerLab_TestPoints_SurfaceMounts:Pad_D1.5mm", value=net)


# ---------------------------------------------------------------------------
# Sheet 2: Power
# ---------------------------------------------------------------------------
P = D.sheet("Power", "power.kicad_sch", "Power supply: 12-24 V input, buck, LDOs, ADC reference")
P.text("12-24 V INPUT PROTECTION", (20, 25), 2, True)
P.part(ref("D"), *SYM["TVS"], (35, 55), 270, {"1": "+VIN", "2": "GND"})
C(P, "2.2 µF 100V", (60, 55), "+VIN", "GND")
C(P, "100 nF 100V", (72.7, 55), "+VIN", "GND")
P.text("LAYOUT: D1 and C1/C2 right at the J1 power pins.\n"
       "Note: no reverse-polarity protection - keyed cable required.", (20, 75))

P.text("BUCK  6.1 V / 400 kHz (LMR51610X, PFM)", (95, 25), 2, True)
P.part(ref("U"), *SYM["BUCK"], (115, 55), 0,
       {"5": "+VIN", "4": "+VIN", "2": "GND", "1": "BUCK_CB", "6": "BUCK_SW", "3": "BUCK_FB"})
C(P, "100 nF", (149.86, 48.26), "BUCK_CB", "BUCK_SW")
P.part(ref("L"), *SYM["L33U"], (170.18, 71.12), 0, {"1": "BUCK_SW", "2": "+6V_BUCK"})
R(P, "147 kOhm", (187.96, 50.8), "+6V_BUCK", "BUCK_FB", rot=270)
R(P, "22.1 kOhm", (187.96, 86.36), "BUCK_FB", "GND", rot=270)
decap_row(P, 205.74, 60.96, "+6V_BUCK", ["22 µF", "22 µF", "10 µF"])
P.text("Vout = 0.8 V x (1 + 147k/22.1k) = 6.12 V\n"
       "L = 33 µH, Cout = 2x22 µF + 10 µF (datasheet table 8-1, 400 kHz)\n"
       "LAYOUT: keep the VIN-cap / SW / GND loop tight; SW node small.\n"
       "LAYOUT: keep the buck away from the coils and the AFE analog parts.", (95, 85))

P.text("LDOs", (20, 110), 2, True)
P.part(ref("U"), *SYM["LDO50"], (45, 135), 0, {"1": "+6V_BUCK", "3": "+6V_BUCK", "2": "GND",
                                                  "5": "+5V_AFE", "4": "NC"})
C(P, "1 µF", (25, 140), "+6V_BUCK", "GND")
decap_row(P, 85, 140, "+5V_AFE", ["10 µF", "100 nF"])
P.part(ref("U"), *SYM["LDO33"], (45, 170), 0, {"1": "+6V_BUCK", "3": "+6V_BUCK", "2": "GND",
                                                  "5": "+3V3_SYS", "4": "NC"})
C(P, "1 µF", (25, 175), "+6V_BUCK", "GND")
decap_row(P, 85, 175, "+3V3_SYS", ["10 µF", "100 nF"])
P.text("+5V_AFE: both LDC5072 (5 V supply mode).  +3V3_SYS: MCU, op-amps.", (20, 190))

P.text("ADC REFERENCE  3.3 V", (140, 110), 2, True)
P.part(ref("U"), *SYM["REF35"], (180, 135), 0, val_at=(12.7, 7.62), pins=
       {"4": "+5V_AFE", "3": "+5V_AFE", "1": "GND", "2": "GND", "5": "REF_NR", "6": "+3V3_REF"})
C(P, "100 nF", (145, 140), "+5V_AFE", "GND")
C(P, "100 nF", (205, 145), "REF_NR", "GND")
decap_row(P, 220, 145, "+3V3_REF", ["1 µF", "100 nF"])
P.text("+3V3_REF: MSPM0 VREF+ and the op-amp 1.65 V bias dividers.\n"
       "LAYOUT: C on VREF right at the reference and at MSPM0 VREF+.", (140, 160))

P.text("TEST POINTS", (248, 25), 2, True)
for i, net in enumerate(["+VIN", "+6V_BUCK", "+5V_AFE"]):
    TP(P, net, (250, 45 + i * 15))
for i, net in enumerate(["+3V3_SYS", "+3V3_REF"]):
    TP(P, net, (270, 45 + i * 15))
TP(P, "GND", (270, 72))
P.text("POWER FLAGS", (248, 95), 1.5, True)
for i, net in enumerate(["+VIN", "+6V_BUCK"]):
    P.part(f"#FLG0{i + 1}", "METUPowerLab_Schematic_PowerSymbols", "PWR_FLAG", (252 + i * 15, 112), 180,
           {"1": net})
P.part("#FLG03", "METUPowerLab_Schematic_PowerSymbols", "PWR_FLAG", (275, 125), 0, {"1": "GND"})

# ---------------------------------------------------------------------------
# Sheet 3: Interface
# ---------------------------------------------------------------------------
I = D.sheet("Interface", "interface.kicad_sch", "Host interface connector")
I.text("ENCODER CONNECTOR  J1 (2x6, 2.54 mm)", (30, 30), 2, True)
I.part(ref("J"), *SYM["HDR2x6"], (140, 90), 0, pstub=22.86, pins={
    "1": "+VIN", "2": "+VIN", "3": "GND", "4": "GND", "5": "J_UART_RX", "6": "J_UART_TX",
    "7": "J_SYNC", "8": "NRST", "9": "SWDIO", "10": "SWCLK", "11": "GND", "12": "+3V3_SYS"})
R(I, "22 Ohm", (60, 70), "J_UART_RX", "UART_RX")
R(I, "22 Ohm", (60, 85), "UART_TX", "J_UART_TX")
R(I, "22 Ohm", (60, 100), "J_SYNC", "SYNC")
I.text("Pinout\n 1,2  +VIN 12-24 V        3,4,11  GND\n 5  UART_RX (host -> encoder)   6  UART_TX (encoder -> host)\n"
       " 7  SYNC (sample trigger in)     8  NRST\n 9  SWDIO   10  SWCLK   12  +3V3 (debugger VTref, out)\n"
       "UART: 2.5 Mbaud, 8N1 (TIDA-010961 protocol). The MSPM0 ROM bootloader\n"
       "also uses UART0 (PA10/PA11): hold BSL (PA18) high at reset to flash over J1.",
       (30, 130))
I.text("LAYOUT: J1 on the bottom side (away from the target), at the board edge.", (30, 175))

# ---------------------------------------------------------------------------
# Sheet 4: MCU
# ---------------------------------------------------------------------------
M = D.sheet("MCU", "mcu.kicad_sch", "MSPM0G3507 angle computation")
M.part(ref("U"), *SYM["MSPM0"], (140, 100), 0, pstub={"25": 15.24, "27": 5.08, "4": 15.24}, pins={
    "4": "+3V3_MCU", "5": "GND", "32": "VCORE", "3": "NRST", "6": "ROSC",
    "27": "+3V3_REF", "25": "GND",                     # VREF+ / VREF-
    # SIN1 on A0_12/PA14 (pin 18, next to COS1): the outer AFE is on the right side of
    # the board; A0_0/PA27 (pin 31) sat on the far side of the MCU
    "18": "SIN1", "19": "COS1", "30": "SIN2", "20": "COS2",   # A0_12 / A1_0 / A0_1 / A1_1
    "14": "UART_TX", "15": "UART_RX", "16": "SYNC", "23": "SWDIO", "24": "SWCLK",
    "1": "LED_STATUS", "12": "TEST_A", "13": "TEST_B", "22": "BSL",
    "2": "NC", "7": "NC", "8": "NC", "9": "NC", "10": "NC", "11": "NC", "17": "NC", "31": "NC",
    "21": "NC", "26": "NC", "28": "NC", "29": "NC", "33": "GND"})
M.part(ref("FB"), *SYM["FB"], (35, 35), 0, {"1": "+3V3_SYS", "2": "+3V3_MCU"},
       fp="METUPowerLab_CircuitProtections_FerriteBeads:0603_Medium")
decap_row(M, 55, 45, "+3V3_MCU", ["10 µF", "1 µF", "100 nF"])
C(M, "470 nF", (100, 45), "VCORE", "GND")
R(M, "47 kOhm", (30, 70), "+3V3_MCU", "NRST", rot=270)
C(M, "10 nF", (45, 70), "NRST", "GND")
R(M, "100 kOhm 0.1%", (30, 105), "ROSC", "GND", rot=270)
decap_row(M, 45, 110, "+3V3_REF", ["1 µF", "100 nF"])
R(M, "47 kOhm", (30, 135), "BSL", "GND", rot=270)
TP(M, "BSL", (45, 135))
R(M, "1 kOhm", (215, 45), "+3V3_MCU", "LED_ANODE", rot=270)
M.part(ref("D"), *SYM["LED_G"], (240, 40), 180, {"1": "LED_STATUS", "2": "LED_ANODE"},
       fp="METUPowerLab_LEDs_SurfaceMounts:0603_Medium")
TP(M, "TEST_A", (230, 60))
TP(M, "TEST_B", (245, 60))
M.part("#FLG04", "METUPowerLab_Schematic_PowerSymbols", "PWR_FLAG", (65, 80), 180, {"1": "+3V3_MCU"})
M.text("ADC: SIN on ADC0, COS on ADC1 of the same track -> sampled simultaneously.\n"
       "SIN1 A0_12/PA14, COS1 A1_0/PA15, SIN2 A0_1/PA26, COS2 A1_1/PA16.\n"
       "VREF+ = REF35330 (3.3 V), VREF- = GND. ROSC 100k 0.1 % for SYSOSC FCL.\n"
       "LAYOUT: decoupling caps at VDD/VSS and VCORE pins, VREF caps at PA23.\n"
       "LAYOUT: ROSC resistor right at PA2, short ground return.", (160, 150))

# ---------------------------------------------------------------------------
# Sheets 5/6: AFE (one per track)
# ---------------------------------------------------------------------------
def afe(name, file, k, periods, f_osc):
    A = D.sheet(name, file, f"LDC5072 front end, {periods}-period track")
    n = lambda s: s.replace("#", str(k))  # noqa: E731
    A.text(n(f"COILS - track #: {periods} periods"), (15, 20), 1.5, True)
    A.text(n("The coils are on the stator board. Their terminals arrive through\n"
             "J2/J3 (sheet Coil_Connectors): SIN#_P/N, COS#_P/N, EXC#_A/B."), (15, 30))
    # tank
    A.text(n(f"LC TANK  f = {f_osc}"), (15, 85), 1.5, True)
    C(A, "390 pF", (25, 110), n("EXC#_A"), "GND")
    C(A, "390 pF", (40, 110), n("EXC#_B"), "GND")
    A.text("C0G, 1 %.\nLAYOUT: at LCIN/LCOUT pins.", (50, 108))
    # receive filters
    A.text("INPUT EMC FILTER 120R / 220 pF", (15, 130), 1.5, True)
    for i, (coil, pin) in enumerate([("SIN#_P", "IN0P"), ("SIN#_N", "IN0N"), ("COS#_P", "IN1P"), ("COS#_N", "IN1N")]):
        y = 140 + i * 10
        R(A, "120 Ohm", (30, y), n(coil), n(f"LDC#_{pin}"))
        C(A, "220 pF", (62 + i * 12.7, 150), n(f"LDC#_{pin}"), "GND")
    # LDC5072
    A.part(ref("U"), *SYM["LDC5072"], (105, 100), 0, {
        "1": n("EXC#_A"), "2": n("EXC#_B"), "3": n("LDC#_TM0"), "9": n("LDC#_TOUT"),
        "4": n("LDC#_IN0P"), "6": n("LDC#_IN0N"), "5": n("LDC#_IN1P"), "7": n("LDC#_IN1N"),
        "8": n("LDC#_AGC"), "16": n("LDC#_VCC"), "15": "GND", "14": n("LDC#_VREG"),
        "13": n("LDC#_OUT0P"), "12": n("LDC#_OUT0N"), "11": n("LDC#_OUT1P"), "10": n("LDC#_OUT1N")})
    A.part(ref("FB"), *SYM["FB"], (90, 30), 0, {"1": "+5V_AFE", "2": n("LDC#_VCC")},
           fp="METUPowerLab_CircuitProtections_FerriteBeads:0603_Medium")
    decap_row(A, 114.3, 45.72, n("LDC#_VCC"), ["1 µF", "100 nF", "1 nF"])
    A.part(f"#FLG0{4 + k}", "METUPowerLab_Schematic_PowerSymbols", "PWR_FLAG", (75, 45), 0,
           {"1": n("LDC#_VCC")})
    decap_row(A, 154.94, 45.72, n("LDC#_VREG"), ["1 µF", "1 nF"])
    R(A, "10 kOhm", (115, 165), n("LDC#_TM0"), "GND", rot=270)
    R(A, "10 kOhm", (127, 165), n("LDC#_TOUT"), "GND", rot=270)
    R(A, "1.5 kOhm", (140, 165), n("LDC#_AGC"), "GND", rot=270)
    R(A, "10 kOhm", (155, 165), n("LDC#_VREG"), n("LDC#_AGC"), rot=90, dnp=True)   # rot 90: pin 1 bottom
    A.text("AGC mode: R(AGC_EN->GND) = 1.5k, pull-up DNP.\nFixed gain: fit pull-up, 0.1 % parts (datasheet 9.2.2.2.3).",
           (15, 180))
    for i, out in enumerate(["OUT0P", "OUT0N", "OUT1P", "OUT1N"]):
        C(A, "10 nF", (139.7 + i * 12.7, 124.46), n(f"LDC#_{out}"), "GND")
    A.text("COUT 10 nF. LAYOUT: at the OUTx pins.", (138, 140))
    # differential -> single ended, gain 0.51, 1.65 V bias
    A.text("DIFF -> SINGLE-ENDED  G = 5.1k/10k, bias 1.65 V", (175, 20), 1.5, True)
    A.part(ref("U"), *SYM["TLV9062"], (228.6, 134.62), 0, {
        "8": "+3V3_SYS", "4": "GND",
        "1": n("AMP#_SIN"), "2": n("AMP#_SIN_N"), "3": n("AMP#_SIN_P"),
        "7": n("AMP#_COS"), "6": n("AMP#_COS_N"), "5": n("AMP#_COS_P")})
    C(A, "100 nF", (271.78, 137.16), "+3V3_SYS", "GND")
    for j, (sig, op, on) in enumerate([("SIN", "OUT0P", "OUT0N"), ("COS", "OUT1P", "OUT1N")]):
        y0 = 38.1 + j * 50.8        # keep the R/R/C creation order: it sets the references
        R(A, "10 kOhm", (190.5, y0), n(f"LDC#_{on}"), n(f"AMP#_{sig}_N"))
        R(A, "5.1 kOhm", (231.14, y0), n(f"AMP#_{sig}_N"), n(f"AMP#_{sig}"))
        C(A, "22 pF", (231.14, y0 - 10.16), n(f"AMP#_{sig}_N"), n(f"AMP#_{sig}"), rot=90)
        R(A, "10 kOhm", (190.5, y0 + 12.7), n(f"LDC#_{op}"), n(f"AMP#_{sig}_P"))
        R(A, "10 kOhm", (243.84, y0 + 15.24), "+3V3_REF", n(f"AMP#_{sig}_P"), rot=270)
        R(A, "10 kOhm", (271.78, y0 + 15.24), n(f"AMP#_{sig}_P"), "GND", rot=270)
        C(A, "12 pF", (259.08, y0 + 15.24), n(f"AMP#_{sig}_P"), "GND")
        R(A, "100 Ohm", (185 + j * 45, 160), n(f"AMP#_{sig}"), n(f"{sig}#"))
        C(A, "1 nF", (205 + j * 45, 168), n(f"{sig}#"), "GND")
    A.text("Out = 0.51 x (OUTxP - OUTxN) + 1.65 V. 100R/1 nF anti-alias (1.6 MHz)\n"
           "LAYOUT: RC right at the MSPM0 ADC pins. Keep SIN/COS routing symmetric.", (100, 190))
    return A


afe("AFE_Outer", "afe_outer.kicad_sch", 1, 16, "~4.7 MHz (5.8 µH)")
afe("AFE_Inner", "afe_inner.kicad_sch", 2, 15, "~3.85 MHz (8.8 µH)")

# ---------------------------------------------------------------------------
# Sheet 7: coil connectors (signal board side)
# ---------------------------------------------------------------------------
K = D.sheet("Coil_Connectors", "coil_connectors.kicad_sch", "Board-to-board sockets from the stator")
K.text("COIL CONNECTORS  J2 / J3  (2x6 2.54 mm sockets, mate with the stator headers)", (20, 25), 2, True)
K.part("J2", *SYM["SKT2x6"], (90, 90), 0, pstub=15.24, pins=COIL_CONN["J2"])
K.part("J3", *SYM["SKT2x6"], (190, 90), 0, pstub=15.24, pins=COIL_CONN["J3"])
K.text("J2: EXC1 (outer excitation), SIN1, SIN2.  J3: COS1, COS2, EXC2.\n"
       "Every second pin pair is GND to separate the coil pairs.\n"
       "LAYOUT: J2/J3 on the TOP side, at the same X/Y as the stator headers\n"
       "(stacked on M3 standoffs). Keep each P/N pair together to the AFE.", (20, 140))

# ---------------------------------------------------------------------------
# Root page
# ---------------------------------------------------------------------------
Rt = D.root
Rt.text("INDUCTIVE ENCODER - SIGNAL BOARD  (rev A)", (15, 15), 3, True)
Rt.text("Contactless absolute rotary encoder after TI TIDA-010961 (TIDUFF8).\n"
        "Dual-track Nonius coils (16 / 15 periods) on a 4-layer Ø76 mm stator, Ø56 mm\n"
        "copper target disc, 0.5 mm air gap. Two LDC5072-Q1 AFEs excite the coils and\n"
        "demodulate sin/cos; MSPM0G3507 samples both ADCs simultaneously and computes\n"
        "the absolute angle (Nonius sector + fine angle), sent over UART.", (15, 24), 1.5)
Rt.text("KEY SPECS\n"
        "Input: 12-24 V (4-65 V buck), ~0.5 W\n"
        "Coil area: Ø58 mm, shaft hole Ø16 mm\n"
        "Tracks: 16 periods (outer), 15 periods (inner)\n"
        "Excitation: ~4.7 MHz (outer), ~3.85 MHz (inner)\n"
        "MCU: MSPM0G3507, 2x 12-bit 4 Msps ADC\n"
        "Interface: UART 2.5 Mbaud, SYNC input, SWD\n"
        "Target accuracy (TI ref.): < 0.04°, 16+ ENOB", (15, 55), 1.5)
Rt.image(os.path.join(ROOT, "docs", "coils_preview_small.png"), (215, 75), 1.0)
Rt.text("Stator coils (generated)", (200, 97), 1.27)
blocks = [(P, (20, 120)), (I, (65, 120)), (M, (110, 120)), (D.sheets[3], (20, 155)), (D.sheets[4], (65, 155)),
          (K, (110, 155))]
for sh, at in blocks:
    D.place_sheet(sh, at, (35, 20))
Rt.text("REVISION HISTORY\nA  2026-10-09  first issue", (160, 160), 1.27)

# ---------------------------------------------------------------------------
# Stator board: coils + coil connectors
# ---------------------------------------------------------------------------
S = DS.sheet("Coils", "coils.kicad_sch", "PCB coils (net ties) and coil connectors")
S.text("COILS  (PCB copper generated by tools/coilgen.py)", (20, 20), 2, True)
for i, (refn, p, m, what) in enumerate([("NT1", "SIN1_P", "SIN1_N", "outer SIN receive coil, 16 periods"),
                                        ("NT2", "COS1_P", "COS1_N", "outer COS receive coil, 16 periods"),
                                        ("NT3", "EXC1_A", "EXC1_B", "outer excitation ring, 5.8 uH"),
                                        ("NT4", "SIN2_P", "SIN2_N", "inner SIN receive coil, 15 periods"),
                                        ("NT5", "COS2_P", "COS2_N", "inner COS receive coil, 15 periods"),
                                        ("NT6", "EXC2_A", "EXC2_B", "inner excitation ring, 8.8 uH")]):
    S.part(refn, *SYM["NETTIE"], (40, 40 + i * 15), 0, {"1": p, "2": m}, value=f"COIL_{p.split('_')[0]}")
    S.text(what, (75, 38 + i * 15))
S.text("Each coil is drawn as a net tie: the coil copper and both of its leads carry the\n"
       "_P/_A net; the tie at the end of the N lead joins the _N/_B net.\n"
       "LAYOUT: net ties at the coil lead exits; coil terminals are hand-routed\n"
       "(tools/stator_layout.py) because both lead ends belong to the same net.", (20, 140))
S.part("J2", *SYM["HDR2x6"], (170, 70), 0, pstub=15.24, pins=COIL_CONN["J2"])
S.part("J3", *SYM["HDR2x6"], (250, 70), 0, pstub=15.24, pins=COIL_CONN["J3"])
S.part("#FLG01", "METUPowerLab_Schematic_PowerSymbols", "PWR_FLAG", (210, 120), 0, {"1": "GND"})
S.text("J2/J3: 2x6 2.54 mm male headers on the BOTTOM side at the coil exits.\n"
       "Mate with the signal-board sockets J2/J3 (same pinout). GND comes from\n"
       "the signal board; it only shields the pairs inside the connector.", (150, 140))
St = DS.root
St.text("INDUCTIVE ENCODER - STATOR (COIL) BOARD  (rev A)", (15, 15), 3, True)
St.text("4-layer 76 mm stator with the dual-track Nonius coils (16 / 15 periods,\n"
        "58 mm coil area, 16 mm shaft hole). The target disc rotates 0.5 mm above L1.\n"
        "The signal board (signal/EncoderSignal) stacks behind it on M3 standoffs and\n"
        "plugs into J2/J3. No GND copper on this board: a closed ring around the\n"
        "excitation coils would act as a shorted turn.", (15, 24), 1.5)
St.image(os.path.join(ROOT, "docs", "coils_preview_small.png"), (215, 75), 1.0)
DS.place_sheet(S, (20, 120), (35, 20))
St.text("REVISION HISTORY\nA  2026-10-09  first issue", (110, 160), 1.27)

if __name__ == "__main__":
    os.makedirs(os.path.join(ROOT, "signal"), exist_ok=True)
    D.write()
    DS.write()
